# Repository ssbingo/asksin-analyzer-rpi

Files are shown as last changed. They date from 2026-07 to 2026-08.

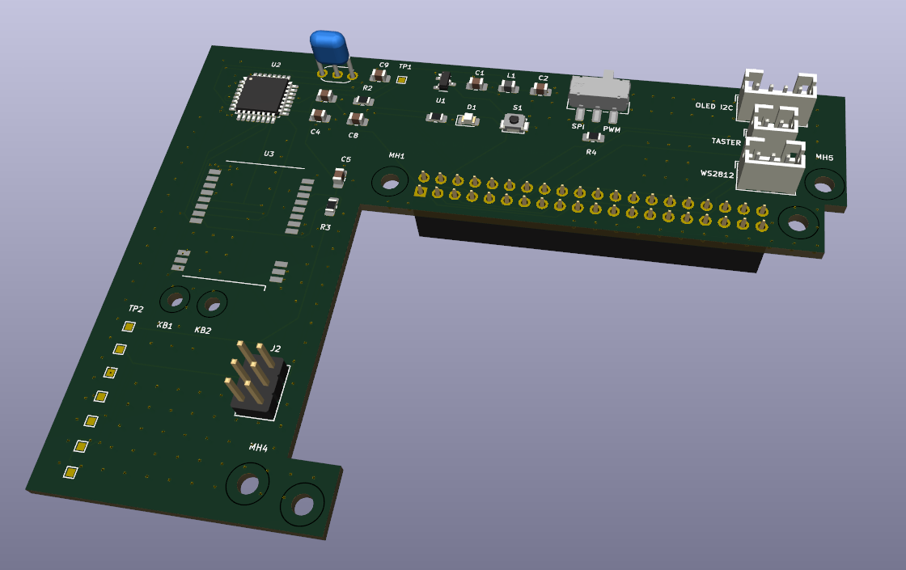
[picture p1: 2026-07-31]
docs/handbuch/img/deckblatt.png

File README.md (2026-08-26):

# AskSin-Analyzer

Ein dauerhaft laufender **Funkanalyzer für Homematic (BidCoS, 868 MHz)** auf
Raspberry-Pi-Basis: eine eigene Empfängerplatine hört den Funkverkehr passiv
mit, ein Node.js-Dienst auf dem Pi wertet aus (Duty-Cycle, RSSI,
Telegrammraten), eine Web-UI zeigt an, und ein ioBroker-Adapter spiegelt die
Ergebnisse in die Hausautomation. Mehrere Geräte an verschiedenen Standorten
im Haus sind ausdrücklich vorgesehen.

📖 **[Handbuch (PDF)](docs/handbuch/AskSin-Analyzer-Handbuch.pdf)** — die
anfängertaugliche Schritt-für-Schritt-Anleitung vom Platinenbestellen bis zum
laufenden Gerät.

> ### ⚠️ Platinen mit „HW v0.0.1" im Bestückungsdruck
>
> Bei diesen ist die 2×20-Buchse J1 gespiegelt — direkt aufgesteckt liegt
> jedes Pad auf dem falschen Pi-Pin (5 V auf 3,3 V, Masse auf GPIOs).
> **Nicht ohne den [J1-Rettungsadapter](hardware/kicad/adapter/README.md)
> aufstecken und einschalten.** Mit ihm sind sie voll funktionsfähig.
> Ab **v0.2.0** ist der Fehler behoben, und die Platine liegt neben dem Pi
> statt über dessen Buchsen.

## Projektstand

| Baustein | Stand |
| --- | --- |
| **Hardware v0.2.0** (L-Platine neben dem Pi) | ✅ **in Produktion** (31.07.2026) — DRC/ERC 0/0, 26 Fertigungsprüfungen bestanden |
| Fertigungsdaten (Gerber, BOM, CPL, JLCPCB) | ✅ [`hardware/kicad/fab/`](hardware/kicad/fab/) + Archiv |
| J1-Rettungsadapter für die Chargen v0.0.1 | ✅ [`hardware/kicad/adapter/`](hardware/kicad/adapter/README.md) |
| Firmware | ✅ abgewandelte Fassung des `AskSinSniffer328P` (jp112sdl) — läuft auch ohne Funkmodul und meldet dessen Fehlen, [eigenes Repo](https://github.com/ssbingo/asksin-sniffer-firmware); Prüfwerkzeuge in [`firmware/`](firmware/README.md) |
| Firmware, erweiterte Fassung | 🔨 gebaut, wartet auf die Platine — eigenes Repo [`asksin-sniffer-firmware`](https://github.com/ssbingo/asksin-sniffer-firmware): Versionsauskunft, Folgenummer, Prüfsumme, CC1101-Selbsttest. Im Auslieferungszustand Zeichen für Zeichen wie das Original |
| Mitschnitt der Funkstrecke | ✅ Grundlinie vor Firmware-Änderungen, Schalter unter *Wartung* (F1) |
| Core: Parser + Duty-Cycle | ✅ fertig ([`core/`](core/)) |
| Core: Serial-Ingest, SQLite, CCU-Namen, Analyzer | ✅ fertig verdrahtet (M2–M4) |
| Core: REST-API inkl. XS-Kompat-Endpunkten | ✅ fertig, 108 Unit-Tests gesamt (M5) |
| Web-UI (Nachbau, eigener Code, MIT) | ✅ fertig: Vue 3 + ECharts, vom Core ausgeliefert (M5.5) |
| Demo-Modus (simulierte Anlage) | ✅ fertig, Schalter in den Einstellungen (v0.0.3) |
| Update-Pfade (Core-Self-Update, 328P-Flash) | ✅ fertig (M7.5, v0.0.4) |
| Netzwerkeinstellungen über die Web-UI | ✅ gebaut (M7.6) — Praxistest auf dem Pi ausstehend |
| Status-LED + OLED integriert | ✅ Software fertig (M11) — Hardware-Test steht aus ([`docs/status-led-oled.md`](docs/status-led-oled.md)) |
| Einkaufsführer Zubehör (README + Handbuch) | 📋 geplant (M12, [`docs/einkaufsfuehrer.md`](docs/einkaufsfuehrer.md)) |
| Verbund: 5 Analyzer als Gesamtsystem | ✅ komplett: Dashboard, Matrix+Dedup, Flotten-Update, Langzeitdaten nach InfluxDB (M9.1–M9.5, [`docs/verbund.md`](docs/verbund.md)) |
| Langzeitdaten vor Ort (InfluxDB + Grafana) | ✅ optional auf dem Master: Ein-Klick-Einrichtung, acht fertige Grafana-Ansichten, vier Alarme (M14) |
| Bootmedium | SSD ab Pi 4; **der Pi 3 läuft von SD-Karte** (Netzwerk am USB-Bus, nur USB 2.0) |
| CCU-Verbindungstest mit Diagnose | ✅ nennt die Geräteanzahl, unterscheidet sechs Fehlerursachen und blendet bei fehlender Systemvariable die Einrichtung ein ([`ccu/`](ccu/README.md)) |
| Alarmziele: ioBroker, E-Mail, Telegram | ✅ in der WebUI einstellbar, mit Testversand und deutlichen Fehlermeldungen (M14.2) |
| Versionsabhängigkeit Analyzer ↔ Adapter | ✅ beide Seiten weisen sie aus **und prüfen sie** (M15) |
| Protokoll und Absturzsuche (Tab „Wartung“) | ✅ fertig (M13): Stufen, Tagesrotation, Download, Systemjournal ([`docs/protokoll.md`](docs/protokoll.md)) |
| ioBroker-Adapter | 🔨 Grundgerüst steht (M6, eigenes Repo [`ioBroker.asksinanalyzer-rpi`](https://github.com/ssbingo/ioBroker.asksinanalyzer-rpi), MIT, mehrinstanzfähig) |

## Installation auf dem Raspberry Pi

Ein Aufruf installiert und konfiguriert alles (Details: [`deploy/README.md`](deploy/README.md)):

```bash
curl -fsSL https://raw.githubusercontent.com/ssbingo/asksin-analyzer-rpi/main/install.sh | sudo bash
```

## Aufbau des Repositories

```
hardware/                 Platine, Bestelllisten, Setup-Skripte
├── README.md             vollständige Hardware-Spezifikation
├── bestellliste-reichelt.md
├── setup-uart.sh         richtet den Pi-UART ein (Pi 3/4/5)
├── 99-asksin-analyzer.rules   udev: fester Gerätename
├── 3d-druck/             Druckvorlagen 19″-Einbaurahmen (folgen nach Testdruck)
├── datasheets/           Ebyte-E07-Serienspezifikation
└── kicad/                KiCad-9-Projekt, generiert & maschinell geprüft
    ├── generate_*.py     Schaltplan, Layout, Symbole, Footprints, BOM/CPL
    ├── autoroute.py      Freerouting-Anbindung
    ├── rebuild.py       baut die Platine neu, bis alle Prüfungen sauber sind
    ├── adapter/         J1-Rettungsadapter für die Chargen v0.0.1
    ├── fab/             Gerber, Bohrdaten, BOM, CPL, PDFs
    └── AskSin-Analyzer-V3-fertigung.zip   Upload-Paket
core/                     Node.js/TypeScript-Analysedienst
webui/                    Web-UI-Nachbau (Vue 3 + ECharts, MIT)
deploy/                   systemd-Unit, Beispielkonfig, CLI-Wrapper
install.sh / update.sh    Ein-Befehl-Installation und -Update auf dem Pi
docs/
├── serial-protocol.md    das serielle Telegrammformat, verifiziert
├── raspberry-pi-uart.md  UART-Konfiguration Pi 3/4/5
├── webui-und-updates.md  API-Vertrag der Web-UI, Update-Pfade, Lizenzlage
├── verbund.md            Phase M9: fünf Analyzer als Gesamtsystem (Föderation)
├── protokoll.md          Phase M13: Protokoll, Systemjournal, Absturzsuche
├── status-led-oled.md    Phase M11: Status-LED (PWM/SPI) und OLED
└── handbuch/             das Handbuch (HTML-Quelle, Bilder, PDF)
reference/                Originalprojekte (nicht eingecheckt — siehe unten)
```

## Die Kernentscheidungen in einem Absatz

Die Funkseite bleibt beim bewährten Gespann **ATmega328P + CC1101** mit der
unveränderten `AskSinSniffer328P`-Firmware — kein Fork, wer will flasht die
Original-HEX. Die Platine ist ein **L-förmiger** Aufsatz, der auf den
durchgeschleiften Header des PoE-HAT gesteckt wird; der Streifen liegt
**parallel neben dem Pi** an der Header-Seite, höchstens 20 mm breit, und
deckt keine Buchse ab. Der Schenkel steht 32 mm **hinter** der SD-Kante —
dort sitzt das Funkmodul, weit weg vom Störnebel und direkt am rückwärtigen
Antennen-Keystone. Die Antenne verlässt das
Ebyte-Modul per IPEX — auf der Platine existiert **keine einzige HF-Leitung**.
Der bekannte 2,12-%-Baudratenfehler der 8-MHz-Klasse wird nicht in der
Firmware „repariert", sondern auf der Pi-Seite kompensiert: der Port läuft mit
**58824 Baud** (Details: [`hardware/README.md`](hardware/README.md),
Abschnitt 2.5 — das ist Absicht, nicht Tippfehler). Analyse-Software und
ioBroker-Adapter sind getrennt geschnitten, damit der Adapter frei lizenzierbar
und veröffentlichbar bleibt ([`docs/webui-und-updates.md`](docs/webui-und-updates.md),
Abschnitt 4).

## Schnellzugriffe

- **Platine nachbestellen:** `hardware/kicad/AskSin-Analyzer-V3-fertigung.zip`
  hochladen (4 Lagen, 1,6 mm); SMD-Bestückung mit
  `fab/jlcpcb_bom.csv` + `fab/jlcpcb_cpl.csv`
- **Bauteile kaufen:** [`hardware/bestellliste-reichelt.md`](hardware/bestellliste-reichelt.md)
- **Pi einrichten:** `sudo hardware/setup-uart.sh` → Neustart →
  `stty -F /dev/ttyAMA0 57600 raw -echo` — dann die exakte Rate:
  `sudo python3 deploy/baudrate.py /dev/ttyAMA0 58824 && cat -v /dev/ttyAMA0`
  (`stty` kennt nur genormte Raten und lehnt 58824 ab)
- **Core-Tests:** `cd core && npm install && npm run check`

## Versionierung

Ein Repository, drei unabhängige Zählungen über Tag-Präfixe:

| Tag | versioniert | aktuell |
| --- | --- | --- |
| `hardware-vX.Y.Z` | die Platine (Schaltplan, Layout, Fertigungsdaten) | **0.2.0** — steht auch im Bestückungsdruck |
| `core-vX.Y.Z` | die Pi-Software (`core/` + `webui/`, deren `package.json` führen dieselbe Nummer) | **1.2.0** |
| `vX.Y.Z` | den Gesamtstand des Projekts (Doku, Handbuch, Zusammenspiel) | **1.2.0** |

Die **Firmware hat ein eigenes Repository** mit eigener Versionierung:
[ssbingo/asksin-sniffer-firmware](https://github.com/ssbingo/asksin-sniffer-firmware).
Sie war ursprünglich die unveränderte `AskSinSniffer328P` von jp112sdl; seit
den Erweiterungen um Folgenummer, Prüfsumme, Versionsauskunft und
Funkmodul-Selbsttest ist sie eine abgewandelte Fassung und wird als solche
gepflegt — Lizenz unverändert CC BY-NC-SA 3.0. Der ioBroker-Adapter bekommt
ebenfalls ein eigenes Repository mit eigenständiger Versionierung.

## Changelog

### v1.8.0 — 26.08.2026

**Neue Ansicht „Funklast": Wer verbraucht die Sendezeit — und wie viel davon war umsonst?**

Entstanden aus einem echten Fall: Die CCU meldete für ein LAN-Gateway einen
Duty-Cycle über 100 %, und die Ursache zu finden kostete eine Stunde Handarbeit
an der Datenbank. Dieselbe Kette läuft jetzt automatisch — an denselben Daten
gemessen in **53 ms**.

- Die Spalten stehen in der Reihenfolge der Ursachen: **Sendezeit → Bursts →
  Wiederholungen → vergebliche Wiederholungen.** Ein Absender fällt durch
  Sendezeit auf, nicht durch die Zahl der Telegramme; im Fall stieg die Zahl von
  219 auf 345, die Sendezeit aber von 4,6 s auf 30 s.
- **„Vergeblich" kann nur ein Mithörer füllen:** Wiederholungen, obwohl der
  Analyzer die Antwort bereits gehört hatte. Eine Zentrale sieht nur, dass sie
  wiederholen muss — nicht, ob die Antwort unterwegs verloren ging. Steht dort
  eine hohe Zahl, ist der Rückweg das Nadelöhr, und man sucht am Absender statt
  am Gerät.
- **Mehrere Sender unter einer Adresse werden getrennt.** Alle LAN-Gateways
  einer CCU senden mit deren Adresse; auseinanderhalten lässt sie nur die
  Empfangsstärke. Im Fall: zwei Gipfel, 30 dB auseinander, und 78 von 81 Bursts
  aus dem lauten — damit war das schuldige Gateway benannt, unabhängig von der
  CCU-Anzeige.
- Aufklappen zeigt je Gegenstelle die Sendungen je Vorgang, die Bursts, die
  vergeblichen Wiederholungen und wie laut der Analyzer die **Antworten** hört.
  Dazu ein Satz, was zu tun ist — nicht nur, was gemessen wurde.
- Zehn Tests, darunter der komplette Fall als Durchlauf. Zwei Fehler fanden sie
  beim Schreiben: HmIP beginnt bei Typ 0x80 (mein Testwert 0x5E war das
  Leistungstelegramm eines Schaltaktors und prüfte nichts), und ein Gerät, das
  in einem Fenster **nur quittiert**, fiel ganz aus der Liste — seine Sendezeit
  belegt das Band trotzdem.
- Handbuch 13.4 liest den Fall Zeile für Zeile mit; 13.5 und 13.6 rücken auf.

### v1.7.3 — 25.08.2026

**Nachtrag zur „Sammlung": Der Master fragte sich selbst über HTTP.**

In v1.7.2 lief der Master beim Zählen über *alle* Peers — und die Liste enthält
ihn selbst. Sein Aufruf von `/api/langzeitdaten` rief also wieder die Zählung
auf, die wieder sich selbst aufrief. Das endet erst in Zeitüberschreitungen, und
die Kachel zeigte danach wieder einen Strich — aus dem genau umgekehrten Grund
als vorher.

- Der eigene Standort wird jetzt **direkt** genommen, ohne HTTP; nur die
  entfernten Peers werden gefragt.
- Ein Test hält es fest, gegengeprüft.
- Nebenbei die Wortwahl berichtigt: Ein Analyzer ohne Schreibvorgang heißt
  „liefert gerade nicht" statt „seit Längerem still". Direkt nach jeder
  Aktualisierung steht dort für einen Schreibtakt lang auch ein völlig gesundes
  Gerät — beobachtet an Dachboden unmittelbar nach dem Rollout.

### v1.7.2 — 25.08.2026

**„Sammlung" zeigt wieder, wie viele Standorte liefern — statt eines Strichs.**

Gemeldet: „Was sollte eigentlich bei dem Punkt *Sammlung* stehen? Dort ist
bisher nur ein Strich zu finden." Antwort: **3 Standorte**. Dass dort nichts
stand, war ein stiller Fehler aus unserer eigenen Token-Trennung.

Die Zeile zählte die Standorte mit einer Flux-Abfrage. Die lief — bis Grafana
einen **Lese**- und die Analyzer einen **Schreib**-Token bekamen. Seither sieht
ein Analyzer den Bucket nicht mehr, und InfluxDB antwortet nicht mit „verboten",
sondern mit `HTTP 404 could not find bucket`. Der `catch` machte daraus ein
stilles „nicht ermittelbar".

- **Gezählt werden jetzt die Analyzer, nicht die Datenbank.** Jeder weiß über
  sich selbst, ob und wann sein letzter Schreibvorgang geglückt ist; der Master
  fragt der Reihe nach alle ab. Kein Lesezugriff nötig — die Token-Trennung
  bleibt, wie sie ist.
- Der ursprüngliche Anspruch bleibt: **Ein Standort zählt nur, wenn er wirklich
  schreibt.** Fehlt einer, steht dort *2 von 3 Standorten*; wer fehlt, zeigt der
  Mauszeiger.
- Ein Standort gilt erst nach **drei Schreibtakten** ohne Erfolg als still,
  mindestens aber nach fünf Minuten — ein einzelner Aussetzer darf die Anzeige
  nicht flackern lassen.
- `tools/pruefe-influx-lesezugriff.sh` hält fest, dass der Core nicht wieder
  anfängt zu lesen. Gegengeprüft.
- Handbuch 19.6 erklärt die ganze Kachel und warum nicht die Datenbank gefragt
  wird.

### v1.7.1 — 24.08.2026

**Die Clients melden jetzt über den Master.**

Damit fällt die Grenze aus v1.7.0: Bisher meldete sich nur der Master, weil nur
dort ein Alarmziel eingerichtet wird.

- **Der Master holt ab, die Clients senden nicht.** Das folgt der Richtung, die
  der Verbund ohnehin hat: Der Master kennt jeden Client samt Token, die Clients
  kennen den Master nicht. Ein Push bräuchte auf jedem Client Adresse und
  Geheimnis des Masters — neue Einstellungen, die jemand pflegen muss. So kommt
  die Weiterleitung **ohne eine einzige neue Einstellung** aus.
- **In der Nachricht steht der Standort des Clients**, nicht der des Masters.
  Der Master reicht den Text weiter, den der Client selbst gebaut hat.
- **Nichts geht verloren:** Der Client hakt eine Meldung erst ab, wenn der
  Master die Zustellung bestätigt hat. Ist der Master aus, bleibt sie liegen und
  geht beim nächsten Umlauf hinaus. Angestaut wird nichts — es gibt immer nur
  den letzten Lauf.
- **Die Nachricht nennt jetzt das Datum des Laufs**, nicht nur die Dauer: Eine
  verspätete Weiterleitung läse sich sonst so, als sei es eben erst passiert.
- Zwei Tests halten den Vertrag fest: dass beide Seiten die Abhak-Schnittstelle
  gleich verstehen (`httpPost` schickt bewusst keinen Rumpf, die Aktion steht
  in der Abfragezeichenkette), und dass der Master **erst zustellt und dann
  abhakt**. Beides gegengeprüft.

### v1.7.0 — 24.08.2026

**Der Analyzer meldet, wenn eine Systemaktualisierung durchgelaufen ist.**

Auf Wunsch — dritter Schalter im selben Feld. Zugestellt über **dasselbe Ziel,
das schon für die Alarme eingerichtet ist**: ioBroker-Adapter, E-Mail oder
Telegram. Ist dort nichts eingerichtet oder der Versand aus, bleibt der Schalter
ausgegraut, mit dem Hinweis wo man das ändert; ein Schalter, der sich umlegen
lässt und nichts bewirkt, wäre schlimmer als keiner.

- **Der Adapter braucht keine Änderung.** Die Meldung geht im
  Grafana-Webhook-Format hinaus, also in genau der Form, die er für die Alarme
  ohnehin versteht.
- **Erfolg und Fehlschlag** werden gemeldet. Der Fehlschlag ist der wichtigere
  Fall: Ein Gerät, das seit Wochen vergeblich aktualisiert, sieht von außen aus
  wie eines, das brav aktualisiert.
- Die Nachricht nennt Standort, Paketanzahl, Dauer und ob ein Neustart nötig
  ist. War nichts nachzuholen, steht das ausdrücklich da — „0 Pakete" allein
  liesse den Empfänger raten, ob die Meldung abgeschnitten ist.
- **Eine Entwarnung folgt sofort nach.** Sonst bliebe `alarm.aktiv` im Adapter
  dauerhaft auf *wahr*, denn eine abgeschlossene Aktualisierung ist ein Ereignis
  und kein andauernder Zustand. Weitergeleitet wird die Entwarnung nur, wenn man
  das ausdrücklich eingestellt hat — es kommt also genau eine Nachricht an.
- **Übersteht den Neustart des Dienstes mitten im Lauf:** apt rüstet auch
  Pakete auf, die den Analyzer mitnehmen. Welcher Lauf schon gemeldet wurde,
  steht auf der Platte; geprüft wird beim Start und alle 30 Sekunden.
- Handbuch 15.4 zeigt die Nachricht im Wortlaut und erklärt die Entwarnung.

**Grenze:** Alarmziele werden nur auf dem Master eingerichtet — heute meldet
sich deshalb auch nur der Master. Die Clients laufen still.

### v1.6.1 — 24.08.2026

**Die Bestätigung durch systemd blieb leer — die Zweitmeinung hat sich selbst gefunden.**

Der Zeitplan lief korrekt, aber die Zeile „von systemd bestätigt" erschien nie.
Grund: `systemctl show -p NextElapseUSecRealtime` liefert **trotz des Namens
keine Mikrosekunden**, sondern einen formatierten Zeitstempel —
`Mon 2026-08-31 03:09:45 CEST`. Mein Muster suchte dort nach Ziffern und fand
nie welche.

- Gelesen wird jetzt `systemctl list-timers --output=json`: `next` als Zahl,
  dazu die gestartete Unit. Damit ist auch belegbar, dass der Timer die
  *geplante* Unit meint und nicht die manuelle.
- Das Parsen liegt in der getesteten Schicht und wird gegen die **wörtlich
  kopierte** Ausgabe von Analyzer 04 geprüft — nicht gegen eine nachgetippte
  Variante. Genau diese Unterscheidung hat hier schon einmal 20 Stunden
  gekostet.
- Ein Test hält fest, dass das formatierte Feld nicht wieder als Zahlenquelle
  auftaucht.

Nebenbei bestätigt: Die Streuung arbeitet. `list-timers` meldet 03:09:45 für
einen Plan auf 03:00.

### v1.6.0 — 24.08.2026

**Die Systemaktualisierung läuft auf Wunsch nach Zeitplan.**

Täglich, wöchentlich oder monatlich, jeweils mit Uhrzeit — bei wöchentlich dazu
der Wochentag, bei monatlich der Tag. Ausgeführt von einem systemd-Timer, den
der Core aus der Einstellung rendert; ein eigener Zeitplaner im Dienst wäre eine
stille Lücke, denn er liefe nur, solange der Dienst läuft.

- **Klartext-Vorschau unter der Auswahl:** „Läuft jeden Samstag um 03:00 Uhr
  (± bis zu 30 Minuten). Nächster Lauf: Sa, 29.08.2026 — von systemd bestätigt."
  Der Zusatz kommt von der Stelle, die den Lauf wirklich startet, nicht aus der
  Eingabemaske. Fehlt er, ist der Plan nicht angekommen.
- **Der 31. wird benannt statt verboten.** Gemessen an systemd 257: `*-*-31`
  springt von August auf Oktober auf Dezember — September und November fallen
  ersatzlos aus, ohne Meldung. Ab Tag 29 erscheint deshalb ein gelber Hinweis
  mit den betroffenen Monaten. Die Wahl bleibt frei.
- **Streuung bis 30 min** (`RandomizedDelaySec`), damit nicht alle Analyzer
  eines Verbunds zur selben Sekunde losfahren; **Nachholen** (`Persistent`),
  falls das Gerät zur fälligen Zeit aus war.
- **„Danach neu starten, falls nötig"** — nur bei geplanten Läufen, nur bei
  verlangtem Neustart, ab Werk aus. Ein Klick auf *Jetzt aktualisieren* startet
  nie von selbst neu.
- **Die Warnschwelle folgt dem Rhythmus** (3 / 9 / 33 Tage statt fester 7).
  Sonst stünde bei „monatlich" drei Wochen im Monat eine Warnung, obwohl alles
  nach Plan läuft — und wer sie gewohnheitsmäßig übersieht, übersieht auch die,
  die zählt. Der Text unterscheidet die Fälle: „ein geplanter Lauf scheint
  ausgefallen zu sein" statt „bitte bald nachholen".
- Der geplante Lauf hat eine **eigene Unit** (`…-systemupdate-geplant.service`),
  damit nur dort ein automatischer Neustart herauskommen kann; ein `flock` im
  Helfer verhindert, dass Timer und Knopfdruck sich überschneiden.
- Handbuch 15.4 erklärt Rhythmen, den 31., Streuung, Nachholen und die
  Warnschwellen-Tabelle.

### v1.5.0 — 24.08.2026

**Das Betriebssystem lässt sich aus der Weboberfläche aktualisieren.**

Unter *Wartung → Systemaktualisierung*: ein Knopf, der `apt-get update` und
`apt-get full-upgrade` ausführt. Der Analyzer läuft dauerhaft, hängt am Netz und
trägt einen Webserver — ein Gerät mit diesen drei Eigenschaften muss seine
Sicherheitsaktualisierungen bekommen, und der Weg dorthin darf nicht die Konsole
sein.

- **Man sieht, was läuft:** Paketlisten holen → aufrüsten → aufräumen, dazu die
  Ausgabe von apt wörtlich. Während eines Laufs fragt die Seite alle zwei
  Sekunden nach statt alle fünfzehn.
- **Zeitstempel des letzten Erfolgs** darunter; ab **7 Tagen** wird der Hinweis
  gelb. „Noch nie aktualisiert" ist eine eigene Stufe — bei einem frisch
  aufgesetzten Gerät ist das der Normalzustand und kein Versäumnis.
- Der Erfolgszeitpunkt liegt in einer **eigenen Datei**: Ein späterer
  Fehlversuch überschreibt ihn nicht, sonst stünde nach einem Netzausfall
  plötzlich „noch nie" da.
- **Ohne Rückfragen, ohne Konfigurationsverlust:** `DEBIAN_FRONTEND=noninteractive`
  plus `--force-confold`. Ein Gerät im Schrank kann die Frage nach der
  Paketbetreuer-Version niemandem stellen — es bliebe stehen, bis das Zeitlimit
  zuschlägt.
- **Wartet auf die apt-Sperre** (bis 10 min), statt mit „Could not get lock"
  abzubrechen; **lehnt den Start ab**, solange ein Analyzer-Update läuft; **gibt
  nach einer Stunde ohne Lebenszeichen wieder frei**, damit ein Stromausfall
  keine dauerhafte Sperre hinterlässt.
- **Neustart nach Kernel-Update:** Wird einer verlangt, sagt die Seite es und
  bietet den Knopf dazu. Bis jetzt führte der einzige Weg dorthin über einen
  fünf Sekunden langen Druck auf den Taster am Gerät — wer keinen angelötet hat,
  hätte die Konsole gebraucht.
- Handbuch 15.4 erklärt Ablauf, Farbschwelle und was bei Störungen passiert.

**Noch nicht dabei:** die Option „automatisch alle x Tage". Sie ist
vorbehalten — die Mechanik dafür steht bereits, ein systemd-Timer müsste nur
die Auslöserdatei ablegen.

### v1.4.1 — 24.08.2026

**Der Schalter für den Telegramm-Blitz ist jetzt auch zu finden.**

Er kam mit v1.4.0, war aber ein schlichtes Häkchen zwischen den anderen — und
verschwand ganz, solange die Status-LED abgeschaltet war. Ein Schalter, den man
nur findet, wenn man vorher etwas anderes eingeschaltet hat, ist keiner.

- Eigener Schiebeschalter *Telegramme optisch anzeigen* im Feld „Was die LED
  zusätzlich zeigt", unter *Einstellungen → Status-LED & OLED*.
- **Immer sichtbar**, bei abgeschalteter LED ausgegraut mit dem Hinweis warum.
- Dasselbe Bauteil wie bei den Alarmschaltern; die CSS-Klasse heißt jetzt
  neutral `.schalterfeld` statt `.alarmwahl`.
- Am Gerät gegengeprüft: aus → 250 von 250 Abtastungen grün, kein einziges
  Magenta; wieder an → der Blitz kommt zurück.

### v1.4.0 — 24.08.2026

**Die Status-LED blitzt bei jedem Telegramm magenta.**

Anlass: „Auf unserer Platine signalisiert die LED ein eingehendes Telegramm.
Könnte man diesen Impuls parallel an unsere WS2812 senden?" — Ja, aber ohne
Leitung. `D1` hängt an PD4 des ATmega und geht nirgends auf den Pi-Stecker; ein
Abgreifen wäre ein Eingriff an einer Platine in Produktion, und die WS2812 will
ohnehin keinen Pegel, sondern einen auf 800 kHz getakteten Datenstrom. Nötig ist
das auch nicht: Jedes Telegramm, das `D1` blinken lässt, schickt die Firmware im
selben Atemzug über die serielle Leitung zum Pi. Der Impuls ist längst da, nur
als Textzeile.

- Magenta, 90 ms, mit mindestens 210 ms Abstand zum nächsten Blitz. Damit
  leuchtet er höchstens 43 % der Zeit und die Grundfarbe geht auch bei viel
  Verkehr nicht unter — gerade ein Gerät mit Duty-Cycle-Alarm sendet viel, und
  dann muss die LED rot bleiben.
- Magenta ist die einzige Farbe, die in der Prioritätsleiter nicht vorkommt:
  Die anderen sagen etwas über den *Zustand*, der Blitz über den *Verkehr*. Ein
  Test hält fest, dass keine Zustandsfarbe je magenta wird.
- Abschaltbar unter *Einstellungen → Status-LED & OLED*; ab Werk an.
- Die LED-Schleife läuft dafür mit 40 statt 250 ms, die Grundfarbe wird aber
  weiterhin nur alle 250 ms nachgerechnet. Ohne diese Trennung baute `daten()`
  fünfundzwanzigmal je Sekunde die ganze Geräteliste samt CCU-Abgleich neu auf
  — der Test misst die Aufrufrate mit, gegengeprüft.
- Handbuch 18.2 erklärt Farbe, Timing und warum keine Leitung nötig ist.

### v1.3.1 — 23.08.2026

**Neue systemd-Units kamen erst beim übernächsten Update an.**

Gefunden beim Ausrollen von v1.3.0: Auf dem Master fehlten hinterher beide
Units der Alarmschalter. Die Schalter ließen sich umlegen, und nichts geschah —
es sah aus wie ein Fehler in der neuen Funktion und war einer im
Aktualisierungsweg.

`update.sh` ruft `installiere_dateien` zwar nach dem Git-Pull auf, aber Bash
hat den Rumpf der Funktion da längst gelesen — aus der Fassung *davor*. Alles,
was eine neue Fassung dort zusätzlich tut, blieb deshalb liegen.

- Nach dem Pull läuft das Skript mit der neuen Fassung weiter (`exec`, gegen
  Schleifen abgesichert; der Ausgangsstand wird durchgereicht, damit die zweite
  Fassung sich nicht für „bereits aktuell" hält).
- `tools/pruefe-units.sh` prüft das mit — gegengeprüft.
- Betrifft rückwirkend jede Unit seit dem ersten Update: Wer je eine Funktion
  vermisst hat, für die eine Unit nötig war, hatte womöglich diesen Fall.

### v1.3.0 — 23.08.2026

**Jeder Alarm hat jetzt einen eigenen Schalter.**

Anlass: „Die Meldung über 24 h nicht erreichbare Geräte war gestern Abend sehr
störend, zumal man ja auch nicht jeden Tag jeden Schalter betätigt oder jedes
Fenster öffnet." Ein Fenster, das den Winter über zu bleibt, ist kein Befund —
und eine Meldung, die man jeden Abend wegwischt, bringt einem bei, Meldungen
wegzuwischen.

- Unter *Einstellungen → Alarme: wohin melden?* steht direkt unter *Alarme
  verschicken* für jeden der vier Alarme ein Schiebeschalter. Gespeichert wird
  von selbst, anderthalb Sekunden nach dem letzten Klick — sonst startete
  Grafana bei vier Klicks viermal neu.
- „Aus" heißt in Grafana **pausiert**: Die Regel bleibt sichtbar und ist als
  pausiert gekennzeichnet, wird aber nicht mehr ausgewertet. Eine Regel
  weiterlaufen zu lassen und ihre Meldung unterwegs zu verwerfen sähe von außen
  normal aus — und niemand fände je den Grund für die ausbleibende Nachricht.
- **Die Schalter überstehen eine Aktualisierung.** Das war die eigentliche
  Arbeit: `update.sh` kopierte die Regeldatei bisher roh aus dem Projekt und
  hätte jeden abgeschalteten Alarm stillschweigend wieder eingeschaltet. Alle
  Skripte gehen jetzt durch `core/bin/alarme-rendern.ts`, das der frischen
  Vorlage die gespeicherten Schalter beilegt. `tools/pruefe-alarmschalter.py`
  hält das fest — gegengeprüft.
- `/api/alarme` liefert und nimmt die Schalter; neu sind `Schiebeschalter.vue`,
  der Root-Helfer `alarmschalter-anwenden.sh` und seine beiden Units.
- Handbuch 19.9 erklärt, bei welchem Alarm ein Abschalten sinnvoll ist und bei
  welchem nicht (bei *Analyzer offline*: eigentlich nie).

### v1.2.0 — 21.08.2026

**Fremde Adressen sind in der Telegrammliste als solche gekennzeichnet.**

Anlass: In der Liste tauchte `AF09FE` auf, und die Frage lautete „was ist das
für ein Gerät?". Die Antwort war: keins von deinen — die Adresse steht nicht
in der Geräteliste der Zentrale, es ist eine fremde Anlage in Funkreichweite.

- Neben Absender und Empfänger steht jetzt eine kleine Marke **fremd**, wenn
  die Zentrale die Adresse nicht kennt.
- `/api/telegrams` liefert dafür `fromFremd` und `toFremd`.
- **Ohne Geräteliste wird nichts als fremd behauptet** — ein Verdacht ohne
  Grundlage wäre schlimmer als keine Kennzeichnung. Getestet.
- Handbuch 13.3 erklärt die Marke und wo die Grenze liegt: Das *Modell* eines
  fremden HmIP-Geräts ist aus dem Funk nicht bestimmbar (verschlüsselt); bei
  klassischem BidCoS verrät es das Anlern-Telegramm.

### v1.1.5 — 21.08.2026

**Der DatasourceError ist gefunden — und es war nie ein Analyzer.**

Grafanas Ausdrucksauswertung verlangt eine **wide series**; drei der vier
Alarmabfragen lieferten eine **long series**:

```
[sse.readDataError] [A] got error: input data must be a wide series
but got type long
```

Es ist dieselbe Unterscheidung wie beim `duplicate` einen Tag zuvor, nur mit
umgekehrtem Vorzeichen: `last()`, `max()` und `min()` **wählen eine Zeile aus**
und behalten dabei alle Spalten — auch `_field` und `_measurement`. Mehrere
Textspalten heißen für Grafana „long". `mean()` fasst zusammen und lässt sie
fallen; deshalb lief ausgerechnet die Grundrauschen-Regel als einzige.

- Jede Abfrage endet jetzt mit `keep(columns: […])` und lässt nur Zeit, Wert
  und den Gruppenschlüssel stehen. Nachgemessen: alle vier **wide**.
- Neue Prüfung `tools/pruefe-alarm-form.py`.

### v1.1.4 — 21.08.2026

* (ssbingo) Die Fallunterscheidung in den Alarmmeldungen fragte das falsche Etikett ab (`rulename`), das Grafana bei Fehlalarmen gar nicht setzt — der Text fiel deshalb immer in den Normalfall. Gemessen an einer echten Meldung: Grafana setzt `alertname` auf `DatasourceError` beziehungsweise `DatasourceNoData`. Darauf wird jetzt geprüft.

### v1.1.3 — 21.08.2026

* (ssbingo) Die Alarmmeldungen unterscheiden jetzt **drei** Fälle statt zwei: echter Alarm (mit Standort), **„keine Daten"** (Abfrage lief, brachte nichts) und **„Abfrage fehlgeschlagen"**. Die beiden letzten fielen bisher in einen Topf — und genau das lässt offen, welche Arbeit ansteht: nachsehen, warum nichts ankommt, oder nachsehen, warum Grafana nicht abfragen kann.

### v1.1.2 — 21.08.2026

**Die Alarmregel „Grundrauschen" ließ sich seit dem 20.08. gar nicht mehr übersetzen — durch meine eigene Korrektur.**

- Beim Beheben des DatasourceError hatte ich die Begründung **in** die
  Flux-Abfrage geschrieben, mit `#` am Zeilenanfang. **Flux kennt kein `#`**;
  der Kommentar dort heißt `//`. Ergebnis:
  `compilation failed: invalid statement: #` — **472-mal in zwanzig Stunden**,
  gemeldet als derselbe DatasourceError wie zuvor.
- Der Kommentar steht jetzt auf YAML-Ebene, außerhalb der Abfrage.
- **Alle vier Alarmabfragen wurden diesmal im ausgelieferten Wortlaut gegen
  die Datenbank geprüft** — 15 bis 148 ms, alle mit Daten. Genau das hatte
  ich beim ersten Mal versäumt: geprüft war eine von Hand nachgebaute Fassung,
  ausgeliefert eine andere.
- Neue Prüfung `tools/pruefe-flux-syntax.py`: kein `#` in einer Flux-Abfrage,
  ausgeglichene Klammern. 69 Abfragen werden geprüft.

### v1.1.1 — 20.08.2026

* (ssbingo) Die Zigbee-Matrix im Verbund sieht jetzt aus wie die BidCoS-Matrix: Ihre Tabelle stand ohne `class="daten"` da und hatte deshalb weder Zellabstände noch Trennlinien noch waagerechten Rollbalken — die Spaltenköpfe klebten aneinander.
* (ssbingo) Die eigene Spalte „bester Standort" ist entfallen; der beste Empfang wird wie bei BidCoS mit **★** am Wert markiert. Bei drei Standorten war die Spalte breiter als die Werte, die sie erklärte.
* (ssbingo) Eigene Spalte für die Kurzadresse, wie bei BidCoS.

### v1.1.0 — 20.08.2026

**Die eigentliche Ursache der Überlast — und zwei Ansichten statt einer.**

- `contains(value: r.standort, set: …)` stand **39-mal** in acht Vorlagen.
  InfluxDB kann das nicht in die Speicherschicht hineinschieben: Es liest
  zuerst alles und wirft danach weg. Als regulärer Ausdruck geschrieben,
  dieselbe Abfrage, dasselbe Ergebnis (89 111 Zeilen): **12 731 ms → 236 ms**.
  Bei einem einzelnen Gerät sogar 11 418 ms → 21 ms.
- **Funkqualität (Auswahl)**: Auswahlfeld für Geräte, Vorgabe die zwanzig
  schwächsten (umstellbar auf 10 oder 50). Ein Diagramm mit zweihundert Linien
  ist keines, das man lesen kann. Gemessen: Variable 153 ms, Panel 35 ms.
- **Funkqualität je Standort** (neu): dieselben Messwerte je Standort
  verdichtet — Mittel, schwächstes Gerät, Schwankung. Drei Linien statt
  zweihundert. Zweistufig gerechnet (erst je Gerät, dann je Standort):
  5620 ms → 841 ms.
- Neue Prüfung `tools/pruefe-flux-pushdown.py`: kein `contains()` mehr in
  einer Dashboard-Abfrage.

### v1.0.11 — 20.08.2026

**Ein Grafana-Dashboard konnte den Master lahmlegen.**

Reproduzierbar durch Aufrufen von *Funkqualität*: Ping ging, alle Ports waren
offen, aber kein Prozess antwortete mehr; die Last stieg binnen sieben Minuten
von 0,1 auf 16,3.

- Gemessen: **eine** der Abfragen lieferte **447 352 Zeilen** (rund 200 Reihen
  × 1440 Minutenfenster über 24 h), eine einzige `stddev`-Abfrage trieb die
  Last allein auf 10 — und das Dashboard führte **alle 30 Sekunden drei
  davon** aus. Die Abfrage brauchte länger als der Takt, in dem sie wiederholt
  wurde; InfluxDB protokollierte reihenweise `context canceled`.
- Behoben: Aktualisierungstakt passend zum Zeitbereich (24 h → 5 min statt
  30 s) und `maxDataPoints` auf allen Zeitreihen-Panels. Neun Vorlagen
  betroffen, nicht nur die eine.
- Neue maschinelle Prüfung `tools/pruefe-dashboard-last.py`: Sie schlägt an,
  wenn ein Dashboard schneller taktet, als seine Abfrage fertig wird, oder ein
  Zeitreihen-Panel keine Obergrenze hat.

### v1.0.10 — 20.08.2026

* (ssbingo) Zahlenspalten: Überschrift und Werte stehen wieder untereinander. `table.daten th` (Klasse + zwei Elemente) wog schwerer als `th.num` (Klasse + ein Element) — die Werte standen rechtsbündig, die Überschriften darüber linksbündig. Betraf Telegrammliste, Übersicht und die Verbund-Matrix.
* (ssbingo) Die Zigbee-Matrix richtet ihre Zahlen jetzt wie die BidCoS-Matrix aus.

### v1.0.9 — 20.08.2026

**Getrennte InfluxDB-Tokens: Grafana liest, die Analyzer schreiben.**

- Bisher bediente **ein** Allzweck-Token mit vollen Rechten drei Analyzer und
  Grafana. Zusammen mit dem Protokollier-Fehler aus 1.0.8 lag damit ein Token,
  der alles darf, tausendfach lesbar im Journal.
- Neue Installationen erzeugen jetzt zwei eng geschnittene Tokens: einen
  **Lese**-Token für Grafana und einen **Schreib**-Token für die Analyzer,
  beide nur auf den Bucket `asksin`. Der Allzweck-Token bleibt der Verwaltung
  vorbehalten.
- Klappt das Erzeugen nicht, wird gewarnt und wie bisher verfahren — eine
  Einrichtung soll daran nicht scheitern.

### v1.0.8 — 20.08.2026

**Der InfluxDB-Token steht nicht mehr im Systemjournal.**

- Das InfluxDB-Plugin von Grafana protokolliert bei jeder Abfrage die
  entschlüsselten Datenquellen-Einstellungen. Auf Analyzer 01 gemessen:
  **2393 Kopien des Tokens in 48 Stunden**, das Journal reichte zehn Tage
  zurück.
- Grafanas `[log] level` und `[log] filters` helfen nicht — die Zeilen gehen
  an Grafanas Protokoll vorbei. Beides ausprobiert und gemessen.
- Behoben mit `LogFilterPatterns` in einem systemd-Drop-in: von sechs
  Vorkommen je fünf Minuten auf **null**, während Grafanas eigene Zeilen und
  die Alarmauswertung unverändert weiterlaufen.
- **Wer das nachträglich einspielt, sollte den Token neu erzeugen** — was
  schon im Journal steht, holt der Filter nicht zurück.

### v1.0.7 — 20.08.2026

**Der Alarm „DatasourceError" hörte auf, und er sagt jetzt, was er meint.**

- Ursache: In der Regel *Grundrauschen dauerhaft erhöht* wirft `mean()` die
  Zeitspalte weg — anders als `last()`, `max()` und `min()`, die eine Zeile
  auswählen und deren Zeitstempel behalten. Ohne `_time` hält Grafana das
  Ergebnis für keine Zeitreihe, verwirft es und meldet DatasourceError.
  Behoben mit `duplicate(column: "_stop", as: "_time")`.
- Eine gescheiterte Abfrage schreibt jetzt ausdrücklich, dass **kein Analyzer
  ausgefallen** ist — vorher stand dort derselbe Text wie bei einem echten
  Ausfall, ohne Standort, und niemand konnte die beiden unterscheiden.

### v1.0.6 — 19.08.2026

* (ssbingo) Der Grafana-Knopf steht jetzt links neben den Anzeigen statt dahinter — die Statuspunkte bleiben am rechten Rand zusammen.

### v1.0.5 — 19.08.2026

**Grafana-Knopf in der Kopfzeile des Masters.**

- Öffnet die Grafana-Oberfläche in einem neuen Tab. Nur auf dem Master, und
  nur wenn Grafana dort installiert ist.
- Das Zeichen ist **selbst gezeichnet**: Das Grafana-Logo ist eine Marke von
  Grafana Labs und wird hier nicht mitverteilt. Wer es einsetzen möchte, legt
  `webui/public/grafana-logo.svg` ab — es wird dann bevorzugt, ohne
  Codeänderung.

### v1.0.4 — 19.08.2026

**Die Punkte im Übersichtsdiagramm tragen jetzt die Bewertung der Telegrammliste.**

- Grün ab −65 dBm, orange bis −85, rot darunter — dieselben drei Stufen wie in
  der RSSI-Spalte der Liste, aus derselben Tabelle.
- Die Legende ist anklickbar: eine Stufe ausblenden, um die schwachen
  Telegramme allein zu sehen.
- Neue maschinelle Prüfung (`tools/pruefe-rssi-stufen.py`): Sie schlägt an,
  wenn Liste oder Diagramm eigene Schwellen bekommen.

### v1.0.3 — 19.08.2026

**Empfangsbalken in der Kopfzeile — für beide Funknetze.**

- Fünf Stufen wie am Mobiltelefon, neben jedem der beiden Punkte.
- Für BidCoS aus dem **Störabstand** (Nutzsignal minus Grundrauschen) statt
  aus dem blossen Pegel: Der Versatz, mit dem die Firmware den Rohwert des
  CC1101 in dBm umrechnet, ist ein *typischer* Wert des Datenblatts (74 dB) und
  kein für das einzelne Bauteil gemessener. In der Differenz kürzt er sich weg.
- Für Zigbee aus der Verbindungsgüte (LQI), mit Stufen an der gemessenen
  Kante zwischen −86 und −90 dBm.
- Gemittelt über die **Geräte**, nicht über die Telegramme — sonst bestimmte
  der Koordinator allein die Anzeige.
- `/api/health` liefert die Zahlen dahinter mit; der Tooltip nennt sie.

### v1.0.2 — 19.08.2026

**Beide Funknetze auf einen Blick — am Gerät und in der Oberfläche.**

- **Neue Display-Seite 3: Funkstatus.** BidCoS links, Zigbee rechts, getrennt
  durch einen Strich, je mit Haken oder Kreuz. Zwei eigens gezeichnete
  Sinnbilder: eine Scheibe mit ausgespartem Z für Zigbee, ein Sender mit
  beidseitigen Bögen für BidCoS.
- **Zweiter Punkt in der Kopfzeile**: „Zigbee verbunden / getrennt", neben dem
  BidCoS-Punkt — und nur, wo ein Mithörer eingeschaltet ist.
- `/api/health` unterscheidet jetzt `zigbee` (eingeschaltet) von
  `zigbeeVerbunden` (der Stick antwortet auch).
- Vier Zigbee-Kacheln in einer zweiten Reihe der Übersicht.
- Beide Handbücher liegen unter eigenen Routen; auf der Zigbee-Seite steht
  jetzt auch das Zigbee-Handbuch.

### v1.0.1 — 18.08.2026

**Zigbee ist fertig — und der Stick wird auf dem Pi bespielt.**

- Der Analyzer spielt die Sniffer-Firmware **selbst** auf: im Einrichtungsassistenten
  und unter *Einstellungen · Zigbee*. Kein Browser, kein zweiter Rechner, keine
  Konsole. Er verweigert die Arbeit, wenn mehrere SONOFF-Sticks stecken.
- **Verbund · Zigbee**: Empfangsmatrix über alle Standorte, samt „von niemandem
  gehört". Setzt einen Mithörer **auf dem Master** voraus.
- Zehnte Grafana-Ansicht, Zigbee-States im ioBroker-Adapter.
- Behoben: Der Reiter *Einstellungen · Zigbee* hing an `zigbeeAktiv` — bei
  ausgeschaltetem Zigbee gab es damit keinen Weg mehr zum Einschalten.
- Behoben: Ein Analyzer ohne Mithörer meldete auf `/api/zigbee/geraete` eine
  leere Liste mit 200 statt 501 — „ich höre nichts" statt „hier hört niemand mit".
- Das Zigbee-Handbuch ist Kapitel für Kapitel am Gerät nachgeprüft worden.

### v0.20.1 — 17.08.2026

**Das Handbuch hinkte der gestrigen Ausgabe hinterher.** Kapitel 19 erklärt
jede Grafana-Ansicht einzeln — mit schematischer Abbildung, nummerierter
Tabelle und Erklärung. Nach v0.20.0 sprach es an vier Stellen weiterhin von
„acht Ansichten", die Abbildung des Ordners zeigte acht Einträge, die neunte
war nirgends beschrieben, und in 19.2 fehlte das Measurement `geraeteliste`.

Aufgefallen ist es nur, weil jemand nachgefragt hat. Genau das soll nicht der
Prüfweg sein.

- **19.8** hat jetzt den Abschnitt *Verschollene Geräte — wen hört niemand?*
  samt eigener Abbildung, Nummerntabelle und zwei Einordnungen: warum diese
  Ansicht bewusst keine Standort-Auswahl hat, und warum ein „nie gehört" kein
  Beweis für einen Defekt ist.
- **19.2** nennt `geraeteliste` und erklärt in einem Kasten, warum eine
  Geräteliste überhaupt in einer Zeitreihendatenbank steht.
- Die Ordner-Abbildung zeigt neun Einträge; der Zeilenabstand wurde enger,
  damit das Bild dieselbe Höhe behält wie die übrigen acht.
- **`tools/pruefe-dashboards.py`** hält das künftig zusammen: Zu jeder Vorlage
  in `deploy/grafana/dashboards/` muss es eine Abbildung und eine Einbindung
  im Handbuch geben, und die im Text genannte Anzahl muss stimmen. Läuft im
  Prüflauf mit; beide Fehlerfälle sind gegengeprüft.

Handbuch jetzt 130 Seiten.

### v0.20.0 — 16.08.2026

**Grafana-Dashboard „Verschollene Geräte"** — Geräte, die in der CCU stehen
und von **keinem** Analyzer im Verbund je gehört wurden.

Das ging bisher grundsätzlich nicht, und zwar aus einem Grund, der leicht zu
übersehen ist: **Ein nie gehörtes Gerät hinterlässt in einer
Zeitreihendatenbank keine Spur.** Nach der Abwesenheit einer Zeitreihe kann
man nicht suchen. Ohne die Sollmenge ist die Frage nicht zu stellen.

Deshalb schreibt jeder Analyzer sie jetzt mit: neues Measurement
**`geraeteliste`** (Tags `standort`, `adresse`, `name`, `serial`) mit dem Feld
`jeGehoert` — 1 oder 0, für genau diesen Standort. Damit wird die Auswertung
trivial: nach Adresse gruppieren, Maximum über alle Standorte. Steht dort 0,
hat es im ganzen Verbund niemand gehört. Kein Anti-Join, keine Sonderlogik.

Das Dashboard (`asksin-nie-gehoert`, vier Panels) zeigt:

- **Verschollen** und **In der CCU-Liste** als Kennzahlen
- **Von keinem Analyzer je gehört** — die Arbeitsliste mit Name, Adresse,
  Seriennummer
- **Wer hört wen — je Standort** — eine Matrix. Eine Zeile mit lauter Nullen
  ist ein verschollenes Gerät; eine mit genau einer Eins hängt an einem
  einzigen Analyzer und wird blind, sobald der ausfällt.

Bewusst **ohne Standort-Auswahl**: Ein Gerät gilt erst dann als verschollen,
wenn alle Analyzer schweigen. Mit Filter bekäme man „von diesem einen nicht
gehört" — eine andere und viel harmlosere Aussage.

Geschrieben wird die Liste **alle fünf Minuten**, nicht im Messtakt: Bei über
200 Einträgen wären das sonst rund 700 000 Punkte je Tag und Analyzer, für
eine Menge, die sich nur beim An- oder Ablernen ändert.

### v0.19.0 — 16.08.2026

**Die Übersicht zeigt jetzt auch, was fehlt.** Die Kachel „Geräte (aktiv)"
nannte bisher nur, was gerade zu hören ist. Neu daneben: wie viele reale
Funkgeräte in der CCU-Liste stehen — und wie viele davon **nie** empfangen
wurden.

```
Geräte (aktiv)
11 / 214
3 nie gehört, 211 von 214 aus der CCU-Liste, 5 fremde
```

Das ist beim Ausleuchten einer Anlage die eigentliche Fundstelle: Ein Gerät,
das in der Zentrale steht und nie funkt, hat entweder keinen Empfang, ist
ausgefallen oder wurde ausgebaut, ohne dass es jemand aus der CCU genommen
hat.

- Gezählt werden **nur reale Funkgeräte**. Gruppen (`*Team`), die Zentrale
  selbst und die Pseudoadressen des CCU-Skripts bleiben draußen — eine Gruppe
  hat keinen Sender, und „nie gehört" wäre bei ihr keine Aussage.
- Grundlage ist `device_hours`, also **alles seit Beginn der Aufzeichnung**,
  nicht das Live-Fenster. Die Tabelle unterliegt der Aufbewahrung (Vorgabe
  365 Tage); „nie gehört" heißt streng genommen „nicht im aufbewahrten
  Zeitraum", und das ist die ehrlichere Aussage.
- **Fremde** sind die Gegenrichtung: Absender, die gefunkt haben, aber nicht
  in der Liste stehen — Nachbarschaft, oder ein Gerät, das die CCU nicht
  kennt.
- Ohne Geräteliste erscheint der Vergleich **gar nicht**, statt Nullen zu
  zeigen. „0 nie gehört" ohne Liste wäre keine Aussage, sondern eine Lüge.

### v0.18.0 — 14.08.2026

**Die Selbstheilung aus Firmware 2 hat nicht ausgelöst — und genau das ist
die Auskunft.** Analyzer 01 blieb am 14.08.2026 volle 24 Minuten ohne
Telegramm, während die Rauschzeilen im 750-ms-Takt ungestört weiterliefen.
`empfangErholungen` stand dabei auf **0**: Der Chip war die ganze Zeit auf
Empfang (`MARCSTATE 0x0D`) und lieferte trotzdem nichts.

MARCSTATE allein ist damit zu grob. Es sagt „der Empfänger läuft", nicht „er
hört etwas". Der Registerzugriff war korrekt — AskSinPP liest MARCSTATE an
zwei Stellen genauso —, er misst nur die falsche Sache.

**Firmware 3 meldet deshalb bei Funkstille ihre Lebenszeichen**
(Firmware-Repo `v1.2.0`): `:!RF,…;` nach 60 Sekunden ohne Telegramm, danach
höchstens einmal je Minute, mit vier weiteren Registern des CC1101. Sie
**greift nicht ein** — erst muss feststehen, was der Chip in diesen Minuten
tut. Ein Eingriff auf Verdacht hat in Firmware 2 schon einmal am falschen
Zustand gemessen.

Die Register trennen die möglichen Ursachen:

| Befund | Deutung |
| --- | --- |
| `RXBYTES` > 0 und stehend | Pakete kommen an, niemand holt sie ab — Verdacht auf GDO0 |
| `RXBYTES` 0, `FREQEST` groß | Empfänger steht neben dem Kanal — Verdacht auf Temperaturdrift |
| `RXBYTES` 0, `FREQEST` klein | kein Träger in Reichweite |

Der Analyzer schreibt die Deutung **im Klartext ins Protokoll**, damit sie
niemand im Kopf haben muss:

```
Funkstille seit einer Minute: MARCSTATE 0x0D, Empfangspuffer 0 Byte,
Frequenzablage 3, PKTSTATUS 0x10, LQI 0x7F — kein Traeger in Reichweite.
```

### v0.17.2 — 14.08.2026

**Das Funkmodul lässt sich jetzt bei JLCPCB mitbestücken** — und damit fällt
die anspruchsvollste Lötstelle der Platine weg.

`E07-900M10S`, JLCPCB-Nummer **C9900007000**, Katalogangabe LCC-22,
20,0 × 14,0 mm, Raster 1,27 mm: Maße und Halbloch-Raster stimmen mit unserem
Datenblatt überein, freigegeben für *Economic* und *Standard*. Bisher stand im
Erzeuger der Fertigungsdaten ausdrücklich „nicht im JLCPCB-Katalog"; das gilt
nicht mehr.

- `hardware/kicad/fab/jlcpcb_bom.csv` und `jlcpcb_cpl.csv` enthalten U3.
  JLCPCB übernimmt damit **19 der 24 Bauteile**; von Hand bleiben nur die
  fünf bedrahteten Steckverbinder.
- Fertigungsarchiv neu erzeugt, alle Prüfungen von `pruefe_fertigung.py`
  bestanden. Der Begleittext im Archiv nennt die Position und mahnt die
  Drehlage von U3 an — ein um 180° verdreht bestücktes Modul fällt erst beim
  Flashen auf.
- Zu beachten und dokumentiert: Es ist eine **„JLCPCB Assembly"-Position**
  (nur für PCBA, kein Einzelversand), sie zählt als **Extended**, und
  **Bestand wie Preis sind erst im Bestellportal verbindlich** — die
  Produktseite nennt beides nicht.

**Der Anlass war ein Ausfall.** Am 14.08.2026 ließ sich eine von fünf frisch
gefertigten Platinen nicht programmieren: `target does not answer (0x01)`, bei
jeder Taktrate bis hinunter zu 16 kHz. Ursache war eine Lötbrücke zwischen
Pad 16 (MISO) und Pad 17 (MOSI) des handgelöteten Funkmoduls — benachbarte
Halblöcher im 1,27-mm-Raster. Der Programmierer las dadurch seine eigenen Bits
zurück statt der Antwort des Chips.

Eine Durchgangsprüfung *entlang* der Leitungen findet das nicht; gemessen
werden muss *zwischen* ihnen. **Handbuch 6.2** hat dafür jetzt eine eigene
Prüfung — J2 Pin 1 gegen Pin 4, dort darf kein Durchgang sein — samt der
Erklärung, warum der Fehler so aussieht, wie er aussieht.

### v0.17.1 — 14.08.2026

**Der Firmware-Flash gelang mal beim ersten, mal erst beim zweiten Anlauf.**
Auf Analyzer 01 am 14.08.2026: erster Versuch fehlgeschlagen, zweiter
erfolgreich — gleiche Datei, gleiches Gerät, Bootloader nachweislich
vorhanden. Ein Update, das beim zweiten Mal klappt, ist nicht ausgeliefert.

Die Ursache steht in der Zeitrechnung. urboot lauscht nach dem Reset **genau
eine Sekunde**. Zwischen der fallenden Flanke und dem ersten Sync-Byte lagen
bisher: ein 50-ms-Puls auf HIGH samt Prozessstart, dann der Start von avrdude,
das Öffnen des Ports und das Setzen der Baudrate. Auf einem beschäftigten Pi 5
— inzwischen mit InfluxDB, Verbund und Statusanzeige — reicht das an die
Sekunde heran. Danach redet avrdude mit der laufenden Anwendung statt mit dem
Bootloader.

- **Zwischen Reset und avrdude liegt jetzt nichts mehr.** Der HIGH-Puls, der
  die Flanke für den nächsten Reset vorbereitet, steht davor statt danach; ein
  Test hält fest, dass dort kein Schritt dazwischenrutscht.
- **Drei Anläufe je Protokoll, jeder mit frischem Reset.** Wer das Fenster
  verpasst, dem hilft kein Zuwarten, sondern nur eine neue Flanke.
- Die Leitung wird am Ende wieder auf HIGH gelegt — nach avrdude, wo es
  nichts mehr kostet.

**Und der Befundtext, der uns in die Irre geführt hat, ist korrigiert.** Er
behauptete bei `uP_table does not know mcuid` rundheraus „Auf dem 328P ist
kein Bootloader" und schickte damit zum USBasp. Tatsächlich gibt es zwei
Ursachen, und sie führen an verschiedene Stellen. Der Text nennt jetzt beide
und sagt, woran man sie unterscheidet: sporadisch → verpasstes Zeitfenster,
immer → wirklich kein Bootloader.

### v0.17.0 — 14.08.2026

**Der Empfänger hing, und niemand konnte es sehen.** Analyzer 01 lieferte am
14.08.2026 stundenlang kein einziges Telegramm, während die Rauschzeilen im
750-ms-Takt ungestört weiterliefen. Die Messung war eindeutig: keine
verworfene Zeile, keine verlorene Folgenummer, kein Neustart — die serielle
Strecke war makellos. Nur Pakete kamen keine mehr. Ein Reset des 328P holte
sie sofort zurück.

Das ist die Handschrift eines hängenden CC1101: Das RSSI-Register bleibt
lesbar — daher das ungestörte Rauschen —, aber die Ablaufsteuerung steht nicht
mehr auf Empfang. Ein übergelaufener Empfangspuffer löst sich laut Datenblatt
**nie** von selbst; der Chip bleibt dort, bis jemand `SFRX` schickt. Von
außen war das nicht von einer ruhigen Funkstrecke zu unterscheiden.

**Firmware 2 heilt das selbst** (eigenes Repo, `v1.1.0`): Der ohnehin
laufende 750-ms-Alarm liest zusätzlich `MARCSTATE`. Steht der Chip vier
Abfragen in Folge außerhalb von RX — oder auch nur einmal in
`RXFIFO_OVERFLOW`, das sich nie auflöst —, setzt sie den Empfang neu auf und
meldet den angetroffenen Zustand als `:!RX,…;`. Statt Stunden dauert die
Störung damit unter einer Sekunde, ohne Reset des Mikrocontrollers.

- Der Analyzer versteht die neue Meldung, zählt sie (`empfangErholungen`,
  `letzterEmpfangszustand`) und **schreibt jeden Eingriff ins Protokoll** —
  im Klartext, mit dem angetroffenen Zustand. Ein Gerät, das sich
  stillschweigend selbst heilt, verbirgt einen Hardwarefehler.
- Ebenso im Protokoll: der Neustart der Firmware samt Auskunft des
  Funkmoduls.

**Aufspielen:** *Info → Sniffer-Firmware*, Datei
`asksin-sniffer-firmware/hex/asksin-sniffer.ino.hex`. Das Protokoll bleibt
bei 1 — ältere Analyzer verwerfen die neue Zeile wie jede andere Antwort und
verlieren nichts.

### v0.16.2 — 14.08.2026

**Nach einem Neustart der Firmware lief sie in der einfachen Betriebsart
weiter — und niemand merkte es.**

Der 328P kann neu starten, ohne dass die serielle Verbindung abreißt: beim
Zurücksetzen über GPIO4, nach einem Watchdog, nach einem Spannungseinbruch.
Die Befehle `:?;` und `:E1;` schickte der Core aber nur **einmal je
Verbindung**. Danach kamen keine Folgenummern und keine Prüfsummen mehr —
die Verlusterkennung war still gestorben.

Am 14.08.2026 an Analyzer 01 gemessen: Nach einem Reset stand `Folge: gesehen`
fest auf 76, während `Zeilen` weiterlief.

- Die Startmeldung `:!CC,…;` kommt ungefragt nach jedem Hochlaufen der
  Firmware. Der Core wertet sie jetzt als das aus, was sie ist — „ich bin neu
  gestartet" — und schaltet die Erweiterung erneut frei.
- Neu in den Kennzahlen: **`firmwareNeustarts`**. Steht die Zahl still, lief
  der 328P durch; wächst sie, ist er neu hochgelaufen. Vorher war ein
  Neustart der Firmware von außen überhaupt nicht zu sehen.

### v0.16.1 — 14.08.2026

**Die Übersicht zeigte eine halbe Stunde Telegramme und behauptete drei
Stunden.** Im Diagramm laufen zwei Reihen nebeneinander, und sie waren
unterschiedlich begrenzt: das Grundrauschen nach **Zeit**
(`/api/noise?minutes=180`), die Telegramme nach **Anzahl** — die neuesten 500,
ohne jeden Zeitbezug.

Bei 16 Telegrammen je Minute sind 500 Stück genau 31 Minuten. Das sah aus wie
eine Funkstille bis kurz vor der Gegenwart, war aber nur ein zu kurz geholtes
Fenster: Die Telegramme lagen längst in der Datenbank.

- `/api/telegrams` kennt jetzt **`minutes`** und grenzt damit nach Zeit ein.
  Ohne die Angabe bleibt es beim bisherigen Verhalten — für die
  Telegrammliste ist „die neuesten n" das Richtige.
- Die Übersicht holt beide Reihen über **dieselbe Konstante**, damit sie beim
  nächsten Ändern nicht wieder auseinanderlaufen. Beschnitten wird im Browser
  nach Zeit statt nach Anzahl; sonst schrumpft das Fenster, je mehr gefunkt
  wird.
- Greift die Obergrenze (5000), sagt die Antwort es (`gekuerzt`), und die
  Unterschrift schreibt es dazu. Ein gekürztes Fenster darf nicht aussehen
  wie ein leeres Funkband — genau diese Verwechslung war der Anlass.

### v0.16.0 — 13.08.2026

**Das Speicherleck: sechs vergessene HTTP-Antworten, eine davon im
30-Sekunden-Takt.**

Der Speicher des Dienstes wuchs im Dauerbetrieb gleichmäßig um rund 9 MB je
Stunde — auf Analyzer 01 von 118 auf 379 MB in 70 Stunden, ohne Zusammenhang
mit Last oder Telegrammaufkommen. Gleichmäßig über die Zeit und unabhängig von
der Arbeit: Das passt zu einem Zeittakt und zu nichts sonst.

Die Ursache: Wer eine Antwort holt und ihren Körper nicht liest, gibt sie
nicht frei. Undici hält die Verbindung samt gepuffertem Körper fest, bis er
gelesen oder verworfen wurde. Dem Aufrufer sieht man das nicht an — der Code
wirkt vollständig, es fehlt nur der Satz, der nicht dasteht. Besonders gern
fehlte er im **Fehlerpfad**, wo vor dem Lesen geworfen wurde.

- **`core/src/net/holen.ts`** ist jetzt der einzige Weg nach draußen. Er liest
  den Körper immer zu Ende, auch bei Fehlerstatus, auch wenn der Aufrufer ihn
  nicht braucht. Alle sechs Stellen gehen darüber: InfluxDB (Schreiben und
  Standort-Abfrage), Verbund (Abruf und Kommando), CCU-Geräteliste,
  Adapter-Versionsprüfung, Alarmzustellung.
- **`tools/pruefe-fetch.py`** sorgt dafür, dass daneben kein zweiter entsteht.

**Und der Speicher lässt sich künftig zuordnen, statt ihn zu suchen.** Die
Systemzeile im Protokoll nennt alle 15 Minuten nicht mehr nur den Gesamtwert,
sondern auch Heap, externen Speicher, Puffer und die Zahl offener
Deskriptoren. Damit ist beim Überfliegen zu sehen, *was* wächst — JS-Objekte,
native Puffer oder etwas ausserhalb von Node. Das entscheidet, ob ein
Heap-Schnappschuss überhaupt weiterhilft.

```
Temperatur 47.4 °C · Speicher frei 1255 MB · Last 0.00 · Laufzeit 8.2 h ·
Prozess 186 MB (Heap 61, extern 4, Puffer 2) · 47 Deskriptoren
```

### v0.15.12 — 13.08.2026

**Zwei Fehler aus dem Dauerbetrieb, gefunden im Protokoll von Analyzer 01.**

**Ein Stromausfall machte das Systemprotokoll dauerhaft unlesbar.** Der
Journal-Cursor wird über Dienst-Neustarts hinweg in einer Datei gehalten.
Bricht während des Schreibens der Strom weg, steht dort anschließend die
richtige Länge — aber lauter **Nullbytes**; ext4 hatte die Daten noch nicht
hinausgeschrieben. `String.trim()` entfernt Nullbytes nicht, der Wert kam also
durch bis in die Befehlszeile:

```
The argument 'args[9]' must be a string without null bytes
```

Das stand danach **minütlich** im Protokoll und heilte nie von selbst, weil
derselbe kaputte Wert immer wieder gelesen wurde.

- Der Cursor wird beim Setzen geprüft — druckbares ASCII, sonst verworfen.
- Geschrieben wird jetzt daneben und dann umbenannt. Ein Umbenennen ist
  unteilbar, und ext4 schiebt die Daten dabei vorher hinaus.

**Jedes Herunterfahren endete mit einem Absturzbericht.** systemd schickt
SIGTERM an die ganze Kontrollgruppe, also auch an den WS2812-Helfer. Der Core
schrieb danach noch einen letzten schwarzen Rahmen — in eine Leitung, die
niemand mehr liest. Ein `error`-Ereignis auf einem Strom ohne Zuhörer wird zur
unbehandelten Ausnahme: `Error: write EPIPE`.

- Fehler-Zuhörer ergänzt, und zwar an **allen** Strömen von Kindprozessen.
- **`tools/pruefe-stroeme.py`** hält das künftig fest. Die Prüfung fand
  dabei drei weitere Lücken, die noch niemandem aufgefallen waren — darunter
  die Ströme von `avrdude`: Wäre der mitten im Aufspielen gestorben, hätte er
  den Analyzer mitgerissen und die Platine mit halber Firmware zurückgelassen.

Vor diesem Fehlertyp warnt ein Kommentar in `sttyPort.ts` seit dem 10.08.2026
ausdrücklich. Er hat es nicht verhindert; die Prüfung tut es.

### v0.15.11 — 10.08.2026

**Der Analyzer verwarf jede einzelne Zeile — wegen eines Pluszeichens.** Die
erweiterte Firmware hängt an jede Zeile `+NNNNKK` an: Folgenummer und
Prüfsumme. Die Vorgabe (`docs/protokoll.md` der Firmware) deckt damit „alle
Zeichen von `:` bis einschließlich der letzten Ziffer der Folgenummer" ab —
und das `+` liegt in diesem Bereich. Die Firmware summiert schlicht ihren
Ausgabepuffer, in dem es natürlich steht.

Der Analyzer summierte `:72;` und `02AF` und ließ das `+` aus. Er lag damit
bei **jeder** Zeile um genau 43 daneben, den ASCII-Wert von `+`, und verwarf
ausnahmslos alles mit dem Grund `checksum`.

Sichtbar wurde das erst, als Analyzer 01 sein Funkmodul bekam: Auf der
Leitung lagen Telegramme, in der Weboberfläche kam keines an, und die
Firmware-Kachel zählte `Zeilen geprüft 0`. Vorher gab es schlicht nichts zu
verwerfen.

- Die Summe schließt das `+` jetzt ein.
- **Der Test hatte denselben Irrtum.** Er baute seine Zeilen mit genau der
  Formel, gegen die er prüfte, und war deshalb grün, während am Gerät alles
  durchfiel. Dagegen hilft nur eine Quelle von außen: Sieben **echte,
  am Gerät mitgeschnittene Zeilen** sind jetzt Prüfstein — Rauschen wie
  Telegramme, dazu eine absichtlich verfälschte, damit die Prüfung nicht
  bloß abgeschaltet ist.

### v0.15.10 — 10.08.2026

**„LED gestört" bei einwandfrei leuchtender LED.** Der Zustand für die
Weboberfläche wurde als `led === 'ws2812-spi' && keine Fehler` berechnet — der
SPI-Weg stand dort als einzige gültige Betriebsart. Jede PWM-Anlage (Pi 3 und
Pi 4) meldete damit dauerhaft eine Störung, gleichgültig ob die LED leuchtet.

Aufgefallen auf dem Pi 3 in dem Moment, in dem die LED dort zum ersten Mal
lief — vorher gab es keine Gelegenheit, den Widerspruch zu sehen.

- Die Bedingung lautet jetzt `led !== 'aus' && keine Fehler`.
- Zwei Tests halten beide Richtungen fest: PWM und SPI gelten als aktiv,
  `aus` nicht — und nach Fehlversuchen wird die Störung auch wirklich
  gemeldet. Eine Anzeige, die nie anschlägt, ist so wertlos wie eine, die
  immer anschlägt.

### v0.15.9 — 10.08.2026

**Derselbe Fehlertyp noch zweimal, diesmal auf dem PWM-Weg.** Der Core
schreibt die Farbe nach `/run/asksin-analyzer/led-farbe` — er wählt sein
Laufzeitverzeichnis beim Start und nimmt `/var/lib` nur, wenn er in `/run`
nicht schreiben darf. `led-pwm.py` kannte allein diesen Ausweichpfad und
wartete im Normalbetrieb auf eine Datei, die es nie gab. Beide Seiten für
sich fehlerfrei, keine Meldung, dunkle LED.

Dazu: `asksin-analyzer-led.service` deklarierte `RuntimeDirectory=`, läuft
aber als **root** (DMA braucht `/dev/mem`), während die beiden anderen Dienste
als `asksin` laufen. systemd setzt Eigentümer und Rechte eines
`RuntimeDirectory` bei **jedem** Start neu — der Root-Dienst machte das
gemeinsame Austauschverzeichnis damit zu `root:root` und sperrte den Core aus.
Das war der `EACCES` auf `oled-state.json`.

- `led-pwm.py` sucht beide Orte ab, bei jedem Takt neu — `/run` wird beim
  Booten geleert, und die Datei entsteht erst mit der Betriebsart PWM. Findet
  er keine, sagt er es einmal, mit beiden gesuchten Pfaden im Klartext.
- `RuntimeDirectory=` aus dem Root-Dienst entfernt. Angelegt wird das
  Verzeichnis von `asksin-analyzer.service`, auf den er ohnehin wartet.
- **`tools/pruefe-austauschdateien.py`** findet beides künftig ohne Hardware:
  Jeder Helfer, der eine Austauschdatei nutzt, muss `/run` kennen, und kein
  Root-Dienst darf das gemeinsame Verzeichnis in Besitz nehmen. Läuft im
  Prüflauf mit; beide Fälle sind gegengeprüft.

### v0.15.8 — 10.08.2026

**Die Status-LED lief mit 125 MHz statt 2,4 MHz — und blieb deshalb dunkel.**
Der SPI-Takt gehört im Linux-Kern nicht dem Gerät, sondern dem geöffneten
Dateideskriptor: Beim Schließen des letzten Benutzers setzt der Treiber
`speed_hz` auf den Höchstwert des Reglers zurück. Der Core rief `spi-config`
als eigenen Prozess auf — der setzte den Takt und nahm ihn beim Beenden wieder
mit. Geschrieben wurde anschließend mit 125 MHz, also 52-fach zu schnell. Der
komplette Rahmen war nach 0,6 µs durch, die WS2812 sah davon nur einen
Störimpuls.

Von außen war das nicht zu erkennen: Auf der Datenleitung lag ein Signal, die
Verdrahtung war fehlerfrei, `spi-config` meldete keinen Fehler. Gefunden wurde
es erst durch `spi-config -q` bei laufendem Dienst — dort stand
`speed=125000000`.

- **`deploy/ws2812-spi.py`** setzt Takt, Modus und Bitreihenfolge und
  **bleibt offen**, solange die Anzeige läuft. Er liest die Rahmen als Hex je
  Zeile und liest den Takt zurück, statt ihn zu glauben: Weicht er um mehr als
  10 % ab, bricht er mit einer Meldung ab, statt still Falsches zu schreiben.
- **Latch von 213 µs auf 427 µs.** Die alten 64 Nullbytes beriefen sich auf
  die „> 50 µs" der ursprünglichen WS2812B. Die Revision V5 — alles seit etwa
  2020 — verlangt über 280 µs. Der Test rechnet jetzt die Dauer nach, statt
  eine Zahl zu vergleichen.
- **Der Pi 5 kann nicht mehr auf PWM stehen bleiben.** Die Betriebsart kommt
  aus `statusanzeige.json` (Weboberfläche) und **überstimmt** die
  `config.json` — der Installer korrigierte bisher nur letztere. Jetzt fasst
  er beide an, und der Dienst korrigiert es zusätzlich beim Start selbst.

### v0.15.7 — 10.08.2026

**Eine Einstellung, die aussah, als wirke sie, und nichts tat.** Die
Betriebsart der Status-LED lässt sich in der Weboberfläche zwischen SPI und
PWM umstellen. Geschrieben wurde dabei nur die Einstellung — die
Voraussetzungen für PWM schafft bisher ausschließlich der Installer:
`rpi_ws281x`, der Root-Hilfsdienst `asksin-analyzer-led` und abgeschaltetes
Onboard-Audio.

Wer nachträglich umstellte, bekam eine dunkle LED und keine Fehlermeldung: Der
Core schrieb die Farbe korrekt nach `/run/asksin-analyzer/led-farbe`, und es
las sie niemand.

- Der Analyzer prüft jetzt einmal je Minute, ob der Hilfsdienst läuft, und
  meldet ihn — einmal, nicht dauernd — mit dem Befehl zum Nachholen.
- **`deploy/led-pwm-einrichten.sh`** holt die Einrichtung nach: Onboard-Audio
  abschalten, `rpi_ws281x` installieren, Hilfsdienst aktivieren. Es sagt am
  Ende, ob ein Neustart nötig ist und dass SW1 auf PWM stehen muss.
- Handbuch 18 beschreibt den Fall.

### v0.15.6 — 10.08.2026

**Der Taster war nach jedem Neustart tot — bauartbedingt.** Er wird nur
abonniert, wenn der Anzeigedienst wirklich zeichnet; das ist richtig, denn
GPIO17 hat ohne angeschlossenen Taster keinen Ruhepegel und liefert aus
Einstreuung fortlaufend Flanken.

Falsch war, diese Bedingung **einmalig beim Start** zu prüfen. Die Bilddatei
liegt in `/run/asksin-analyzer` — einem tmpfs, das nach jedem Systemstart leer
ist — und der Anzeigedienst startet laut seiner Unit `After=asksin-analyzer`.
Beim Start des Analyzers *kann* die Datei also gar nicht da sein. Geholfen hat
nur ein Neustart des Analyzers von Hand, nachdem der Anzeigedienst gezeichnet
hatte.

Der OLED-Takt zieht die Prüfung jetzt alle 500 ms nach: Sobald das Bild da
ist, kommt der Taster; verstummt der Dienst, wird das Abonnement wieder
gelöst. Der Grund steht weiterhin im Journal, aber nur einmal statt zweimal
pro Sekunde.

### v0.15.5 — 10.08.2026

**Der Befund stand nur im Rückgabewert, nicht im angezeigten Verlauf.** Der
Analyzer erkennt `not in sync: resp=0x3a` und weiß, dass das kein
Übertragungsproblem ist, sondern ein fehlender Bootloader — die Erklärung
erreichte den Anwender aber nicht. Die Oberfläche zeigt den mitlaufenden
Verlauf, und dorthin wurde die Deutung nie geschrieben. Man sah die rohe
avrdude-Meldung und musste selbst wissen, was `0x3a` bedeutet.

Zusätzlich erkannt: `uP_table does not know mcuid …`. Auch das heißt „kein
Bootloader" — avrdude deutet die laufende Ausgabe des Sniffers als Antwort und
errechnet daraus eine Kennung, die es nicht gibt.

Beide Befunde verweisen jetzt auf Handbuch 7.7 und auf
`deploy/bootloader-brennen.sh`.

### v0.15.4 — 10.08.2026

Der Weg zum Bootloader ist jetzt dokumentiert und wiederholbar — er war die
eigentliche Erkenntnis des Tages und stand bisher nirgends.

- **Handbuch 7.7** *Die richtige Reihenfolge*: Bootloader **einmal** über den
  USBasp, Firmware **danach immer** über die Weboberfläche. Mit der
  Begründung, warum ein Programmer-Upload den Bootloader gleich zweifach
  unbrauchbar macht — er löscht ihn (avrdude ohne `-D`) **und** lässt den
  Reset-Vektor ungebogen, den nur `urclock` umbiegt.
- **`deploy/bootloader-brennen.sh`**: brennt urboot vom Pi aus, ohne PC.
  Prüft vorher, ob die Datei überhaupt in den Bootbereich gehört — eine
  verwechselte Firmware würde den Chip sonst leeren und nichts Brauchbares
  hinterlassen. Liest die Fuses mit und sagt am Ende, wie es weitergeht.

urboot selbst wird **nicht** mitgeliefert: Es steht unter der GPL und gehört
seinem Urheber (Stefan Rueger). Das Skript nimmt die Datei aus der
Arduino-Installation als Argument entgegen.

### v0.15.3 — 10.08.2026

**Der Firmware-Flash über die Weboberfläche funktioniert.** Es brauchte zwei
Bedingungen, nicht eine — und beide wurden an echter Hardware durchgemessen,
mit verifiziertem urboot im Flash:

| Baudrate | Reset zuerst, dann avrdude |
| --- | --- |
| 115200 | kein Sync |
| **57600** | **Sync** |
| **19200** | **Sync** |

**Erstens: erst zurücksetzen, dann `avrdude` starten.** urboot betritt seine
Programmierschleife ausschließlich nach einem **externen** Reset (`sbrs r2, 1`
auf `MCUSR`, Bit 1 = `EXTRF`) und löscht `MCUSR` dabei — danach lauscht er
genau eine Sekunde und ist ohne neuen Reset nie wieder erreichbar. In dieser
Sekunde misst er die Baudrate an der **ersten LOW-Phase** auf der Leitung.
Läuft `avrdude` schon und sendet, fällt der Reset mitten in ein Byte, die
Messung geht daneben, und es bleibt bei „not in sync".

Das war der Fehler in v0.14.6: Dort hatte ich die Reihenfolge umgedreht, weil
ich Optiboot vor mir sah — das kennt kein Autobaud und ist gegen einen
laufenden `avrdude` gleichgültig. Gegen urboot ist es der Unterschied zwischen
„geht" und „geht nie".

**Zweitens: 57600 Baud statt der krummen 58 824.** urboot misst selbst, die
Rate muss also nicht zur Firmware passen — bei 8 MHz ist 115200 aber zu
schnell für seine Zählschleife. 57600 ist genormt, passt zusätzlich zu einem
alten Optiboot (2,1 % Abweichung, innerhalb der Toleranz) und braucht keinen
Umweg über `termios2`.

Der Reset-Impuls ist außerdem von 300 auf 50 ms verkürzt: Er entsteht an der
Flanke, die Haltezeit geht nur vom Ein-Sekunden-Fenster ab.

### v0.15.2 — 10.08.2026

**MiniCore schreibt seit Fassung 3 kein Optiboot mehr, sondern urboot** — und
das spricht `urclock` statt STK500v1. In `boards.txt` steht es ausdrücklich:

```text
328.menu.bootloader.uart0.upload.protocol=urclock
...bootloader.file=urboot/…/autobaud/…/urboot_atmega328p_pr_ee_ce.hex
```

Unser `avrdude` lief mit `-c arduino`. Die beiden redeten aneinander vorbei,
und zwar völlig gleichmäßig: An **beiden** Analyzern zehnmal hintereinander
`not in sync: resp=0xa0`. Ein Übertragungsproblem sieht anders aus — dort
wären die Antworten unterschiedlich. Genau diese Gleichmäßigkeit war der
Hinweis.

Der Flash versucht jetzt `urclock` zuerst und `arduino` danach, damit auch
ältere Platinen mit Optiboot bedient werden. Der Analyzer deutet `resp=0xa0`
außerdem selbst und nennt Ursache und Ausweg.

Handbuch 7.5 berichtigt: Dort stand Optiboot; 7.6 kennt das Fehlerbild.

### v0.15.1 — 10.08.2026

Zwei Sperren, aus denen nur der Erfolgsfall herausführte.

**Eine hängengebliebene Update-Sperre ließ sich nur von Hand lösen.**
`update.sh` schreibt `running: true` in die Statusdatei. Wird das Update hart
abgebrochen — abgeschossener Dienst, Stromausfall, Neustart mitten im Lauf —
bleibt der Eintrag stehen, und die Weboberfläche antwortet von da an dauerhaft
mit `HTTP 409`. Herausgeholfen hat nur das Löschen der Datei über die Konsole.

Ein Update, das seit einer halben Stunde keinen Schritt gemeldet hat, gilt
jetzt als steckengeblieben; die Sperre wird dann aufgehoben und der Vorgang
protokolliert. `update.sh` frischt seine Zeitmarke bei jedem Schritt auf, die
Grenze ist also großzügig.

**`systemctl restart` sah aus, als reagiere nichts.** Die Unit hatte kein
`TimeoutStopSec`, also galt die Voreinstellung von **90 Sekunden**: So lange
wartet systemd nach `SIGTERM`, bevor es `SIGKILL` nachschiebt.

Der Anlass war der blockierende `read()` aus v0.15.0. Die Grenze bleibt
trotzdem: Ein Dienst, der sich verhakt, darf niemanden anderthalb Minuten
warten lassen. Zwanzig Sekunden sind für ein geordnetes Herunterfahren um
Größenordnungen mehr als nötig.

Wer noch auf einer älteren Fassung festhängt, kommt so heraus:

```bash
sudo systemctl kill -s KILL asksin-analyzer
sudo systemctl start asksin-analyzer
```

### v0.15.0 — 10.08.2026

**Der serielle Port wird jetzt über einen Kindprozess gelesen, nicht über
einen Dateistrom.** Das ist die Wurzel von allem, was seit v0.14.1 geflickt
wurde — und der Grund, warum jede Reparatur nur das nächste Symptom freilegte.

`fs.createReadStream` auf einer seriellen Schnittstelle lässt sich **nicht
unterbrechen**: Der `read()` hängt im Thread-Pool von libuv, `destroy()` weckt
ihn nicht, kein Abbruchsignal erreicht ihn. An einer stillen Leitung — der
Normalfall — bleibt er dort liegen. Daraus folgte alles auf einmal:

| Symptom | Fassung |
| --- | --- |
| Flash blieb bei „Ingest wird angehalten" stehen | v0.14.1 gab `close()` eine Frist |
| `stop()` hing trotzdem | v0.14.5 gab der Leseschleife ein Abbruchsignal |
| Dienst ließ sich nicht neu starten | der verwaiste `read()` hielt den Prozess |
| `not in sync: resp=0xa0` | der verwaiste Leser nahm avrdude die Antwort des Bootloaders weg |

Die letzten beiden traten auf **beiden** Geräten identisch auf — ein Wettlauf
sähe erratisch aus, gleiches Verhalten heißt gleiche Ursache.

Ein Kindprozess löst es an der Wurzel: Seine Standardausgabe ist eine Pipe,
und Pipes sind vollständig asynchron. Beim Beenden räumt das Betriebssystem
den hängenden `read()` und den Dateideskriptor auf — es gibt nichts mehr,
worauf man vergeblich warten könnte. Es kommt keine Abhängigkeit dazu; `cat`
ist ein Bordwerkzeug, und genau so liefen alle erfolgreichen Handmessungen.

Tests laufen gegen eine echte benannte Pipe und ein echtes `cat`. Die
Gegenprobe zeigt den Unterschied: Der Dateistrom meldet nach `destroy()` kein
`close`, der Kindprozess ist in rund 100 ms weg.

### v0.14.6 — 10.08.2026

**Der Reset kam zu früh — Optiboot lauscht nur eine Sekunde.** Die alte Folge
setzte erst zurück und startete dann `avrdude`. Bis der den Port geöffnet und
die krumme Baudrate über `termios2` gesetzt hatte, war das Fenster zu:
`not in sync: resp=0x00`, niemand antwortet mehr.

Jetzt läuft `avrdude` **zuerst** und der Reset fällt hinein. Damit gibt es
keinen Wettlauf mehr: `avrdude` wiederholt den Sync zehnmal über mehrere
Sekunden, und einer dieser Versuche trifft das Fenster. Das ist der übliche
Weg für Platinen ohne DTR-Leitung.

Nebenwirkung, die richtiggestellt wurde: Der Ausgang hängt jetzt an `avrdude`,
nicht am Zustand der GPIO-Leitung. Lässt sich die Leitung nach dem Impuls
nicht zurückziehen, ist das ein **Hinweis** — die Firmware kann längst
geschrieben sein, und „fehlgeschlagen" wäre schlicht falsch.

### v0.14.5 — 10.08.2026

**Der Flash blieb weiterhin hängen — meine Reparatur aus v0.14.1 saß an der
falschen Stelle.** Dort hat `close()` eine Zeitgrenze bekommen. Die eigentliche
Blockade lag eine Zeile tiefer: `for await (const chunk of stream.readable)`
endet erst, wenn der Strom endet. Gibt `close()` auf, ohne dass der hängende
`read()` zurückkehrt, läuft die Schleife weiter und `stop()` wartet trotzdem
für immer.

Die Leseschleife hört jetzt auf ein eigenes Abbruchsignal, unabhängig davon,
ob der Strom sich schließen lässt. Zusätzlich wartet auch der Verbindungs-
Aufbau nicht mehr unbegrenzt auf ein fremdes `close()` — der Ingest verlässt
sich nicht mehr darauf, dass eine Port-Umsetzung zurückkehrt.

Beides mit Test: ein Strom, der nie etwas liefert und sich nicht schließen
lässt. Gegenprobe ohne Abbruchsignal — der Test hängt bis zur Schranke.

### v0.14.4 — 10.08.2026

**Berichtigung:** Das Handbuch behauptete, *Hochladen mit Programmer* lasse
den Bootloader unversehrt. Das ist falsch. Die Arduino IDE ruft `avrdude`
ohne `-D` auf — und `-D` schaltet das automatische Löschen *ab*, ist also die
Voreinstellung. Der Chip wird vollständig gelöscht, Bootloader eingeschlossen.
Ein ausgeschriebenes `-e` steht nirgends; wer danach sucht, findet nichts und
schließt das Falsche. Genau das war passiert.

Folge: Nach einem Programmer-Upload lässt sich die Firmware **nicht mehr über
die Weboberfläche** aufspielen. Das Fehlerbild ist `not in sync: resp=0x3a` —
und `0x3a` ist das Zeichen `:`, also die laufende Ausgabe des Sniffers statt
einer Antwort des Bootloaders.

Der Analyzer deutet diese Meldung jetzt selbst und nennt Ursache und Ausweg,
statt die rohe avrdude-Ausgabe stehenzulassen. Handbuch 8.2 ist berichtigt und
nennt die richtige Reihenfolge; 7.6 kennt das Fehlerbild.

### v0.14.3 — 10.08.2026

**Die Versionsfrage ging nie hinaus, wenn keine Zeile deutbar war.** Ein
Henne-Ei-Fehler: Die Frage hing an der ersten *gültigen* Zeile. Fehlt das
Funkmodul, liest der SPI-Bus 0x00 oder 0xFF, der Pegel jeder Rauschzeile wird
unplausibel, und der Parser verwirft sie zu Recht — restlos alle. Also wurde
nie gefragt, und ausgerechnet die Auskunft `:!CC,--;`, die das fehlende
Funkmodul benennt, kam nie zustande.

Der Analyzer konnte genau dann nicht fragen, wenn die Antwort am wichtigsten
gewesen wäre.

Das erklärt auch, warum zwei baugleiche Geräte Unterschiedliches meldeten: Das
eine hatte genau **eine** Rauschzeile, die durchkam, und zeigte prompt die
richtige Fassung; das andere hatte null. An diesem Zufall hing die ganze
Anzeige — ein Unterschied in der Firmware bestand nie.

Die Frage hängt jetzt an der ersten Zeile überhaupt, einmal je Sitzung.

### v0.14.2 — 10.08.2026

**Der Analyzer behauptete „Originalfassung", bevor er es wissen konnte.**
Nach einem Dienst-Neustart stand sofort da, es laufe die Originalfirmware;
nach einem Kaltstart stimmte die Anzeige wieder. An der Firmware hatte sich
nichts geändert — nur die vergangene Zeit war eine andere.

`baueFirmwarebefund(null, …)` lieferte unbesehen `original`. Damit war „noch
keine Antwort da" nicht von „es kommt keine" zu unterscheiden. Der Ingest
merkt sich jetzt, wann die Versionsfrage hinausging; der Befund kennt eine
dritte Lage `unbekannt` und wird erst nach drei Sekunden ohne Antwort zur
Auskunft. Die Firmware antwortet in Millisekunden — die Frist ist um
Größenordnungen großzügig.

Damit lässt sich erstmals unterscheiden, ob die Firmware wirklich schweigt
oder die Anzeige nur zu früh urteilt.

### v0.14.1 — 10.08.2026

Zwei Fehler, die erst der erste Firmware-Flash über die Weboberfläche
sichtbar gemacht hat — an zwei Geräten gleichzeitig.

- **Der Flash legte den Dienst lahm.** Im Journal stand „Ingest wird
  angehalten", danach über Stunden nichts. `close()` wartete auf das
  `close`-Ereignis des Lesestroms; `destroy()` beendet den aber nicht, solange
  im Thread-Pool ein blockierendes `read()` auf der seriellen Schnittstelle
  hängt — ohne eingehende Zeichen der Normalfall. Zum Flashen kam es nie.
  `schliesseStrom()` gibt jetzt nach zwei Sekunden auf.
- **Der Flash zeigte keinen Fortschritt.** Er lief in einem einzigen
  HTTP-Aufruf; die Oberfläche schrieb „Flashe …" und wartete bis zum Schluss.
  Jetzt startet `POST /api/update/firmware` nur noch und kehrt sofort zurück,
  `GET /api/update/firmware/stand` liefert den Verlauf — mit dem
  Fortschrittsbalken von `avrdude`.

Nebenbei berichtigt: Die Oberfläche nannte als Beispieldatei noch
`AskSinSniffer328P.hex` und behauptete, im Demo-Modus sei der Flash nicht
verfügbar. Der Code sagt ausdrücklich das Gegenteil.

### v0.14.0 — 09.08.2026

**Die erste Platine läuft.** Analyzer 05 empfängt seit heute echte Zeilen —
davor lief jedes Gerät im Demo-Modus. Dabei kamen vier Fehler ans Licht, die
alle nur an echter Hardware sichtbar werden konnten.

- **Die Firmware war stumm gebaut.** MiniCore setzt `-DNDEBUG`, AskSinPP leert
  daraufhin `DPRINT`, `DPRINTLN` und `DINIT` — und der Sniffer schreibt alles
  darüber. Nicht einmal `Serial.begin()` kam zustande. Behoben in der
  [Firmware](https://github.com/ssbingo/asksin-sniffer-firmware) (v1.0.0);
  gemessen: 8 540 Byte mit Ausgabe, 7 630 ohne.
- **`stty` kann 58824 nicht.** Der Befehl stand an sechs Stellen in der
  Dokumentation, unter anderem im Fehlersuche-Kapitel als *Lösung*. Ersetzt
  durch `deploy/baudrate.py` (`termios2`/`BOTHER`).
- **Der Reset-Impuls auf GPIO4 hatte kein Ende.** `flashFirmware()` ließ die
  Leitung auf LOW liegen; ab dem zweiten Aufruf fand der Reset keine fallende
  Flanke mehr, und `avrdude` lief in `not in sync`.
- **`install.sh` löschte das eigene Arbeitsverzeichnis**, bevor es hinausging.

**Aufgeräumt.** Entfernt wurden die stumme HEX-Datei samt Nachbau-Skript, zwei
PDF-Dubletten, eine byte-gleiche Platinen-Sicherungskopie und zwei
Planungs-PDFs vom 26.07., die noch Arduino Pro Mini, MQTT und microSD
beschrieben. Bei der Platine liegt jetzt ausschließlich der Fertigungsstand
vom 31.07. im Repo.

**Neue harte Prüfungen**, jede mit Gegenprobe: `firmware/pruefe-hex.py` weist
stumm gebaute Firmware zurück, `tools/pruefe-erzeugnisse.py` verbietet
Erzeugnisse, die älter sind als ihre Quelle, Zeichnungen außerhalb von `fab/`
und tote Verweise in der Dokumentation.

**Handbuch** auf 121 Seiten: Kapitel 8 neu (eigene Firmware, drei
Sketch-Dateien, `NDEBUG`), 11.6 *Platine ohne Funkmodul* erstmals
tatsächlich geschrieben, 7.2 und 7.6 um die USBasp-Fallen unter Windows
ergänzt.

### v0.13.0 — 03.08.2026

- Ablage für die Sniffer-Firmware mit maschineller Prüfung; die mitgelieferte
  HEX-Datei ließ sich zunächst nicht reproduzieren — Ursache war die Menüzeile
  *Compiler LTO*, und der FQBN im Handbuch war falsch geschrieben
- **Mitschnitt** des rohen Zeilenstroms: über die Weboberfläche schaltbar,
  herunterladbar, mit Herkunftsvermerk in der Datei, damit Demo-Aufzeichnungen
  nicht mit echten verwechselt werden
- Analyzer-Seite der erweiterten Firmware: Anhang lesen, Lücken rechnen,
  Firmware-Befund erheben
- Demo-Modus gibt keine echte Netzidentität mehr preis; Screenshots neu

### v0.12.2 — 01.08.2026

- Handbuchsatz auf WeasyPrint umgestellt; der Fußsteg verdeckte auf mehreren
  Seiten Text

### v0.12.1 — 01.08.2026

- Der Versionsbefund zum Adapter wird auch im guten Fall ausgesprochen —
  Schweigen war nicht von „nicht geprüft" zu unterscheiden

### v0.12.0 — 01.08.2026

- Versionsabhängigkeit zwischen Core und ioBroker-Adapter
- Rahmen um die Übersichtsblöcke

### v0.11.0 — 01.08.2026

- **Langzeitdaten vor Ort**: InfluxDB und Grafana auf dem Analyzer, Rolle
  Master/Client mit Hardware-Schranke, acht Vorlagen und vier Alarme aus einem
  Generator statt von Hand gepflegt
- **Alarmziele** ioBroker, E-Mail und Telegram als prüfbares Modul, mit
  Testknopf für alle drei Wege
- **Absturzursache gefunden**: Der Pi 5 deckelt USB auf 600 mA, die SSD meldet
  sich daraufhin vom Bus ab. Die zunächst verdächtigte Stromversorgung wurde
  durch Messung entlastet und die Doku berichtigt
- `asksin-analyzer token` zeigt den Auth-Token

### v0.10.0 — 31.07.2026

- **Netz-Mitschnitt für die Absturzsuche**: Kernel-Meldungen übers Netz
  mitschneiden, mit Pulsschlag — damit Stille etwas bedeutet
- Absturzbericht um Datenträger-Anbindung, SMART und ausgehandelte
  USB-Geschwindigkeit erweitert
- Handbuch: feste Grundregel für Seitenumbrüche, Fußzeile mit Weg zum Inhalt,
  Inhaltsverzeichnis springt direkt zum Kapitel

### v0.9.0 — 31.07.2026

Die Anzeige am Gerät ist keine Eigenkonstruktion mehr, sondern die des
Vorbilds — mit dessen Bibliotheken, Schriften und Maßen.

**OLED: übernommen statt nachgebaut**
- Gezeichnet wird im eigenen Dienst `asksin-analyzer-oled` mit
  `adafruit_ssd1306`, Pillow und **DejaVuSans-Bold**; die Schriftgröße sucht
  `_fit_font()` je Wert von 28 px abwärts. Der vorherige TypeScript-Nachbau
  mit 5×7-Pixelschrift war am Gerät deutlich schlechter lesbar
- **Bauhöhe 128×32 (Adafruit PiOLED) als Vorgabe**, 128×64 einstellbar.
  Multiplex, COM-Pin-Lage und Seitenbereich folgen ihr — mit den falschen
  Werten zeigt das Panel ein verdoppeltes, unleserliches Bild
- Init-Sequenz an `Adafruit_CircuitPython_SSD1306` angeglichen, inklusive
  `0xad/0x30` (interne Referenzstromquelle; ohne sie bleiben viele
  SSD1315-Nachbauten dunkel)
- Der Core schreibt nur noch Werte nach `oled-state.json`; der Anzeigedienst
  legt den fertigen Framebuffer daneben. **Die Live-Vorschau im WebUI zeigt
  damit das echte Bild vom Gerät**, keinen Nachbau
- Seitenreihenfolge: Standort zuerst, dann der Analyzer, dann die Systemwerte
  des Originals, zuletzt dessen vierzeilige Übersicht
- **Je Gerät ab 80 % Duty-Cycle eine eigene Seite** mit Namen — ein einzelner
  Dauersender kann das Funknetz zustopfen, und dann ist der Name die
  eigentliche Information

**Taster**
- **Langer Druck (5 s) startet den Pi neu**, nach 3 s Vorwarnung „Neustart…"
  auf dem Display. Zeiten aus der Konfiguration des Vorbilds
- Gemessen wird der Pegel (`gpioget`), nicht die Flanke — die Ausgabe von
  `gpiomon` unterscheidet sich zwischen libgpiod 1 und 2
- `--bias=pull-up`: Ohne definierten Ruhepegel blätterte die Anzeige von
  selbst weiter; ohne angeschlossenes Zubehör erzeugte der offene Eingang
  fortlaufend Flanken. Der Taster wird zudem nur überwacht, wenn der
  Anzeigedienst zeichnet, und schaltet sich bei über 50 Flanken je Sekunde ab

**Einrichtung**
- `deploy/oled-einrichten.sh` — einzeln wiederholbar nach einem Fehlschlag.
  Installiert `python3-lgpio` vorab, damit pip lgpio nicht aus dem Quellcode
  baut (scheiterte an fehlendem `swig` bzw. `-llgpio`), legt das venv **mit**
  `--system-site-packages` an und prüft das auch bei vorhandener Umgebung
- Die Unit setzt `WorkingDirectory`, `HOME` und `LG_WD` — lgpio legt sonst
  seine Pipes unter `//.lgd-nfy0` an und bricht ab. Kein `DeviceAllow`: Eine
  solche Zeile hätte über `DevicePolicy=closed` die gpiochip-Knoten gesperrt

**Absturzsuche**
- Die Statusanzeige protokolliert **jede Hardware-Aktion** mit Zeitstempel
  (Stufe „debug"). Bricht die Aufzeichnung mittendrin ab, ist der
  Zusammenhang belegt statt vermutet
- `tools/absturz-bericht.sh` zeigt unsere Protokollzeilen **unmittelbar vor**
  dem Ausfall, nicht mehr den Betrieb danach
- Lüfterdrehzahl aus `hwmon` in Diagnose und Anzeige

**Sonstiges**
- Versionsanzeige: `install.sh`/`update.sh` holen jetzt `--tags`, sonst blieb
  der Stand auf dem Pi bei einem alten Tag stehen; `git describe` beschreibt
  gezielt die Projektversion statt eines beliebigen Tags auf demselben Commit
- Tortengrafik: Legende rückt am Telefon unter die Torte statt darüber

### v0.8.0 — 31.07.2026

Der Analyzer sagt jetzt selbst, was ihm fehlt. Anlass war ein Raspberry Pi, der
reproduzierbar ausfiel und danach nicht mehr erreichbar war — ohne Aufzeichnung
ist so etwas nicht zu finden. Dazu die neue Platine (Hardware v0.2.0, unten
eigens beschrieben), die 3D-Druckvorlagen für den 19-Zoll-Einbau und eine
Oberfläche, die auch am Telefon bedienbar ist.

**Protokoll und Wartung (M13)**
- Neuer Reiter **Wartung**: Stufe (`Fehler` / `Info` / `Debug` / `alles`),
  Aufbewahrung in Tagen, Liste der Dateien, Download — alles im Browser
- Eine Datei je Tag (`asksin-JJJJ-MM-TT.log`), feste Spalten, umgeschaltet
  beim ersten Eintrag nach Mitternacht; ältere Dateien räumt die
  Aufbewahrungsfrist ab. Ohne Fremdbibliothek, der Core bleibt
  abhängigkeitsfrei
- Schreibfehler beenden den Dienst **nie** — ein volles Dateisystem wird
  gemerkt und angezeigt, nicht zum Absturz erhoben
- **Systemjournal wird mitgelesen**, damit sich „lag es an uns oder am
  System?" beantworten lässt: Unterspannung, OOM-Killer, USB-Neuanmeldungen,
  Dateisystemfehler, Temperaturnotabschaltung, Kernel-Panik. Nach jedem Start
  wird zusätzlich der **vorherige** Systemlauf zusammengefasst — endete er
  unsauber, steht genau das im Protokoll
- Der Installer schaltet das Journal auf **dauerhaft**; ab Werk ist es auf
  Raspberry Pi OS flüchtig und nach jedem Absturz verloren
- Regelmäßige Selbstdiagnose: Temperatur, Drosselung, Speicher, Laufzeit —
  bei Auffälligkeiten sofort, sonst alle 15 Minuten
- Neu: [`tools/absturz-bericht.sh`](tools/absturz-bericht.sh) sammelt nach
  einem Ausfall alles Relevante ein und gibt eine Einschätzung aus

**Status-LED**
- Die Ansteuerung richtet sich nach der Pi-Generation: **PWM (GPIO18)** auf
  Pi 3/4, **SPI (GPIO10)** auf Pi 5. Auf Pi 3/4 leitet sich der SPI-Takt vom
  Kerntakt ab und wandert mit dessen Skalierung — das zerreißt das
  WS2812-Timing
- PWM/DMA braucht Root, der Analyzer läuft unprivilegiert: Der Core rechnet
  die Farbe aus, der kleine Dienst `asksin-analyzer-led` setzt sie
- Auf dem Pi 5 ist der PWM-Weg **dreifach gesperrt**. Hinter dem RP1 liegt die
  Peripherie anderswo, während `rpi_ws281x` die alte Speicherlage anspricht;
  im ungünstigen Fall schreibt ein DMA-Kanal in fremden Speicher

**Betrieb**
- **Der Dienst startete auf Port 80 nicht** (`listen EACCES`). Behoben mit
  `AmbientCapabilities=CAP_NET_BIND_SERVICE`; scheitert der Start dennoch,
  erklärt der Dienst den Grund im Klartext statt mit einem Stapelabzug
- Der Einrichtungsassistent ist in nummerierte Abschnitte gegliedert — die
  Frage nach dem Port las sich vorher, als sei die CCU gemeint

**Weboberfläche**
- **Am Telefon und Tablet nutzbar.** Die Oberfläche enthielt bis dahin keine
  einzige Media Query: Die Kopfzeile lief über, breite Tabellen schoben die
  Seite zur Seite, iOS zoomte beim Antippen eines Feldes hinein. Die
  Navigation bekommt eine eigene, scrollbare Zeile; breite Tabellen scrollen
  im Panel, **ohne** eine Spalte auszublenden; Fingerbedienung hängt an
  `pointer: coarse`, nicht an der Fensterbreite. Die Schriftgröße bleibt
- Token-Felder haben einen Umschalter **anzeigen / verbergen** (Auge), damit
  sich ein Tippfehler prüfen lässt. Liegt die Eingabe offen, ist der Knopf
  farblich hervorgehoben

**Hardware und Fertigung** (Platine selbst siehe *Hardware v0.2.0*)
- Die drei Peripheriestecker tragen ihre Funktion im Bestückungsdruck:
  **OLED I2C**, **TASTER**, **WS2812**
- Neu: `hardware/kicad/pruefe_fertigung.py` — 30 maschinelle Prüfungen von den
  Lagen über die Einbaumaße und die J1-Geometrie bis zum Abgleich von BOM und
  CPL gegen die Platine. Unbestückte Plätze werden aus dem Schaltplan
  abgeleitet statt von Hand gepflegt; genau eine handgepflegte Liste hatte
  zuvor R4 aus der Bestückung geworfen

**Einbau**
- 3D-Druckvorlagen für den 19-Zoll-Rahmen (Front-Einsatz je für Pi 4 und
  Pi 5, SSD-Einsatz), Herkunft und Lizenz der Remixe dokumentiert
- J1-Adapter für die fehlerhafte Charge der Hardware v0.0.1 mit eigenem
  Fertigungspaket

### Hardware v0.2.0 — 30.07.2026

**J1 war gespiegelt.** Der Footprint kam aus der offiziellen Vorlage
`RaspberryPi-HAT`, aber ohne deren Flip auf die Unterseite: Die ungerade
Pinreihe saß richtig, die gerade 2,54 mm daneben. Aufgesteckt landet jedes
Pad einen Pin daneben. Betroffen sind **alle bisher gefertigten Platinen**;
sie laufen mit dem [J1-Adapter](hardware/kicad/adapter/README.md) einwandfrei.
`generate_pcb.py` prüft die Padgeometrie jetzt bei jedem Lauf gegen das
Pi-Raster.

**Status-LED D1 war verpolt.** Kathode an R1, Anode an Masse — die Firmware
treibt ihren Pin aktiv auf HIGH, der Strom hätte gegen die Diodenrichtung
fließen müssen. Die LED konnte nie leuchten. Betrifft ebenfalls alle bisher
gefertigten Platinen; rein kosmetisch, der Funkempfang war nie beeinträchtigt.

**Neue Bauform:** L-förmig, 100 × 76 mm. Der Streifen (100 × 20 mm) liegt
parallel neben dem Pi an der Header-Seite und ist **höchstens 20 mm breit**;
der Schenkel steht **32 mm hinter der SD-Kante**. Über dem Pi liegt nur der
8 mm tiefe Arm für die 2×20-Buchse und eine 7 × 9 mm große Nase am hinteren
Befestigungsloch — der Lüfter des PoE-HAT bleibt frei. Nach vorn endet die
Platine 17 mm **vor** dem Pi, damit sie den Keystone-Modulen im 19-Zoll-Einbau
nicht in die Quere kommt. Das Funkmodul sitzt im Schenkel (Antennen-Keystone),
die Peripheriestecker an der Frontkante (OLED-/LED-/Taster-Einsatz).

**Umschalter statt Bestückungsvariante:** Der SMD-Schiebeschalter **SW1** an
der Außenkante wählt zwischen PWM (GPIO18) und SPI (GPIO10) für die
WS2812-Datenleitung; dahinter liegt ein gemeinsamer 330-Ω-Widerstand. Die
frühere Regel „R4 **oder** R5 bestücken" entfällt — der Bestückungsdruck ist
mit **PWM** und **SPI** beschriftet.

Routing-Kette überarbeitet: Masseflächen nur noch auf den Innenlagen, jedes
SMD-Massepad bekommt sein Stützvia vor dem Routen, alle Vias getentet, und
`rebuild.py` baut so lange neu, bis DRC 0/0 und Netzliste exakt sind.

### v0.0.7 — 29.07.2026

Langzeitdaten (M9.5) — der Verbund ist komplett. Hardware unverändert (0.0.1).

### Langzeitdaten: extern oder vor Ort

Zwei Wege, die sich nicht ausschliessen:

**Extern** (unverändert) — jeder Analyzer schreibt seine Kennzahlen in eine
vorhandene InfluxDB v2, etwa auf einem Server oder NAS. Einzustellen unter
*Einstellungen → Langzeitdaten*.

**Vor Ort** (neu, optional) — InfluxDB und Grafana laufen auf dem Analyzer
selbst. Nur auf dem **Master** und nur ab **Raspberry Pi 4 mit 2 GB**; beides
wird geprüft, auf schwächerer Hardware erscheint die Option gar nicht. Ein
Klick unter *Einstellungen → Langzeitdaten vor Ort*, oder gleich beim
Einrichten — der Installer fragt danach.

Mitgeliefert werden **acht Grafana-Ansichten** (Leitstand, Funkqualität,
Duty-Cycle-Wächter, Gerätedetail, Störungssuche, Batteriewächter,
Verbund-Vergleich, Gerätezustand) und **vier Alarme** (Analyzer offline,
Duty-Cycle über 80 %, Gerät seit 24 h stumm, Grundrauschen erhöht). Die
Dashboards liegen als JSON unter [`deploy/grafana/dashboards/`](deploy/grafana/dashboards/)
und lassen sich auch in ein bestehendes Grafana importieren.

Platzbedarf: rund 5–10 MB je Tag und Analyzer, also etwa 10–15 GB im Jahr bei
fünf Geräten. Aufbewahrt wird zwei Jahre.

**Wohin die Alarme melden**, wird ebenfalls in der WebUI eingestellt — drei
Wege stehen zur Wahl:

1. **ioBroker-Adapter** (empfohlen, wenn ioBroker läuft): Grafana ruft den
   Adapter auf, der über die dort schon eingerichteten Messaging-Adapter
   verteilt. Man richtet Telegram, Signal oder Pushover damit **einmal im
   ioBroker** ein statt ein zweites Mal in Grafana. *(Endpunkt im Adapter
   folgt in einer eigenen Phase.)*
2. **E-Mail** — mit **Testknopf**: Der Analyzer verschickt selbst über SMTP
   und gibt die Antwort des Servers im Klartext zurück, samt Hinweis, was zu
   tun ist. Kein Umweg über Grafana, kein Speichern nötig.
3. **Telegram** — Bot-Token und Chat-Kennung.

Gespeichert wird immer **Kontaktpunkt und Benachrichtigungsrichtlinie
zusammen**. Genau deren Trennung ist der häufigste Grund, warum selbst
eingerichtete Grafana-Alarme nie ankommen.

Für Einsteiger ist das alles im Handbuch Schritt für Schritt beschrieben —
Kapitel 19.3 bis 19.11, mit Abbildungen aller acht Ansichten.

### Versionsabhängigkeit zum ioBroker-Adapter

Analyzer und Adapter werden getrennt gepflegt. Damit ein Gespann aus zwei
unpassenden Fassungen nicht als diffuses „geht nicht" auffällt, weist **jede
Seite aus, welche Fassung der anderen sie braucht — und prüft es**:

| Analyzer | Adapter | wodurch |
| --- | --- | --- |
| 0.12.0 | 0.0.2 | erste Fassung mit Alarm-Zustellung |

### Die Clients an die Datenbank anschließen

Nur der Master speichert. Die übrigen Analyzer schicken ihre Kennzahlen
dorthin — einzustellen auf **jedem Client** unter *Einstellungen →
Langzeitdaten (InfluxDB)*:

| Feld | Wert |
| --- | --- |
| InfluxDB-URL | `http://<IP-des-Masters>:8086` |
| Organisation | `asksin` |
| Bucket | `asksin` |
| API-Token | **derselbe wie auf dem Master** |

Den Token gibt es nur einmal, für alle. Zu finden auf dem Master in der
Weboberfläche (Augensymbol) oder in `/etc/asksin-analyzer/influx-zugang.txt`.

Ob es geklappt hat, steht unter den Feldern („12 Schreibvorgänge, 0 Fehler")
und auf der Übersichtsseite des Masters als **Zahl der Standorte** — die kommt
aus der Datenbank selbst und steht erst dann auf 5, wenn wirklich alle fünf
schreiben.

Schritt für Schritt samt der drei üblichen Stolpersteine: Handbuch 19.6.

Der Testknopf im Analyzer fragt den Adapter vorher nach seiner Fassung; der
Adapter prüft bei jeder Abfrage die des Analyzers. **Jede Änderung an dieser
Abhängigkeit gehört auf beide Seiten** — sonst behauptet jede etwas anderes.

**Core/Web-UI 0.0.7**
- **Langzeitdaten nach InfluxDB v2**: jeder Analyzer schreibt dezentral
  mit `standort`-Tag per Line Protocol (ohne Client-Bibliothek);
  Measurements `analyzer` (Verbindung, Telegramme/min, Grundrauschen,
  Geräte) und `geraet` (RSSI, Duty-Cycle je Funkgerät) — Grafana wertet
  zentral über alle Standorte aus
- Konfiguration über Einstellungen → Langzeitdaten (URL, Org, Bucket,
  Token — wird nie angezeigt, Intervall), sofort wirksam; Influx-Ausfälle
  stören den Analyzer nicht, die lokale SQLite bleibt primär
- ioBroker-Adapter neu aufgebaut mit @iobroker/create-adapter
  (Tests, Workflows, ESLint/Prettier, i18n in 11 Sprachen,
  Verbund-States, Icon) — eigenes Repo ioBroker.asksinanalyzer-rpi
- 143 Unit-Tests

### v0.0.6 — 29.07.2026

Status-LED und OLED (M11): die Funktionen des Status-LED-OLED-Projekts,
vollständig integriert. Hardware unverändert (0.0.1).

**Core/Web-UI 0.0.6**
- **Status-LED** (WS2812 an J7; seit v0.2.0 wählt der Schalter SW1 zwischen PWM und SPI):
  Prioritätsleiter Duty-Cycle-Alarm (rot schnell) > getrennt (rot) >
  Persistenzfehler (gelb) > Demo (orange) > Update (blau atmend) > ok
  (grün); eigene SPI-Bit-Kodierung, keine native Bibliothek
- **OLED** (SSD1306 an J5, Vorgabe 128×32): gezeichnet vom eigenen Dienst
  `asksin-analyzer-oled` mit **denselben Bibliotheken wie das Vorbild**
  (`adafruit_ssd1306`, Pillow, DejaVuSans-Bold, Schriftgröße je Wert gesucht).
  Seiten: Standort, Sniffer, Telegramme, Rauschen, Geräte, Duty-Cycle,
  **je Dauersender eine eigene Seite**, Version, IP/MAC/Host, CPU/RAM/Up,
  Disk/Fan, Übersicht. Taster an J6: kurz blättert, **5 s startet den Pi neu**
- **Statusseite im WebUI**: LED-Punkt in Echtfarbe mit Grund,
  Systemwerte, Störungs-Diagnose und pixelgenaue OLED-Live-Vorschau
  mit Blättern-Knopf auf der Übersicht
- **Nachträglich aktivierbar ohne Konsole**: Einstellungen →
  Status-LED & OLED (LED/OLED/Helligkeit), sofort wirksam; die
  Backup-Funktion der Vorlage wird bewusst nicht übernommen
- **NTP aufgeräumt**: Konfiguration nur noch in den
  Netzwerkeinstellungen; Vorgabe de.pool.ntp.org, Anzeige des
  tatsächlich verwendeten Servers samt Sync-Status
- 140 Unit-Tests

### v0.0.5 — 29.07.2026

Der Verbund: fünf Analyzer als Gesamtsystem — plus Netzwerkverwaltung
über die Weboberfläche. Hardware unverändert (0.0.1).

**Core/Web-UI 0.0.5**
- **Verbund (M9.1–M9.4)**: Standort-Identität (Badge, Tab-Titel, APIs);
  neue Ansicht „Verbund" mit Kachel je Standort, Zeitdrift-Warnung und
  Drilldown; **Empfangsmatrix Gerät × Standort** (RSSI-Farbskala,
  ★ bester Empfang, CSV-Export); **deduplizierte Telegrammliste** mit
  „gehört von"-Chips (Schlüssel Absender+Zähler+Typ+Länge, ±1,5 s,
  selbstheilend bei Peer-Neustarts); **Flotten-Update** — alle Analyzer
  nacheinander mit Health-Gate, Abbruch statt Domino, Master zuletzt
- **Peers ohne Konsole**: verknüpfen/entfernen unter Einstellungen →
  Verbund, sofort wirksam; Tokens werden nie herausgegeben; Installer
  fragt die Master-Rolle ab und leitet an
- **Netzwerkeinstellungen (M7.6)**: Einstellungen → Netzwerk zeigt den
  Ist-Zustand (inkl. DHCP-Zuweisungen) und ändert DHCP/Statisch,
  statische Werte, Hostname und NTP — mit 90-s-Probezeit und
  automatischem Rollback gegen Aussperren (nmcli/hostnamectl/timesyncd
  über systemd-Path-Unit)
- Doku: Phasen M11 (Status-LED/OLED) und M12 (Einkaufsführer) geplant,
  Platzhalterbild „Produktbild folgt"
- 131 Unit-Tests

### v0.0.4 — 29.07.2026

Update-Pfade (M7.5): Die Software aktualisiert sich selbst — atomar,
rückrollbar und fernsteuerbar. Hardware unverändert (0.0.1).

**Core 0.0.4**
- **Self-Update über die Weboberfläche/API**: `/api/update/versions`,
  `/api/update/core`, `/api/update/status` — der unprivilegierte Dienst
  legt nur eine Trigger-Datei an, eine systemd-Path-Unit startet
  `update.sh` als root (NoNewPrivileges bleibt intakt)
- `update.sh` atomar und rückrollbar: UI-Build nach `dist-neu` mit
  atomarem Tausch, Statusdatei übersteht den Dienst-Neustart,
  Health-Check nach dem Neustart, bei Fehlschlag automatischer Rollback
  von Git-Stand und UI; installiert fehlende Units selbstheilend nach
- **328P-Firmware-Flash** über die API: Intel-HEX-Upload, Ingest pausiert
  und gibt den Port frei, Reset am HAT über GPIO4 (libgpiod v2/v1), am
  USB über DTR, avrdude mit 58 824 Baud; Kommandosequenz injizierbar und
  ohne Hardware getestet
- **Täglicher Selbstcheck** auf neue Versionen (Start + alle 24 h),
  Ergebnis in `/api/health`
- git `safe.directory` für den Dienstbenutzer automatisch gesetzt;
  Versions-Hook meldet Fehler lesbar statt mit 500
- 118 Unit-Tests

**Web-UI 0.0.4**
- Info-Ansicht: Update suchen/installieren mit Live-Fortschritt über den
  Dienst-Neustart hinweg; Firmware-Upload mit avrdude-Log
- Pulsierendes **🔔-Update-Badge** in der Kopfzeile, sobald der
  Selbstcheck eine neue Version meldet — Klick führt zur Info-Seite

### v0.0.3 — 29.07.2026

Demo-Modus und die Tortengrafik der Startseite. Hardware unverändert (0.0.1).

**Core 0.0.3**
- **Demo-Modus**: simulierte Anlage (~15 Geräte inkl. HmIP, Thermostaten,
  Bewegungsmeldern und einem absichtlich dauersendenden Defekt-Gerät) als
  Port-Generator ganz unten in der Kette — Parser, Statistik, Datenbank,
  API und UI laufen unverändert mit; Geräteliste im originalen
  CCU-Drahtformat; eigene Demo-Datenbank mit kurzer Retention
- Umschalten im laufenden Betrieb über die Weboberfläche
  (Flag-Datei + kontrollierter Dienst-Neustart); `demo`-Feld in
  `/getConfig` und `/api/health`
- 111 Unit-Tests

**Web-UI 0.0.3**
- Übersicht: Tortengrafik **„Telegramme pro Gerät"** wie im Original —
  alle Geräte einzeln, blätterbare Legende, Tooltip mit Name, Anteil,
  Adresse, RSSI und Duty-Cycle
- Schalter **Einstellungen → Demo-Modus** und DEMO-Badge in der Kopfzeile

### v0.0.2 — 29.07.2026

Die Pi-Software ist komplett: vom seriellen Port bis zur Weboberfläche,
installierbar mit einem Befehl. Hardware unverändert (bleibt 0.0.1).

**Core 0.0.2**
- Serial-Ingest: Zeilenstrom-Leser mit Stille-Watchdog (750-ms-Rauschzeilen),
  exponentiellem Reconnect-Backoff und Drop-Oldest-Puffer (M2)
- Persistenz: eingebautes node:sqlite (WAL), Recorder mit Batch-Transaktionen
  und additiven Upserts, Retention + WAL-Checkpoint; LiveStats (M3)
- Namensauflösung: DevListService mit CCU-Polling (stündlich, Fehler-Retry
  5 min) und atomarem Datei-Cache; latin1/XML/HTML-Dekodierung (M4)
- Analyzer-Komposition mit einer Leseschnittstelle `snapshot()` (M4)
- REST-API auf node:http: Kompatibilitäts-Endpunktsatz der originalen
  Web-UI (CSV-Polling, RSSI-Log, Config, DevList, Tages-CSV) plus eigene
  JSON-API `/api/*`; optionaler Bearer-Token, Bind an 127.0.0.1 (M5)
- Dienst-Einstiegspunkt `analyzerd` (JSON-Konfig, journald, sauberes
  Herunterfahren), läuft ohne Buildschritt und ohne Laufzeitabhängigkeiten
- 108 Unit-Tests, alle ohne Hardware

**Web-UI 0.0.2** (neu, MIT)
- Funktionaler Nachbau mit eigenem Code: Vue 3 + Apache ECharts statt
  Vue 2 + Highcharts; Routen wie im Original (/home, /list, /settings, /info)
- Übersicht mit Zeitchart und Duty-Cycle-Top-10, Live-Telegrammliste mit
  Filter, Einstellungen inkl. Token, Info mit Herkunftsnennung
- Wird vom Core selbst ausgeliefert (SPA-Fallback, Asset-Caching)

**Installation**
- `install.sh`: Ein-Befehl-Installation mit Konfigurations-Assistent,
  Node 24, systemd-Dienst (gehärtet), udev-Regel, optionaler
  UART-Einrichtung; Verwaltungsbefehl `asksin-analyzer`, `update.sh`

**Projekt**
- Repository öffentlich; Testdaten durch eine strukturgleiche synthetische
  Beispielanlage ersetzt, Git-Historie bereinigt

### v0.0.1 — 28.07.2026

Erster versionierter Stand.

**Hardware 0.0.1**
- Platine V4: L-förmiger Pi-Aufsatz (118 × 46 mm, 4 Lagen), Arm auf dem
  durchgeschleiften Header des PoE-HAT, Körper seitlich neben Pi und Lüfter
- Funkmodul Ebyte E07-900M10S mit IPEX-Antennenabgang — keine HF-Leitung auf
  der Platine; Zugentlastung für das Antennenkabel (KB1/KB2)
- Reset über GPIO4 (I²C bleibt frei für das OLED des Status-LED-Projekts);
  Anschlüsse für OLED, Taster und WS2812 samt Vorwiderstand an Bord
- vollständig autogeroutet (Freerouting), ERC 0/0, DRC 0 Verstöße
- Fertigungspaket mit Gerber, Bohrdaten, BOM/CPL (auch JLCPCB-Format) und
  Beschriftung (Name, Version, Datum, Copyright, Lizenz) auf beiden Seiten
- Hinweis: die allererste Fertigungscharge entstand vor Einführung der
  Versions-Beschriftung und trägt nur Name + Lizenz

**Core 0.0.1**
- Telegramm-Parser (Format verifiziert gegen Firmware und Referenz-Parser),
  fehlertolerant mit Verwurfszählern
- Duty-Cycle-Berechnung je Absender, gleitendes Stundenfenster, Ringpuffer
- 29 Unit-Tests, `tsc --strict` sauber, keine Laufzeitabhängigkeiten

**Projekt**
- Handbuch (34 Seiten PDF, deutsch, bebildert) inkl. Fuses/Bootloader/Firmware
- Doku: Hardware-Spezifikation, serielles Protokoll, UART-Einrichtung Pi 3/4/5,
  Web-UI-API-Vertrag, Bestelllisten (Reichelt + JLCPCB)

## Referenzprojekte (nicht im Repo)

Die Originalprojekte liegen aus Lizenz- und Größengründen nicht in diesem
Repository. Für die lokale Arbeit (`reference/` wird von `.gitignore`
ausgenommen):

```bash
mkdir -p reference && cd reference
git clone https://github.com/jp112sdl/AskSinAnalyzer.git
git clone https://github.com/jp112sdl/AskSinAnalyzer.wiki.git
git clone https://github.com/psi-4ward/AskSinAnalyzerXS.git
git clone https://github.com/pa-pa/AskSinPP.git
# Platinen-Vorlage V1.1 (der-pw):
cd .. && git clone https://github.com/der-pw/AskSinAnalyzerXS-RPi.git AskSinAnalyzerXS-RPi-main
```

## Verwendete Lizenzen

| Komponente | Lizenz | Urheber |
| --- | --- | --- |
| Hardware, Doku, Core (dieses Repo) | **CC BY-NC-SA 4.0** | © 2026 S. Sternitzke |
| Sniffer-Firmware ([eigenes Repo](https://github.com/ssbingo/asksin-sniffer-firmware)) | **CC BY-NC-SA 3.0** | © jp112sdl — abgewandelt, ShareAlike, [Quelle](https://github.com/jp112sdl/AskSinAnalyzer) |
| Web-UI (`webui/`, eigener Nachbau ohne Fremdcode) | **MIT** | © 2026 S. Sternitzke |
| Apache ECharts (Diagramme der Web-UI) | Apache-2.0 | Apache Software Foundation |
| Firmware `AskSinSniffer328P` (Vorlage unserer Fassung) | CC BY-NC-SA 3.0 | jp112sdl |
| AskSinPP (Bibliothek der Firmware) | CC BY-NC-SA 3.0 | pa-pa |
| AskSinAnalyzerXS (Referenz für Parser/Formeln) | CC BY-NC-SA 4.0 | psi-4ward |
| AskSinAnalyzerXS-RPi (Platinen-Vorlage V1.1) | CC BY-NC-SA 4.0 | der-pw |
| ioBroker-Adapter (eigenes Repo, geplant) | MIT | — |

Details und Begründung der Lizenzwahl: [`LICENSE`](LICENSE) und
[`docs/webui-und-updates.md`](docs/webui-und-updates.md), Abschnitt 4.

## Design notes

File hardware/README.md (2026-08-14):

# AskSin-Analyzer — Hardware-Spezifikation (v0.2.0)

> ### ⚠️ Errata zur Hardware v0.0.1 — Platinen der ersten Chargen
>
> Auf allen 2026 gefertigten Platinen (Bestückungsdruck „HW v0.0.1") ist die
> 2×20-Buchse **J1 gespiegelt**: Die ungerade Pinreihe sitzt richtig, die
> gerade liegt 2,54 mm auf der falschen Seite. Direkt aufgesteckt landet
> jedes Pad auf dem falschen Pi-Pin — 5 V auf 3,3 V, Masse auf GPIOs.
>
> **Diese Platinen niemals ohne Adapter aufstecken und einschalten.** Mit dem
> [J1-Rettungsadapter](kicad/adapter/README.md) sind sie voll funktionsfähig.
>
> Ursache: Der Footprint stammt aus der offiziellen Vorlage
> `RaspberryPi-HAT`, wurde aber ohne deren Flip auf die Unterseite übernommen.
> Seit v0.2.0 flippt `generate_pcb.py` J1 wie die Vorlage **und prüft die
> Pad-Positionen bei jedem Lauf hart gegen das Pi-Raster** — ein erneuter
> Fehler dieser Art bricht den Lauf ab.
>
> **Zweiter Fehler derselben Chargen: die Status-LED D1 war verpolt.** Im
> KiCad-Symbol ist Pin 1 die Kathode; sie lag an R1 statt an Masse, die Anode
> an Masse. Die Firmware schaltet ihren Treiberpin auf HIGH — der Strom hätte
> also gegen die Diodenrichtung fließen müssen, die LED blieb dunkel. Rein
> kosmetisch (die Empfangsanzeige), Funk und Auswertung waren nie betroffen.
> Ab v0.2.0 korrigiert.

Abgeleitet von **AskSin-Analyzer-XS-RPi V1.1** (der-pw, 08/2020), lizenziert
CC BY-NC-SA 4.0. Diese Ableitung steht unter derselben Lizenz und muss den
Urheber nennen.

Quelle der Analyse: `../AskSinAnalyzerXS-RPi-main/AskSinAnalyzerXS-RPi-main/KiCad/AskSin-Analyzer-XS-RPi.sch`
(Netzliste vollständig ausgewertet, nicht aus dem PDF abgelesen).

Umsetzung: [`kicad/`](kicad/) — KiCad-9-Projekt, Schaltplan generiert,
ERC 0 Fehler, Netzliste maschinell gegen diese Spezifikation geprüft.

**Gegenüber der Vorlage:** Der USB-Zweig entfällt — die Platine ist reines
Aufsteckmodul für einen **Raspberry Pi**. Dafür trägt sie zusätzlich die
Peripherie des Status-LED-OLED-Projekts: Stecker für Display, Taster und
WS2812-LED samt deren Vorwiderstand. Die Antenne verlässt das Funkmodul über
dessen IPEX-Buchse — auf der Platine gibt es **keine einzige HF-Leitung**.

**Bauform seit v0.2.0:** L-förmig und **liegend neben dem Pi**. Der Streifen
(100 × 20 mm) liegt parallel zur Header-Seite und ist **höchstens 20 mm breit**;
der Schenkel steht **32 mm hinter der SD-Kante** und trägt dort das Funkmodul.
Nach vorn (Buchsenseite) endet die Platine **17 mm vor** dem Pi — dort sitzen
im 19-Zoll-Einbau die Keystone-Module, jede Verlängerung geht deshalb
ausschließlich nach hinten. `pruefe_fertigung.py` erzwingt das. Über dem Pi
liegt nur zweierlei: der 8 mm tiefe **Arm** für die 2×20-Buchse und die beiden
HAT-Bohrungen, sowie eine 7 × 9 mm große **Nase** am hinteren
Befestigungsloch des Pi. Der Lüfter des PoE-HAT bleibt dadurch frei —
geprüft gegen den Waveshare **PoE HAT (F)** (Pi 5; dessen Lüfter beginnt rund
20 mm hinter der SD-Kante) und konstruktiv unabhängig vom **PoE HAT (C)**
(Pi 3B/4), für den Waveshare keine Maßzeichnung veröffentlicht.

Das Funkmodul sitzt am hinteren Ende des Streifens, die IPEX-Buchse zeigt zum
Schenkel — dort läuft das Antennenkabel, mit Kabelbinder entlastet, zum
rückwärtigen Keystone. Die drei Peripheriestecker liegen am vorderen Ende
(Rack-Front), der Umschalter SW1 an der Außenkante.

Maße des Pi aus den amtlichen Zeichnungen: **85 × 56 mm**, Befestigungslöcher
ø2,7 mm im Raster **58 × 49 mm**, je 3,5 mm von den Kanten — bei **Pi 3B+, 4
und 5 identisch**.

*(Bis v0.0.1 war der Umriss L-förmig mit dem Körper über den USB-/Ethernet-
Buchsen des Pi — das kollidierte mit dem 19-Zoll-Einbau. Die T-Form
dazwischen war 34 mm breit und passte nicht in den Einbaurahmen.)*

Zielaufbau: Pi (4 oder 5) → PoE-HAT mit durchgeschleiftem 40-poligem
Header → diese Platine. Mehrere solcher Einheiten an verschiedenen Stellen im
Haus, fest in Datenschränken montiert.

---

## 1. Bestandsaufnahme V1.1 (verifiziert)

### 1.1 Steckerbelegung J1 (2×5, Pi-Header Pin 1–10)

| Pi-Pin | Pi-Signal | Platine | Anmerkung |
| --- | --- | --- | --- |
| 1 | 3V3 | über JP1 auf 3,3-V-Rail | Lötbrücke, normal offen |
| 2 | 5V | LDO-Eingang | |
| 3 | GPIO2 / SDA1 | **DTR** → JP2 → RESET | Lötbrücke, normal offen |
| 4 | 5V | LDO-Eingang | |
| 5 | GPIO3 / SCL1 | nur Label `SCL`, **nicht verdrahtet** | toter Pin |
| 6 | GND | GND | |
| 7 | GPIO4 | `NoConn` | |
| 8 | GPIO14 / TXD | 328P **RXD** | |
| 9 | GND | GND | |
| 10 | GPIO15 / RXD | 328P **TXD** | |

### 1.2 Bestückung V1.1

U1 MCP1754S-3302 (SOT-23, 3,3 V / 150 mA) · U2 ATmega328P-AU (TQFP-32) ·
U3 CC1101-Modul (HM-Sensor, Footprint `Homebrew:CC1101_Module_HM-Sensor`) ·
J1 2×5 · JP1/JP2 Lötbrücken · TP1 (RESET) · L1 BLM21PG300 · R1 330 Ω ·
R2 10 kΩ (RESET-Pullup) · C1/C2 10 µF · C3/C4 100 n (VCC/AVCC) · C5 100 n (CC1101) · D1 LED

### 1.3 Bestätigte Schwachstellen

1. **Kein Taktgeber.** XTAL1/XTAL2 sind unbeschaltet → interner 8-MHz-RC.
2. **Kein ISP-Header.** Bootloader/Fuses nur über angelötete Drähte an
   MOSI/MISO/SCK (mit CC1101 geteilt) und TP1.
3. **DTR ohne Kondensator.** JP2 verbindet GPIO2 *galvanisch* mit RESET. Ein
   dauerhaft gesetzter Low-Pegel hält den 328P im Reset. Der 100 nF muss laut
   README ins Kabel gefrickelt werden.
4. **ANT (Pin 9 von U3) ist im Schaltplan unverbunden** — der Draht wird direkt
   an das Modul gelötet, unmittelbar über der Pi-Platine.
5. **CS ohne Pullup.** Liegt der 328P im Reset, sind seine Pins hochohmig, CS
   floated, der CC1101 ist undefiniert selektiert. Relevant, sobald über ISP
   programmiert wird (SPI ist geteilt).
6. **AREF hart auf 3,3 V.** Pin 20 hängt über `5200 1850 → 5025 1550` direkt an
   der Versorgung. Das Datenblatt verlangt stattdessen einen Abblockkondensator
   gegen Masse. Solange die Firmware den ADC nicht anfasst, fällt es nicht auf —
   aktiviert sie je die interne 1,1-V-Referenz, wird diese gegen die
   Versorgung kurzgeschlossen. Latenter Fehler, kein akuter.
7. **Im Footprint fehlt das Antennenpad.** Beim Extrahieren des
   CC1101-Footprints aus der V1.1-Platine kamen nur zehn Pads zutage: 1–8 und
   10–11. **Pad 9 (ANT) existiert nicht.** Das ist der eigentliche Grund für den
   angelöteten Draht — nicht Bequemlichkeit, sondern ein fehlendes Pad. Details:
   `kicad/README.md`.

---

## 2. Taktgeber und Baudrate — die eigentliche Entscheidung

Das ist der Punkt, der vor dem KiCad-Nachmittag geklärt sein muss, weil er
Bauteil *und* Firmware betrifft.

### 2.1 Warum ein Taktgeber gesetzt ist

Die `platformio.ini` des **Ursprungsprojekts** (jp112sdl) baut gegen
`board = pro8MHzatmega328`, also F_CPU = 8 000 000. Der Arduino-Pro-Mini-3,3 V hat dafür einen **externen**
8-MHz-Resonator. V1.1 hat keinen — die Firmware läuft dort also auf dem
internen RC-Oszillator, dessen Fuse-Konfiguration (`lfuse = 0xE2`) von der
Pro-Mini-Standardkonfiguration (`lfuse = 0xFF`) abweicht. Der interne RC ist
über Temperatur und Betriebsspannung mit ±10 % spezifiziert; ab Werk kalibriert
liegt er typisch bei 1–2 %. Für 24/7-Betrieb ist das die falsche Seite der
Toleranzgrenze.

**Am 09.08.2026 an der ersten bestückten Platine nachgemessen**, und die
Entscheidung war richtig: Derselbe Chip, dieselbe Firmware, nur die Taktquelle
umgestellt.

| Taktquelle | Rahmenfehler des Pi (`fe:`) |
| --- | --- |
| interner RC-Oszillator, 8 MHz | **31** bei rund 1 000 empfangenen Byte |
| Resonator Y1, 8 MHz | **0** bei 1 002 Byte — das Feld fällt ganz weg |

Die serielle Schnittstelle verträgt etwa ±2,5 %; der interne RC lag darüber.
Mit dem Resonator ist die Übertragung fehlerfrei.

### 2.2 Der zweite, unabhängige Fehler: 57600 Baud passen nicht auf 8 MHz

`HardwareSerial::begin()` rechnet im U2X-Modus mit Ganzzahlarithmetik:

```text
UBRR = (F_CPU / 4 / baud - 1) / 2 = (8000000/4/57600 - 1)/2 = (34 - 1)/2 = 16
ist = F_CPU / (8 · (UBRR+1)) = 8000000 / 136 = 58823,5 Baud   →  +2,12 %
```

Die 16-MHz-Sonderbehandlung für 57600 in `HardwareSerial.cpp` greift bei 8 MHz
nicht. **Dieser Fehler entsteht auch bei perfektem Quarz** — er steckt im
Teilerverhältnis, nicht im Oszillator. UART-Empfänger tolerieren bei 8N1 und
16-fach-Oversampling grob ±2,5 %; 2,12 % ist innerhalb, aber ohne Reserve. Der
RC-Oszillator addiert seine Drift oben drauf. Genau daher rühren die
sporadischen Framing-Fehler, die im Homematic-Forum zu dieser Platine
auftauchen.

### 2.3 Sauber teilbare Baudraten bei 8 MHz

| Baud | UBRR (U2X) | Ist-Baudrate | Fehler |
| --- | --- | --- | --- |
| 19200 | 51 | 19230,8 | +0,16 % |
| **38400** | **25** | **38461,5** | **+0,16 %** |
| 57600 | 16 | 58823,5 | +2,12 % |
| 76800 | 12 | 76923,1 | +0,16 % |
| 115200 | 8 | 111111,1 | −3,55 % |

38400 wäre die Baudrate mit dem kleinsten Fehler. **Entschieden ist 57600** —
und das kostet nichts, siehe 2.5.

### 2.4 Was ausdrücklich *nicht* geht

**7,3728 MHz** (der klassische UART-Quarz, 0,00 % Fehler) scheidet aus.
`AskSinPP/AlarmClock.h:152` rechnet

```c
const unsigned long cycles = (F_CPU / 2000000) * (1000000 / TICKS_PER_SECOND);
```

Bei 7 372 800 ergibt die Ganzzahldivision `3` statt 3,6864 — die komplette
Systemuhr liefe 18,6 % falsch. F_CPU muss ein Vielfaches von 2 MHz sein.
8 MHz und 16 MHz sind sauber, 7,3728 MHz ist es nicht.

**16 MHz** scheidet aus, weil der ATmega328P bei 3,3 V nur bis ca. 13 MHz
spezifiziert ist (Datenblatt: 10 MHz @ 2,7 V, 20 MHz @ 4,5 V, linear dazwischen).
Ein Betrieb bei 5 V würde Pegelwandler zum CC1101 *und* zum Pi erzwingen.

### 2.5 Entscheidung: 57600 bleibt, der Fehler wird auf der Gegenseite kompensiert

Es gibt keine Taktfrequenz, die beides erfüllt. Für exakte 57600 Baud im
U2X-Modus müsste `F_CPU = 460800 · n` sein, für AskSinPPs Systemuhr (2.4)
zugleich ein Vielfaches von 2 MHz. Das kleinste gemeinsame Vielfache liegt bei
288 MHz — außerhalb jeder Diskussion. **Bei 8 MHz sind 57600 Baud also
zwangsläufig 58823,5.**

Der entscheidende Punkt ist aber: dieser Fehler ist **einseitig und bekannt**.
Der ATmega sendet mit 58823,5 Baud, und niemand zwingt den Pi, mit 57600 zu
lauschen. Die PL011 des Pi hat einen Baudratenteiler mit 6 Bit Nachkomma und
trifft praktisch jede Rate:

```text
ATmega328P @ 8 MHz, UBRR = 16, U2X = 1   →  8 000 000 / 136 = 58823,53 Baud
Pi PL011   @ 48 MHz UARTCLK, Teiler 51   → 48 000 000 / 816 = 58823,53 Baud
```

Beide Seiten landen auf demselben Wert. **Der Core öffnet den Port also mit
58824 Baud statt 57600 — Restfehler praktisch 0,00 %** statt 2,12 %. Linux
unterstützt beliebige Baudraten über `TCSETS2`/`BOTHER`, `node-serialport`
reicht das durch, und auf dem Pi 5 gilt dasselbe über den fraktionalen Teiler
des RP1.

Damit ist das Ergebnis besser als bei 38400 — und die Firmware muss dafür
**nicht angefasst** werden: Der Fehler wird vollständig auf der Pi-Seite
ausgeglichen.

*Nachtrag 09.08.2026:* Das war ursprünglich auch als Lizenzargument gedacht —
kein Fork, kein abgeleitetes Werk. Inzwischen gibt es beides. Die Firmware ist
eine abgewandelte Fassung in
[ssbingo/asksin-sniffer-firmware](https://github.com/ssbingo/asksin-sniffer-firmware),
weil das Original ohne Funkmodul im `setup()` stehen bleibt und weil MiniCore
über `-DNDEBUG` die gesamte Ausgabe entfernt. Die Lizenz bleibt CC BY-NC-SA 3.0
mit ShareAlike; die Baudratenrechnung in diesem Abschnitt gilt unverändert.

Konsequenzen, die konsistent gehalten werden müssen:

| Stelle | Wert |
| --- | --- |
| Firmware (`DINIT` im Sketch) | 57600 — nominal, real 58 823,5 |
| Optiboot-Bootloader | 57600 (rechnet dasselbe UBRR = 16) |
| Core-Dienst, serieller Port (USB **und** GPIO) | **58824** |
| `avrdude` beim Firmware-Update | `-b 58824` |
| Mitschneiden auf dem Pi | `57600` per `stty`, danach `58824` per `deploy/baudrate.py` — `stty` kennt die krumme Rate nicht |

Der 8-MHz-Resonator (Y1) bleibt trotzdem Pflicht. Er behebt die *andere* Hälfte
des Problems: die Temperatur- und Spannungsdrift des internen RC-Oszillators,
die sich nicht wegkonfigurieren lässt.

Durchsatzprüfung: die längste mögliche Zeile ist `23 + 2·(60−9) + 1 = 126`
Zeichen plus Newline ≈ 128 Byte. 57600 Baud = 5760 Byte/s ≈ 45
Maximal-Telegramme pro Sekunde. Das 868-MHz-Band kann physikalisch weniger
tragen — ein 20-Byte-BidCoS-Telegramm belegt rund 25 ms Sendezeit, also
höchstens ~40 Telegramme/s bei 100 % Kanalauslastung, und die sind im Mittel
deutlich kürzer als 126 Zeichen. Reserve ist reichlich vorhanden.

---

## 3. Aufbau V4

### 3.1 Der Konflikt, der die Reset-Leitung verlegt hat

Das Status-LED-OLED-Projekt betreibt sein Display als **SSD1306 über I²C**, also
auf **GPIO2 (SDA)** und **GPIO3 (SCL)** — Header-Pins 3 und 5. Genau auf GPIO2
lag ursprünglich unsere Reset-Leitung, über einen 100-nF-Koppelkondensator zum
RESET des 328P.

**Ein 100-nF-Kondensator auf SDA macht den I²C-Bus unbrauchbar.** Das Display
wäre tot gewesen, und der Fehler wäre erst an der fertig bestückten Platine
aufgefallen.

Der Reset sitzt deshalb auf **GPIO4 (Pin 7)** — auf der ursprünglichen
der-pw-Platine als `NoConn` geführt und sonst frei. Eine Einschränkung bleibt:
aktiviert man je 1-Wire, belegt dessen Standardüberlagerung ebenfalls GPIO4.
Dann muss `dtoverlay=w1-gpio,gpiopin=…` auf einen anderen Pin.

### 3.2 Belegung des Pi-Headers

| Pi-Pin | Signal | Verwendung |
| --- | --- | --- |
| 1 | 3V3 | **durchgereicht** zu Display und LED |
| 2, 4 | 5V | Eingang unseres Reglers |
| 3, 5 | GPIO2/3 | I²C, **durchgereicht** zum Display |
| 6, 9, 14, 20, 25, 30, 34, 39 | GND | |
| 7 | GPIO4 | Reset des 328P |
| 8 | GPIO14 | Pi sendet → 328P RXD |
| 10 | GPIO15 | Pi empfängt ← 328P TXD |
| 11 | GPIO17 | Taster |
| 12 | GPIO18 | WS2812-Daten (PWM, Vorgabe) |
| 19 | GPIO10 | WS2812-Daten (SPI, Alternative) |

Die 3,3 V für Display und LED kommen **vom Pi**, nicht aus unserem Regler. Zwei
Gründe: das Status-LED-Projekt nutzt sie bewusst so, damit der Datenpegel der
WS2812 ohne Pegelwandler passt — und unsere Reglerschiene bleibt frei von
Displaystörungen, was dem Empfänger zugute kommt.

### 3.3 Peripheriestecker

Drei verriegelnde JST-PH-Stecker an der dem Pi zugewandten Kante:

| Ref | Funktion | Belegung |
| --- | --- | --- |
| J5 | OLED, I²C | 1 GND · 2 3V3 · 3 SCL · 4 SDA |
| J6 | Taster | 1 GPIO17 · 2 GND |
| J7 | WS2812 | 1 3V3 · 2 Daten · 3 GND |

Die Datenleitung der WS2812 führt **über die Platine** und ist seit v0.2.0
per **Schiebeschalter SW1** umschaltbar — kein Umlöten mehr:

- **Stellung SPI** → GPIO10. Vorgabe auf dem **Pi 5**; die PWM/DMA-Bibliotheken
  bedienen den RP1-Chip nicht.
- **Stellung PWM** → GPIO18. Vorgabe auf **Pi 3/4**; dort leitet sich der
  SPI-Takt vom Kerntakt ab und wandert mit dessen Skalierung, was das
  WS2812-Timing zerreißt.

Dahinter liegt ein gemeinsamer Serienwiderstand **R4 = 330 Ω**, wie ihn das
Vorbildprojekt für beide Methoden vorsieht. Der Bestückungsdruck beschriftet
die beiden Anschlüsse mit **PWM** und **SPI**. Die Beschriftung benennt die
Anschlüsse (welcher GPIO an welcher Seite liegt) — welche Schieberstellung
welchen Anschluss durchschaltet, gibt C&K nicht frei zugänglich her; mit einem
Durchgangsprüfer ist es beim ersten Aufbau in Sekunden bestätigt. Der Installer erkennt das Modell
und stellt die Software passend ein; der Schalter muss dazu passen.
Einzelheiten: [`../docs/status-led-oled.md`](../docs/status-led-oled.md)

### 3.4 Funk-Frontend

**Ebyte E07-900M10S**: CC1101, 855–925 MHz, 26-MHz-Quarz ab Werk, 14 × 20 mm,
22 Halblöcher im 1,27-mm-Raster, IPEX-Antennenbuchse.

Die Antenne geht über ein IPEX-Verlängerungskabel auf eine Einbaubuchse in der
Gehäusewand. Auf der Platine entsteht dadurch **keine HF-Leitung** — keine
Impedanzvorgabe, kein Via-Zaun, kein Anpassungsrisiko.

Drei Dinge beim Zubehör:

- **RP-SMA ist nicht SMA.** Bei RP-SMA sind Stift und Buchse vertauscht: die
  Gewinde passen zusammen, innen trifft aber Buchse auf Buchse und es entsteht
  keine Verbindung. Antenne, Kabel und Einbaubuchse müssen demselben Standard
  folgen.
- Das Verlängerungskabel muss **U.FL/IPEX-1** sein. MHF2, MHF3 und MHF4 sehen
  ähnlich aus, passen aber mechanisch nicht.
- Der U.FL-Stecker ist auf rund 30 Steckzyklen ausgelegt und springt unter Zug
  ab. Dafür sitzen **KB1/KB2** neben dem Modul: zwei Löcher für einen
  Kabelbinder als Zugentlastung.

R3 (10 kΩ) hält CSN definiert, solange der 328P im Reset liegt — der SPI-Bus
ist mit dem ISP-Header geteilt.

### 3.5 Programmierung und Prüfung

- **J2**, 6-poliger ISP-Header in Standardbelegung. Darüber werden nach dem
  Aufbau Fuses, Bootloader und Firmware gebrannt — ein USBasp genügt.
- **TP1–TP8**, Prüfpunkte für RESET, +3V3, +5V, GND, TXD, RXD, GDO0 und CS.
- **S1**, Reset-Taster.

---

## 4. Fuses und Bootloader

Externer 8-MHz-Takt, BOD auf 2,7 V (bei 3,3 V Betriebsspannung angemessen):

| Variante | lfuse | hfuse | efuse |
| --- | --- | --- | --- |
| Ohne Bootloader (nur ISP-Flashen) | `0xFF` | `0xD9` | `0xFD` |
| **Mit Optiboot** (MiniCore, 8 MHz extern) | `0xFF` | `0xDE` | `0xFD` |

`lfuse = 0xFF`: CKDIV8 aus, CKOUT aus, SUT = 11, CKSEL = 1111 (externer
Oszillator 8–16 MHz). `efuse = 0xFD`: BODLEVEL = 101 → 2,7 V. Beim Zurücklesen
meldet avrdude `0xFD` je nach Version als `0x05`, weil nur drei Bits
implementiert sind — das ist kein Fehler.

### 4.1 Bootloader ist Pflicht

Mit der Anforderung „Firmware-Update über die Web-UI" ist er gesetzt:
**MiniCore, `ATmega328`, Clock „8 MHz external", Optiboot**, Bootloader-Baudrate
57600 — Optiboot rechnet dasselbe UBRR = 16 wie die Firmware und sendet damit
ebenfalls mit 58823,5 Baud.

Einmalig nach dem Aufbau über J2 gebrannt:

```bash
avrdude -c usbasp -p m328p -B 8 \
        -U lfuse:w:0xFF:m -U hfuse:w:0xDE:m -U efuse:w:0xFD:m \
        -U flash:w:optiboot_atmega328_8MHz_57600.hex:i
avrdude -c usbasp -p m328p -U flash:w:AskSinSniffer328P.hex:i
```

`-B 8` ist beim ersten Zugriff wichtig: ein fabrikfrischer 328P läuft mit
CKDIV8 auf 1 MHz, die ISP-Taktfrequenz muss unter F_CPU/4 liegen.

### 4.2 Firmware-Update im Betrieb

Der Pi-eigene UART führt keine DTR-Leitung — den Reset für den Bootloader
taktet deshalb der Pi selbst, über **GPIO4 (Header-Pin 7) → C8 → RESET**:

```bash
avrdude -c arduino -p m328p -P /dev/ttyAMA0 -b 58824 -D \
        -U flash:w:AskSinSniffer328P.hex:i &
sleep 0.2
gpioset -t0 -c gpiochip0 4=0     # fallende Flanke → Reset-Impuls
gpioset -t0 -c gpiochip0 4=1
wait
```

Zeitverhalten: R2 · C8 = 10 kΩ · 100 nF = 1 ms Zeitkonstante, RESET ist nach
etwa 3 ms wieder auf 3,3 V. Der 328P braucht minimal 2,5 µs. Optiboot wartet
rund 1 s auf ein Kommando, das Fenster ist unkritisch.

Drei Punkte gehören in die Implementierung:

- **GPIO4 bootet mit aktivem internen Pull-up** (BCM-Standard für GPIO 0–8) —
  die Ruhelage ist high, es gibt keinen Reset beim Hochfahren. C8 sperrt
  Gleichspannung ohnehin; nur Flanken kommen durch.
- **Ansteuerung über libgpiod**, nicht über `RPi.GPIO` oder `pigpio` — beide
  funktionieren auf neueren Kerneln bzw. dem Pi 5 nicht mehr. Die
  `gpioset`-Syntax unterscheidet sich zwischen libgpiod v1 und v2, beide
  Varianten abfangen.
- **Beim Loslassen von GPIO4 steigt RESET kurz über VCC** (kapazitive
  Kopplung). Die interne Klemmdiode des 328P fängt das ab — so arbeitet auch
  jeder Arduino Uno.

> Historie: In den Entwürfen V1–V3 lag der Reset auf GPIO2. Das kollidierte
> mit dem I²C-Bus, den das OLED des Status-LED-Projekts braucht — seit V4 ist
> GPIO2/GPIO3 unangetastet durchgereicht und der Reset auf GPIO4 (Abschnitt
> 3.1). Wer 1-Wire nutzt: dessen Standardüberlagerung belegt ebenfalls GPIO4,
> dann `dtoverlay=w1-gpio,gpiopin=…` auf einen anderen Pin legen.

Ein Firmware-Update kann den Bootloader nicht überschreiben (BOOTRST/BOOTSZ
schützen den Bereich). Nur ein fehlgeschlagener Bootloader-Flash über J2 wäre
kritisch, und der passiert einmalig beim Aufbau.

---

## 5. Layout

Umgesetzt in [`kicad/`](kicad/), erzeugt von `generate_pcb.py`. Grundlage ist
die **offizielle KiCad-Vorlage `RaspberryPi-HAT`**: die exakte Position des
40-poligen Sockels, seine Lage auf der **Unterseite** und die beiden
zugehörigen Befestigungsbohrungen kommen von dort und sind nicht nachgebaut.
Der Umriss selbst ist ein eigener (T-Form, siehe oben), weil die Platine
neben dem Pi liegt statt auf ihm.

`check_j1_geometry()` prüft nach dem Platzieren die vier Eckpads von J1
gegen das Pi-Raster und bricht ab, wenn eine Reihe verrutscht ist — die
Lehre aus dem Fehler in v0.0.1.

### 5.1 Lagenaufbau

| Lage | Belegung |
| --- | --- |
| F.Cu | Signale (keine Massefläche) |
| In1.Cu | durchgehende Massefläche |
| In2.Cu | durchgehende Massefläche |
| B.Cu | Signale (keine Massefläche) |

Seit v0.2.0 tragen die **Außenlagen keine Masseauffüllung** mehr. Auf dem
kompakteren Umriss zerfiel sie zwischen den Leiterbahnen in Splitter, die
sich weder zuverlässig verankern noch sauber entfernen ließen. Stattdessen
bekommt **jedes SMD-Massepad vor dem Routen sein eigenes Stützvia** auf die
beiden Innenlagen (`generate_pcb.py`, Freiraum geometrisch geprüft) — die
Abschirmung leisten die durchgehenden Innenflächen.

Zwei Lagen würden reichen, seit keine HF-Leitung mehr auf der Platine liegt.
Die durchgehende Massefläche unter dem Funkmodul und unter dem USB-Paar kostet
beim Platinenhersteller fast nichts und nimmt die Einstreuung von HDMI und
USB3 des Pi spürbar zurück.

Die Flächen sind **für Durchsteckpads thermisch entlastet**, für SMD-Pads voll
angebunden. Die Platine wird von Hand bestückt, und dort sind die Durchsteckpins
das Problem: ihr Pin berührt die Massefläche auf allen vier Lagen und zieht die
Wärme so schnell ab, dass die Lötstelle nicht durchwärmt — bei den acht
Massepins der 40-poligen Buchse der Unterschied zwischen lötbar und nicht
lötbar. Ein SMD-Pad hängt dagegen nur an einer Lage; dort wäre die Entlastung
unnötig und würde beim TQFP-32 mit 0,8 mm Raster nicht einmal genug Speichen
unterbringen.

### 5.2 Platzierung

Das Skript prüft jede Platzierung, bevor es die Datei schreibt: Abstandsflächen
gegeneinander, gegen die beiden Aussparungen, gegen die Bohrungen und gegen den
Rand. Eine sich selbst überlappende Platzierung wird gar nicht erst gespeichert
— sonst erzeugt der DRC einen Schwall von Folgefehlern, die alle dieselbe
Ursache haben.

Leitgedanken:

- **Im Arm liegt nur die Buchse.** Alles andere dort säße über dem PoE-HAT.
- **Funkmodul im hinteren Überstand**, also so weit wie möglich vom Pi und
  von der Reglerecke entfernt — im Rack zeigt die IPEX-Buchse damit direkt
  zum rückwärtigen Antennen-Keystone. Alle Signalpins des E07 liegen auf
  einer Seite und zeigen zum Mikrocontroller; C5 sitzt direkt am VCC-Pin.
- **Peripheriestecker (J5–J7) an der Frontkante** — kurze Wege zum
  OLED-/LED-/Taster-Einsatz an der Rack-Front.
- **Abblockkondensatoren am Pin**, nicht in einer Reihe am Rand.
- **Prüfpunkte** in einer Reihe an der Frontkante, für einen Nadeladapter
  greifbar.
- **Masse-Stützvias vor dem Routen.** Jedes SMD-Massepad bekommt sein Via
  auf die Innenlagen, bevor der Autorouter läuft — sonst belegt der genau
  diese Fläche, und die eng bepinnten Bauteile (ATmega, Funkmodul) kämen
  hinterher nicht mehr an Masse.

### 5.3 Routing

Vollständig maschinell, reproduzierbar über [`rebuild.py`](kicad/rebuild.py):

```text
generate_pcb.py   Umriss, Bauteile, J1-Prüfung, Masse-Stützvias
autoroute.py      Freerouting, Nachrouten offener Reste, Flächenanbindung
finish_board.py   Bestückungsdruck, Markierung, Fertigungsunterlagen
kicad-cli drc     Fehler und Warnungen, beide müssen null sein
```

Masse ist dabei aus dem Autorouter herausgenommen: Sie liegt auf den beiden
Innenlagen, und jedes Massepad hängt über sein Stützvia daran. Ließe man sie
im Autorouter, zöge der zusätzliche Bahnen quer über die Platine, deren
Enden hinterher als unverbunden gemeldet werden — er kennt die Flächen nicht
als Verbindung.

Freerouting arbeitet mit Zufallselementen und liefert bei gleicher Eingabe
nicht zweimal dasselbe Layout; meist ist das Ergebnis fehlerfrei, manchmal
bleibt eine Verbindung offen. `rebuild.py` würfelt deshalb einfach neu, bis
alle Prüfungen durchgehen — statt von Hand nachzubessern und damit die
Reproduzierbarkeit zu verlieren.

### 5.4 Entwurfsregeln

Netzklassen sind in der Projektdatei hinterlegt: `Default` 0,25 mm,
`Power` 0,8 mm, `USB` als Differenzpaar 0,25 mm bei 0,2 mm Abstand. Die
konkrete Breite für 90 Ω hängt vom Lagenaufbau des Fertigers ab und ist mit ihm
abzustimmen — der Wert ist der Startpunkt für einen 1,6-mm-Vierlagenaufbau.

`min_hole_clearance` steht auf 0,15 mm statt der üblichen 0,25 mm. Bindend sind
dort nicht eigene Entscheidungen, sondern die Herstellergeometrie von J4 und S1.

### 5.5 Verbleibende DRC-Meldungen

Acht Meldungen der Art `hole_clearance` bleiben bestehen. Alle stammen aus den
Footprints von **J4** und **S1**: dort liegt der Befestigungsstift des
Steckverbinders innerhalb seines eigenen Schirmpads. Das ist herstellerseitig so
gewollt — der Stift wird auf das Schirmpad gelötet — und lässt sich nicht
beheben, ohne fremde Footprints umzuzeichnen.

### 5.6 Weitere Fertigungshinweise

- **Funkmodul** vollflächig über Masse, C5 direkt am VCC-Pin. Unter dem Modul
  keine Signale führen — das verlangt das Ebyte-Datenblatt in Abschnitt 4.1
  ausdrücklich.
- **USB-Datenpaar** kurz, symmetrisch, möglichst ohne Vias, Bezugsmasse
  durchgehend auf In1.
- **Resonator Y1** so nah wie möglich an XTAL1/XTAL2, Masse-Guard-Ring, keine
  Signale darunter.
- **Antenne** per Pigtail auf eine SMA-Einbaubuchse, von dort mit Kabel
  mindestens 20–30 cm vom Gehäuse weg. Bei Pi 4/5 stören HDMI-Clock und USB3
  im 868-MHz-Bereich messbar. Das Datenblatt warnt zusätzlich davor, die
  Antenne in ein Metallgehäuse zu setzen.

---

## 6. Stückliste

Erzeugt aus dem Schaltplan, nicht von Hand gepflegt:
[`kicad/fab/bom.csv`](kicad/fab/bom.csv) — dieselbe Datei, die im
Fertigungsarchiv liegt. Es gibt bewusst nur diese eine Stückliste; eine
zweite Fassung im Oberverzeichnis war bis 07.08.2026 vorhanden, stammte vom
27.07. und beschrieb noch die abgeschaffte USB-C-Variante mit CP2102N. Wer
sie las, baute ein anderes Gerät.

| Ref | Wert / Typ | Bauform | Menge |
| --- | --- | --- | --- |
| U1 | MCP1754S-3302xCB (JLCPCB-Ersatz: XC6206P332MR-G) | SOT-23-3 | 1 |
| U2 | ATmega328P-AU | TQFP-32 | 1 |
| U3 | Ebyte **E07-900M10S** (CC1101, 855–925 MHz, IPEX; JLCPCB C9900007000) | Modul 14×20 mm | 1 |
| Y1 | Keramikresonator 8 MHz, integr. C (Murata CSTLS8M00G53-B0, JLCPCB C83707) | 3-polig THT | 1 |
| L1 | BLM21PG300 Ferrit | 0805 | 1 |
| R1 | 330 Ω | 0805 | 1 |
| R2, R3 | 10 kΩ | 0805 | 2 |
| R4 | 330 Ω — Serienwiderstand der WS2812-Datenleitung | 0805 | 1 |
| SW1 | Schiebeschalter SPDT **C&K JS102011SAQN** — wählt PWM/GPIO18 oder SPI/GPIO10 | SMD | 1 |
| C1, C2 | 10 µF | 0805 | 2 |
| C3, C4, C5, C8, C9 | 100 nF | 0805 | 5 |
| D1 | LED rot, U_F ≈ 2 V | 0805 | 1 |
| J1 | Buchsenleiste 2×20, 2,54 mm — **auf der Unterseite** | THT | 1 |
| J2 | Stiftleiste 2×3, 2,54 mm (ISP) | THT | 1 |
| J5 | JST-PH 4-polig (OLED, I²C) | THT | 1 |
| J6 | JST-PH 2-polig (Taster) | THT | 1 |
| J7 | JST-PH 3-polig (WS2812) | THT | 1 |
| S1 | Taster Omron B3U-1000P (JLCPCB C231329) | SMD | 1 |
| TP1–TP8 | Prüfpads 1 × 1 mm | – | 8 |
| KB1, KB2 | Kabelbinderlöcher (Zugentlastung Antenne) | 2,1 mm | 2 |

Konkrete Bezugsquellen mit Artikelnummern: [`bestellliste-reichelt.md`](bestellliste-reichelt.md)
und für die JLCPCB-Bestückung [`kicad/fab/jlcpcb_bom.csv`](kicad/fab/jlcpcb_bom.csv).

Extern: 868-MHz-Antenne mit SMA-Stecker, IPEX-auf-SMA-Pigtail,
SMA-Einbaubuchse, Gehäuse.

---

## 7. Fertigungsstand

**Hardware v0.2.0.** Prüfstand:

| Prüfung | Ergebnis |
| --- | --- |
| Schaltplan-ERC | 0 Fehler, 0 Warnungen |
| Netzliste gegen diese Spezifikation | exakt übereinstimmend |
| Platinen-DRC | **0 Fehler, 0 Warnungen, 0 unverbundene Elemente** |
| J1-Padgeometrie gegen die HAT-Vorlage | maschinell geprüft, siehe Errata |

38 Footprints auf vier Lagen, Umriss 88 × 42 mm.
Fertigungsunterlagen liegen in [`kicad/fab/`](kicad/fab/): Gerber für zehn
Lagen, Bohrdaten getrennt nach durchkontaktiert und nicht durchkontaktiert,
Bestückungsdatei, Stückliste, Layout- und Schaltplan-PDF.

### Beim Platinenhersteller

Bestellt wird die **unbestückte Platine**. Vier Lagen, 1,6 mm. Beide Innenlagen
tragen durchgehend Masse, es gibt keine impedanzkontrollierte Leitung — der
Lagenaufbau ist damit unkritisch und muss nicht abgestimmt werden.

Hochzuladen ist **`kicad/AskSin-Analyzer-V3-fertigung.zip`** — 13 Dateien: Kupfer für alle vier Lagen, Lötstopplack beidseitig, Bestückungsdruck
oben und unten, Lötpastenmaske oben, Umriss, Bohrdaten getrennt nach
durchkontaktiert und nicht durchkontaktiert, dazu das Gerber-Jobfile mit dem
Lagenaufbau.

Die übrigen Dateien in [`kicad/fab/`](kicad/fab/) — Layout- und
Schaltplan-PDF, Bestückungsdatei, Stückliste — sind für den Eigenbedarf und
gehören nicht in die Bestellung.

> **Hinweis zum Jobfile.** KiCad leitet die Ordnungszahl der Innenlagen aus
> deren interner Lagen-ID ab statt aus der Position im Stapel und schreibt bei
> einer programmgesteuert erzeugten Platine `Copper,L5,Inr` und `Copper,L7,Inr`,
> wo `L2` und `L3` stehen müssen. `finish_board.py` stellt das nach dem Export
> richtig. Wer die Daten von Hand neu exportiert, muss das nachziehen — sonst
> ordnet ein Fertiger, der das Jobfile auswertet, die Innenlagen falsch ein.

### Bestückung bei JLCPCB

Seit dem 14.08.2026 ist auch das **Funkmodul** maschinell bestückbar:
`E07-900M10S`, JLCPCB-Nummer **C9900007000**, Katalogangabe LCC-22,
20,0 × 14,0 mm, Raster 1,27 mm — Maße und Halbloch-Raster stimmen mit dem
Datenblatt überein. Damit übernimmt JLCPCB **19 der 24 Bauteile**; von Hand
bleiben nur die fünf bedrahteten Steckverbinder J1, J2, J5–J7.

Drei Dinge sind dabei zu beachten:

- Es ist eine **„JLCPCB Assembly"-Position**: Sie wird in die eigene
  Teilebibliothek gekauft und ist ausschließlich für PCBA-Aufträge
  verwendbar — einzeln versenden lässt sie sich nicht.
- Sie zählt als **Extended**, kostet also eine Einrichtungsgebühr je Auftrag.
- **Bestand und Preis sind erst im Bestellportal verbindlich.** Die
  Produktseite nennt beides nicht; vor der Bestellung nachsehen.

Prüfe nach dem Hochladen die Bauteilvorschau, besonders die **Drehlage von
U3**: Das Modul hat einen eigenen Footprint, und eine um 180° verdrehte
Bestückung fällt erst beim Flashen auf.

### Aufbau von Hand

Wer selbst bestückt — danach richtet sich das Layout:

- **Durchsteckpads sind thermisch entlastet**, SMD-Pads voll angebunden
  (Abschnitt 5.1). Ohne das wären die acht Massepins der 40-poligen Buchse
  praktisch nicht zu löten.
- Alle Widerstände und Kondensatoren sind **0805** mit verlängerten Pads für
  Handlötung. Kleiner wird es nicht.
- Das Funkmodul hat **Halblöcher** — die lassen sich von außen anlöten und sind
  deutlich gutmütiger als ein Gehäuse mit Pads unter dem Bauteil. Gutmütig
  heißt aber nicht harmlos: Das Raster beträgt 1,27 mm, und **Pad 16 (MISO)
  liegt direkt neben Pad 17 (MOSI)**. Eine Lötbrücke zwischen diesen beiden
  legt den ISP-Zugang lahm — der Programmierer liest dann seine eigenen Bits
  zurück und meldet `target does not answer`. Am 14.08.2026 an einer von fünf
  Platinen genau so passiert. Nach dem Löten deshalb **J2 Pin 1 gegen Pin 4
  messen: dort darf kein Durchgang sein.** Wer das Modul bei JLCPCB
  mitbestücken lässt, hat diese Fehlerquelle nicht.
- Einziges feines Raster ist der **TQFP-32 des Mikrocontrollers** mit 0,8 mm.
  Mit Flussmittel und Entlötlitze gut beherrschbar; wer mag, nutzt die
  Lötpastenmaske aus `F_Paste.gtp` für eine Schablone.
- **S1** ist ein SMD-Taster mit vier Eckpads. Falls das zu fummelig wird, passt
  an seiner Stelle auch ein bedrahteter 6×6-mm-Taster — dann Platzierung und
  Routing neu erzeugen.

Empfohlene Reihenfolge: TQFP-32 zuerst, dann die passiven Bauteile, dann das
Funkmodul, zuletzt die Steckverbinder und der Taster.

### Nach dem Aufbau

Fuses, Bootloader und Firmware über **J2** brennen (Abschnitt 4.1) — ein USBasp
genügt. Anschließend elektrisch prüfen über **TP1–TP8**: Versorgung, Reset,
serielle Leitungen, GDO0 und CS.

### Beim Einkauf

- **Funkmodul: `E07-900M10S`**, nicht `E07-900MM10S`. Letzterer ist 10 × 10 mm
  groß und hat kein IPEX, nur Stanzlöcher.
- **Antenne, Verlängerung und Einbaubuchse müssen demselben Standard folgen.**
  Bei RP-SMA sind Stift und Buchse gegenüber SMA vertauscht: die Gewinde passen,
  innen trifft aber Buchse auf Buchse. Das Verlängerungskabel muss
  **U.FL/IPEX-1** sein; MHF2, MHF3 und MHF4 sehen ähnlich aus, passen aber nicht.
- **Baudrate:** Firmware unverändert 57600, Gegenseite 58824 (Abschnitt 2.5).
  Diese Asymmetrie muss dokumentiert bleiben, sonst „korrigiert" sie irgendwann
  jemand zurück und holt sich den 2,12-%-Fehler.

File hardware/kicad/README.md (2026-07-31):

# KiCad-Projekt AskSin-Analyzer V4

KiCad 9. Schaltplan und Layout werden **generiert**, geroutet wird mit
Freerouting.

Stand: **ERC 0 Fehler, 0 Warnungen · DRC 0 Verstöße.** Netzliste stimmt exakt
mit der Spezifikation überein — 32 Bauteile, 25 Netze, 111 Anschlüsse. Platine
vollständig verdrahtet: 330 Leiterbahnen, 157 Durchkontaktierungen, vier Lagen.

## Ablauf

```bash
python3 generate_module_symbol.py     # Symbol des Funkmoduls
python3 generate_module_footprint.py  # Footprint des Funkmoduls
python3 generate_schematic.py         # Schaltplan, Projektdateien, netlist.md
python3 generate_pcb.py               # Umriss, Platzierung, Netze, Flächen
python3 autoroute.py                  # Freerouting + Flächenanbindung

kicad-cli sch erc --output erc.rpt --severity-all AskSin-Analyzer-V3.kicad_sch
kicad-cli sch export netlist --output netlist.net AskSin-Analyzer-V3.kicad_sch
python3 verify_netlist.py netlist.net
kicad-cli pcb drc --output drc.rpt --severity-error AskSin-Analyzer-V3.kicad_pcb
```

⚠️ **Freerouting arbeitet mit Zufallselementen.** Zwei Läufe auf derselben
Eingabe liefern unterschiedliche Ergebnisse — mal null Verstöße, mal zwei bis
drei offene Verbindungen. Die geroutete Platinendatei gehört deshalb ins
Repository und wird **nicht** bei jedem Bauen neu erzeugt. Wer neu routet, prüft
anschließend den DRC.

## Warum generiert

Die Netzliste steht in `generate_schematic.py` und ist die einzige Quelle der
Wahrheit. `verify_netlist.py` liest KiCads eigenen Netzlisten-Export zurück und
vergleicht ihn Knoten für Knoten — der Generator kann eine formal gültige Datei
schreiben, die trotzdem falsch verdrahtet ist.

Der Generator prüft vorab auf Pins in mehreren Netzen und auf Platzierungen, die
sich überlappen, den Umriss verlassen oder auf einer Bohrung liegen. Beides hat
echte Fehler gefangen: der Koppelkondensator C8 der Reset-Strecke war
versehentlich zusätzlich auf Masse gelegt, und der erste Platzierungsentwurf
hatte elf Überlappungen, aus denen der DRC 85 Folgefehler machte — darunter
sechs „Kurzschlüsse", die alle dieselbe Ursache hatten.

## Bauform

L-förmig, 118 × 46 mm umschließend, 3380 mm². Ein schmaler **Arm** trägt die
2×20-Buchse über dem durchgeschleiften Header des Waveshare-PoE-HAT, der
**Körper** sitzt rechts daneben außerhalb des Stapels. Der Lüfter bleibt frei,
und das Funkmodul liegt nicht zwischen zwei Schaltreglern, HDMI und USB3.

Position der Buchse und die beiden Bohrungen im Arm stammen aus der offiziellen
KiCad-Vorlage `RaspberryPi-HAT`. Die beiden hinteren Bohrungen stützen den
auskragenden Körper; **KB1/KB2** sind Kabelbinderlöcher als Zugentlastung für
das Antennenkabel.

## Lagenaufbau

| Lage | Belegung |
| --- | --- |
| F.Cu | Signale, Masseauffüllung |
| In1.Cu | durchgehende Masse |
| In2.Cu | durchgehende Masse |
| B.Cu | Signale, Masseauffüllung |

Ursprünglich lag +3V3 auf In2. Das zwang jedem Versorgungspad ein eigenes
Stützvia auf, wofür in der fertig gerouteten Platine regelmäßig der Platz
fehlte — sieben Pads blieben offen. Das Netz zieht rund 25 mA; als Leiterbahn
mit 0,6 mm ist es reichlich bemessen. Zwei durchgehende Masseflächen schirmen
den Empfänger zudem besser ab. Nach der Umstellung routete Freerouting alle
52 Netze ohne Rest.

Die Anbindung ist **`THT_THERMAL`**: Durchsteckpads bekommen eine thermische
Entlastung, SMD-Pads sind voll angebunden. Die Platine wird von Hand bestückt,
und dort sind die Durchsteckpins das Problem — ihr Pin berührt die Massefläche
auf allen vier Lagen. Volle Anbindung an allen Pads, wie ursprünglich gesetzt,
hätte die acht Massepins der 40-poligen Buchse praktisch unlötbar gemacht.
Umgekehrt ließe eine Entlastung auch der SMD-Pads am TQFP-32 mit 0,8 mm Raster
nicht genug Speichen zu — der DRC meldet das als `starved_thermal`.

## Was der Weg über Freerouting sichtbar gemacht hat

**Die Zonenumrisse waren offene Polygonzüge.** KiCad meldet das nur als
Warnung, aber es war die Ursache eines Absturzes beim Füllen. `SetClosed(True)`
behebt es.

**Die Umrandung im Specctra-Export hat Breite 0** — Freerouting darf dann bis
exakt an die Platinenkante routen. Die Breite zu erhöhen macht es schlimmer:
Freerouting liest die Umrandung dann als Linie statt als geschlossene Grenze und
routet quer durch die Aussparung des L. Von 2 auf 21 Kantenverstöße. Richtig
ist, den Umriss selbst im DSN um 0,55 mm nach innen zu schrumpfen.

**Kleinere Stützvias sparen keinen Platz.** 0,45 mm Durchmesser mit 0,25 mm
Bohrung erzeugte 52 neue Verstöße, weil es die eigenen Entwurfsregeln
unterschritt: 0,3 mm ist die Bohrungsuntergrenze, und mit 0,13 mm Restring folgt
daraus mindestens 0,56 mm Durchmesser.

## Flächenanbindung

Freerouting behandelt die Innenlagen als Versorgungslagen und lässt sie
unangetastet — setzt dorthin aber auch keine Durchkontaktierungen.
`autoroute.py` ergänzt sie in drei Schritten:

1. **Pad-Anbindung** — jeder Massepin bekommt eine Durchkontaktierung, der Weg
   dorthin wird mit A*-Suche gelegt.
2. **Via-Raster** im 3-mm-Abstand über die ganze Platine. Bindet die Auffüllung
   der Außenlagen an die Innenlagen und verbessert die Masseführung unter dem
   Funkmodul.
3. **Gezielte Inselanbindung** — die Auffüllung zerfällt durch die Leiterbahnen
   in Teilflächen; solche ohne Pad und ohne Durchkontaktierung meldet der DRC
   als offene Verbindung. Der Schritt sucht sie mit einem exakten
   Punkt-in-Fläche-Test und setzt gezielt eine Durchkontaktierung hinein.
   Wiederholt, weil jede neue Durchkontaktierung die Auffüllung verändert und
   dabei neue Teilflächen entstehen können.

Schritt 3 war nötig: ein gleichmäßiges Raster allein ließ zuverlässig zwei bis
drei Inseln übrig, unabhängig von der Rasterweite.

## Dateien

| Datei | Rolle |
| --- | --- |
| `generate_schematic.py` | Netzliste, Bestückung — hier wird geändert |
| `generate_module_symbol.py` | Symbol des CC1101-Moduls, 22 Pins |
| `generate_module_footprint.py` | Footprint aus den Datenblattmaßen |
| `generate_pcb.py` | Umriss, Platzierung, Netze, Flächen |
| `autoroute.py` | Freerouting-Durchlauf und Flächenanbindung |
| `route_pcb.py` | eigener Rasterrouter — Wegsuche und Via-Setzung, von `autoroute.py` mitbenutzt |
| `verify_netlist.py` | vergleicht KiCads Netzlisten-Export mit der Vorgabe |
| `netlist.md` | menschenlesbare Netzliste zur Gegenprobe |
| `erc.rpt`, `drc.rpt`, `bom.csv`, `*.pdf` | Prüf- und Review-Artefakte |

## Funkmodul

`U3` ist ein **Ebyte E07-900M10S** — CC1101, 855–925 MHz, 14 × 20 mm,
22 Halblöcher im 1,27-mm-Raster, IPEX-Antennenbuchse.

Symbol und Footprint sind gegen
[`../datasheets/Ebyte_E07-M_series_specification.pdf`](../datasheets/)
Abschnitt 3.2 verifiziert. Die Maßkette schließt exakt:
`2,00 + 7 × 1,27 + 5,57 + 2 × 1,27 + 1,00 = 20,00 mm`. Das Datenblatt gibt Ober-
und Unterkantenabstand unabhängig an; der Generator bricht ab, wenn die Kette
nicht aufgeht.

⚠️ Beim Einkauf: `E07-900M10S`, **nicht** `E07-900MM10S` — Letzterer ist
10 × 10 mm groß und hat kein IPEX, nur Stanzlöcher.

## Voraussetzungen

```bash
sudo apt install kicad
sudo apt install openjdk-25-jre-headless      # Freerouting 2.x braucht Java 25
mkdir -p ~/.local/share/freerouting
curl -L -o ~/.local/share/freerouting/freerouting-2.2.4.jar \
  https://github.com/freerouting/freerouting/releases/download/v2.2.4/freerouting-2.2.4.jar
```

`autoroute.py` sucht sich das neueste JAR, das mit der installierten
Java-Version wirklich startet, und meldet klar, was fehlt.

## Was noch fehlt

- Bestückungsdruck aufräumen: die Bezeichner stehen an Vorgabepositionen und
  überlappen teils. Für die Fertigung unkritisch, für die Bestückungskontrolle
  unschön.
- 3D-Modelle sind nicht installiert; die Darstellung zeigt nur Pads.
- Lagenaufbau und Impedanz mit dem Fertiger abstimmen.

## Lizenz

Abgeleitet von **AskSin-Analyzer-XS-RPi V1.1** (der-pw), CC BY-NC-SA 4.0.
Diese Ableitung steht unter derselben Lizenz. Namensnennung ist Pflicht.

## Fertigungsprüfung

`python3 pruefe_fertigung.py` beantwortet die Frage „kann das so in
Produktion?" und prüft, was DRC und Netzlistenvergleich nicht abdecken:
Lagenaufbau, geschlossener Umriss, kleinster Bohrer und Via-Ring gegen die
Herstellermindestmaße, das Bohrbild gegen das Pi-Raster 58 × 49 mm, die Lage
der 2×20-Buchse gegen die HAT-Vorlage, Polung der Status-LED, Verdrahtung und
Beschriftung des Umschalters, Vollständigkeit des Fertigungsarchivs sowie
Deckungsgleichheit von BOM, CPL und Platine.

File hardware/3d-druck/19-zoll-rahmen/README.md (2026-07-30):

# 3D-Druck: 19″-Einbaurahmen

Druckvorlagen für den 19-Zoll-Rahmen, mit dem der Analyzer in den
Datenschrank einzieht.

> **Der Front-Einsatz gibt es in zwei Varianten** — `_RPI4` und `_RPI5`.
> Sie unterscheiden sich in der Frontplatte, weil Pi 4 und Pi 5 ihre
> Anschlüsse unterschiedlich anordnen. Rahmen und SSD-Einsatz sind für
> beide gleich. Silvios eigener Aufbau nutzt den **Pi 5** mit dem dazu
> passenden PoE-HAT.

## Herkunft und Lizenz

Die Vorlagen sind **abgeleitete Versionen** (Remixe) aus zwei Projekten:

- **Rahmen (Links/Mitte/Rechts) und Tray-Einsätze:** „19″ 1U Rack with
  Moduler trays for Raspberry Pis" von **Robert** (auf Thingiverse:
  Rob_Z71) —
  <https://www.printables.com/model/69176-19-1u-rack-with-moduler-trays-for-raspberry-pis>
  (auch auf Thingiverse: <https://www.thingiverse.com/thing:4886186>)
- **SSD-Einsatz:** „2.5 SSD/HDD Hot swap holder for Modular trays"
  von **balazsgrill** —
  <https://www.printables.com/model/1433279-25-ssdhdd-hot-swap-holder-for-modular-trays>

Beide Originale stehen unter **CC BY-NC-SA 4.0** (Namensnennung — nicht
kommerziell — Weitergabe unter gleichen Bedingungen). Wegen der
Share-Alike-Bedingung gilt für alle abgeleiteten Dateien in diesem
Verzeichnis dieselbe Lizenz: **CC BY-NC-SA 4.0** —
<https://creativecommons.org/licenses/by-nc-sa/4.0/>

Das fügt sich nahtlos in die Lizenzstrategie des Projekts: die
Analyzer-Hardware steht ohnehin unter CC BY-NC-SA 4.0.

## Die Teile

| Datei | Teil | Maße (BBox) |
| --- | --- | --- |
| `Asksin-Analyzer Rahmen 19Zoll-Links.stl` | Rahmen, linkes Segment | 169 × 50 × 76 mm |
| `Asksin-Analyzer Rahmen 19Zoll-Mitte.stl` | Rahmen, mittleres Segment | 149 × 50 × 76 mm |
| `Asksin-Analyzer Rahmen 19Zoll-Rechts.stl` | Rahmen, rechtes Segment | 169 × 50 × 76 mm |
| `Asksin-Analyzer Rahmen 19Zoll-SSD.stl` | Einsatz für den 2,5″-SSD-Wechselrahmen | 140 × 144 × 69 mm |
| `Asksin-Analyzer Rahmen 19Zoll-OLED-LED-SWITCH_RPI4.stl` | Front-Einsatz für OLED, Status-LED und Taster — **Raspberry Pi 4** | 140 × 40 × 69 mm |
| `Asksin-Analyzer Rahmen 19Zoll-OLED-LED-SWITCH_RPI5.stl` | dasselbe für den **Raspberry Pi 5** | 140 × 40 × 69 mm |

**Der reine Rahmen besteht aus drei Dateien:** Links + Mitte + Rechts —
zusammengesetzt ergeben sie die 19″-Front (169 + 149 + 169 mm ergeben mit
den Überlappungen die 482,6 mm eines 19-Zoll-Einschubs). SSD- und
OLED-LED-SWITCH-Einsatz kommen je nach Ausstattung dazu — vom
Front-Einsatz **genau eine** der beiden Varianten, passend zum verbauten Pi.

Die beiden Varianten sind außen maßgleich und unterscheiden sich fast
ausschließlich in der **Frontplatte**: 87 % der Geometrieunterschiede liegen
in den vordersten 6 mm, also bei den Ausschnitten. Innen sind sie bis auf
Kleinigkeiten identisch (Materialvolumen 36,2 gegen 36,3 cm³).

## Montage

### Einsatz OLED-LED-SWITCH — rechts im Rahmen

1. **Vor dem Einsetzen** OLED, WS2812B und Taster einbauen. OLED und
   WS2812B am besten mit etwas Heißkleber arretieren.
2. Der **Raspberry Pi 5 mit seinem PoE-HAT und der Analyzer-Platine**
   wird mit **M2-Schrauben von unten** an die Halterung geschraubt.
3. Im **oberen Teil** des Drucks sitzen **zwei Keystone-Module**:
   - 1 × **USB3/USB3**
   - 1 × **Antenne** — SMA oder RP-SMA, je nachdem, welchem Standard
     IPEX-Kabel und Antenne folgen
4. Verkabelung über die Keystones:
   - hinterer USB3-Anschluss ← SATA-USB-Kabel von der SSD;
     vorderer USB3-Anschluss → **15-cm-USB-Brückenkabel** zum Pi
   - Antenne genauso: hinten das IPEX-auf-SMA(RP-SMA)-Kabel,
     vorn die externe Antenne

### Einsatz SSD — mittig im Rahmen

1. Am **hinteren Ende** den **SATA-SATA-Adapter** befestigen.
2. Das **SATA-USB-Kabel** verbindet die SSD über den hinteren
   Keystone-Anschluss mit dem Pi.
3. Passende **2,5″-SSD-Wechselrahmen** kommen als Beispiel in den
   [Einkaufsführer](../../../docs/einkaufsfuehrer.md) — am schnellsten
   findet man sie bei AliExpress.

## Noch offen

- `druckhinweise.md` — Material, Schichthöhe, Ausrichtung, Stützen,
  Toleranzen (folgt aus den Erfahrungen der Testdrucke)
- Austausch-/Quellformate (`*.step`, bearbeitbares Original), falls
  vorhanden

## Prüfstand der Dateien

Geprüft am 30.07.2026 (binäres STL, Dreieckszahl gegen Dateigröße,
Kantenpaarung, Materialvolumen):

| Datei | Dreiecke | Volumen | Netz |
| --- | ---: | ---: | --- |
| Links | 1 200 | 95,9 cm³ | geschlossen |
| Mitte | 1 392 | 87,6 cm³ | geschlossen |
| Rechts | 1 480 | 96,0 cm³ | geschlossen¹ |
| SSD | 3 880 | 59,4 cm³ | geschlossen |
| OLED-LED-SWITCH RPI4 | 6 658 | 36,2 cm³ | geschlossen¹ |
| OLED-LED-SWITCH RPI5 | 7 226 | 36,3 cm³ | geschlossen¹ |

¹ Diese Dateien enthalten drei bis vier **entartete Dreiecke** (drei Punkte
auf einer Linie, Fläche null). Jeder Slicer verwirft sie stillschweigend;
sie sind kein Loch im Netz und kein Grund, etwas zu ändern. Nur der Vollständigkeit
halber vermerkt, damit eine entsprechende Meldung im Slicer niemanden beunruhigt.

Gesamtmaterial für einen kompletten Analyzer (Rahmen + SSD- +
Front-Einsatz): rund 375 cm³ Vollkörper, also je nach Füllgrad grob
150–250 g Filament.

## Rahmenbedingungen

- Befestigung der Platine über die vier Bohrungen MH1–MH4 (M2,5,
  Lochabstände in [`../../README.md`](../../README.md), Abschnitt Platine)
- Antennenbuchse (SMA-Einbau), Zugentlastung und SSD brauchen Platz im
  Rahmen — Maße siehe Hardware-Spezifikation
- Zubehör wie SSD-Wechselrahmen und Keystone-Module sind im
  Einkaufsführer beschrieben: [`../../../docs/einkaufsfuehrer.md`](../../../docs/einkaufsfuehrer.md)

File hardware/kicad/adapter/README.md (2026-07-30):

# J1-Rettungsadapter (für Platinen der Hardware v0.0.1)

> ⚠️ **Warum es dieses Bauteil gibt:** Auf allen 2026 gefertigten Platinen
> (Bestückungsdruck „HW v0.0.1") ist die 2×20-Buchse J1 gespiegelt. Direkt auf
> den Pi gesteckt landet jedes Pad auf dem falschen Pi-Pin — 5 V auf 3,3 V,
> Masse auf GPIOs. **Diese Platinen niemals ohne Adapter aufstecken und
> einschalten.** Mit dem Adapter sind sie voll funktionsfähig.

## Das Fehlerbild, ausgemessen

Alle Maße ab der vorderen Platinenkante (der Kante, die beim Pi zur
Platinenkante zeigt):

| | gerade Pins (2, 4, 6 …) | ungerade Pins (1, 3, 5 …) |
| --- | --- | --- |
| Raspberry Pi / PoE-HAT | **2,23 mm** | 4,77 mm |
| Analyzer-Platine v0.0.1 | **7,31 mm** | 4,77 mm |

Die ungerade Reihe sitzt richtig; die gerade liegt nicht *zwischen* ungerader
Reihe und Kante, sondern dahinter. Kein einziger Pin trifft.

## Wie der Adapter das löst

Nicht durch Umsortieren einzelner Reihen, sondern indem das **ganze Steckbild
um 2,54 mm nach hinten versetzt** wird — dann stimmt die Reihenfolge wieder:

```text
    ┌───────────────────────────┐  Analyzer-Platine (v0.0.1)
    │  Buchse 2x20 (unten dran) │
    └──┬───────────────────────┬┘
       │ Stiftleiste 2x20      │     ← Adapter oben, Reihen 7,31 / 9,85 mm
    ┌──┴───────────────────────┴──┐
    │        A D A P T E R        │  65 × 14 mm, 2 Lagen
    └──┬───────────────────────┬──┘
       │ Buchsenleiste 2x20    │     ← Adapter unten, Reihen 2,23 / 4,77 mm
    ┌──┴───────────────────────┴──┐
    │  Stiftleiste des PoE-HAT    │
    └─────────────────────────────┘
```

Jeder Pin geht schnurstracks von unten nach oben: Pin n der Buchse auf Pin n
der Stiftleiste. Die ungeraden Bahnen laufen 2,54 mm auf der Oberseite, die
geraden 7,62 mm auf der Unterseite an den Pads vorbei. Keine Durchkontaktierung
nötig — bedrahtete Pads liegen ohnehin auf beiden Lagen.

## Stückliste — zwei Standardteile

| Ref | Bauteil | Lage | JLCPCB |
| --- | --- | --- | --- |
| **J1** | Buchsenleiste **2×20**, RM 2,54, gerade, Höhe 8,5 mm | **unten** (Körper zeigt zum PoE-HAT) | **C2977589** (ZHOURI), Extended |
| **J2** | Stiftleiste **2×20**, RM 2,54, gerade, Steckstift 6 mm | **oben** (Körper zeigt zur Analyzer-Platine) | **C50980** (BOOMELE), Extended |

Beides gewöhnliche Massenware. Ausdrücklich **keine Stapelbuchsen**, keine
besonderen Pinlängen — es gibt nichts, was in der Höhe zueinander passen
müsste.

> **Zur Teileauswahl (Stand 30.07.2026):** Die naheliegende Buchsenleiste
> C50982 führt LCSC derzeit als „not available"; deshalb C2977589 mit rund
> 47 000 Stück auf Lager. Beide Positionen sind bei JLCPCB als *Extended*
> geführt (einmalige Einrichtungsgebühr je Teil) und laut Teileseite per
> **Wellenlöten** in Economic *und* Standard PCBA bestückbar.

## Komplettbestückung bei JLCPCB

Möglich — aber es gibt eine Bedingung, die man kennen muss: Die beiden
Leisten sind bedrahtet und sitzen auf **verschiedenen Seiten** der Platine.
Das geht nur mit **Standard PCBA**, das laut Fähigkeitsübersicht „single &
double sided placement (SMT/Thru-hole)" beherrscht; die günstigere
Economic-Variante bestückt nur eine Seite.

Hochladen:

| Schritt | Datei |
| --- | --- |
| Platine | Inhalt von [`fab/gerber/`](fab/gerber/) bzw. das komplette [Fertigungspaket](fab/AskSin-Adapter-J1-fertigung.zip) |
| BOM | [`fab/jlcpcb_bom.csv`](fab/jlcpcb_bom.csv) |
| CPL | [`fab/jlcpcb_cpl.csv`](fab/jlcpcb_cpl.csv) |

Die CPL nennt für J1 ausdrücklich `bottom` und für J2 `top` — beides muss in
der Bestückungsvorschau so ankommen. Weil beide Leisten symmetrische Blöcke
sind, wäre ein Drehfehler um 180° folgenlos; entscheidend ist nur, dass jede
Leiste längs auf ihrer Padreihe liegt und auf der richtigen Seite sitzt.
Pin 1 ist auf beiden Seiten im Bestückungsdruck markiert.

**Die Alternative:** nur die nackte Platine bestellen (ein paar Euro für
fünf Stück) und die zwei Leisten selbst löten. 80 Lötstellen je Platine, aber
ohne Einrichtungsgebühren und ohne Rückfragen zur beidseitigen Bestückung.

## Was der Adapter kostet

- **Bauhöhe:** rund 10 mm zusätzlich im Stapel. Bei der Tray-Höhe im
  19-Zoll-Rahmen berücksichtigen.
- **Versatz:** Die Analyzer-Platine sitzt **2,54 mm weiter hinten** als
  vorgesehen; ihre Bohrungen MH1/MH2 fluchten dann nicht mehr mit den
  Abstandsbolzen des Pi. Im 19-Zoll-Rahmen wird sie ohnehin an der
  Druckhalterung verschraubt; ansonsten helfen Nylon-Distanzstücke.

## Fertigung

2 Lagen, 65 × 14 mm — die einfachste Platine, die ein Hersteller anbietet.
Upload-Paket: [`fab/AskSin-Adapter-J1-fertigung.zip`](fab/AskSin-Adapter-J1-fertigung.zip),
Einzeldateien in [`fab/gerber/`](fab/gerber/), Lagenbild zur Kontrolle in
[`fab/adapter-layout.pdf`](fab/adapter-layout.pdf).

Die Bestückungsseite ist im Druck beschriftet: oben „Analyzer-Platine hier
oben aufstecken", unten „Diese Seite auf den PoE-HAT".

## Prüfung

Erzeugt von [`generate_adapter.py`](generate_adapter.py). Die Netze werden dort
**nach gemessener Pad-Position** vergeben, nicht nach Pad-Nummer — genau die
Verwechslung, an der die Platine v0.0.1 gescheitert ist, kann so nicht mehr
passieren.

Unabhängig davon prüft [`verify_adapter.py`](verify_adapter.py) das fertige
Layout gegen die beiden Gegenstücke und verlangt, dass sich beide Steckbilder
mit **einem einzigen** Versatz decken (jeder abweichende Pin wäre ein falsches
Signal):

```console
$ python3 verify_adapter.py
  A) Unterseite gegen Pi/PoE-HAT: PASST — einheitlicher Versatz +0.00 / +0.00 mm über alle 40 Pins
  B) Oberseite gegen die gefertigte Platine v0.0.1: PASST — einheitlicher Versatz +0.00 / +2.54 mm über alle 40 Pins

Der Adapter passt auf beiden Seiten.
```

Verglichen wird gegen die **offizielle KiCad-Vorlage `RaspberryPi-HAT`** und
gegen den Platinenstand aus dem Git-Tag `hardware-v0.0.1` — also gegen das,
was tatsächlich beim Fertiger lag, nicht gegen den heutigen Entwurf.
DRC: 0 Fehler, 0 Warnungen, 0 unverbundene Elemente.

Vor dem ersten Einschalten trotzdem mit dem Multimeter gegenprüfen (Adapter
gesteckt, Analyzer-Platine gesteckt, Pi **aus**): Durchgang von Pi-Pin 2 (5 V)
zum Eingang von U1 auf der Analyzer-Platine, und **kein** Durchgang zwischen
Pi-Pin 1 (3,3 V) und Masse.

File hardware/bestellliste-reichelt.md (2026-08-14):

# Bestellliste AskSin-Analyzer V4

Bauteile für **eine** Platine. Grundlage ist die aus dem Schaltplan erzeugte
Stückliste [`kicad/fab/stueckliste.csv`](kicad/fab/stueckliste.csv).

Alle Angaben zu reichelt.de am 28.07.2026 geprüft. Wo eine
Artikelbezeichnung steht, wurde sie dort gefunden; wo nur ein Suchbegriff
steht, gibt es die Position zwar, aber ich habe die konkrete Variante nicht
verifiziert.

> **Hinweis bei JLCPCB-Bestückung (Stand 30.07.2026):** Wer die Platine mit
> der JLCPCB-Bestückung aus `kicad/fab/jlcpcb_bom.csv` fertigen lässt,
> braucht von dieser Liste nur noch die **Handbestückungs-Teile**: U3
> (Funkmodul), J1, J2, J5–J7 sowie das Zubehör aus Abschnitt 4. Alles
> andere — einschließlich Y1 (Resonator, JLCPCB **C83707**), S1 (Taster,
> JLCPCB **C231329**), R4 (330 Ω, JLCPCB **C17630**) und den Umschalter SW1
> (JLCPCB **C221660**) — lötet JLCPCB.

---

## 1. Bei Reichelt erhältlich — Bezeichnung geprüft

| Pos | Menge | Bauteil | Reichelt-Bezeichnung |
| --- | --- | --- | --- |
| U1 | 1 | LDO 3,3 V / 150 mA, SOT-23-3 | **MCP 1754-3302CB** |
| U2 | 1 | ATmega328P, TQFP-32 | **ATMEGA 328P-AU** |
| Y1 | 1 | Keramikresonator 8,00 MHz, 3-polig, bedrahtet | **CST 8,00** |
| J1 | 1 | Buchsenleiste 2×20, RM 2,54 mm, gerade | **MPE 094-2-040** |
| J2 | 1 | Stiftleiste 2×3, RM 2,54 mm, gerade | **ECON SL6G2** |
| C3, C4, C5, C8, C9 | 5 | Kondensator 100 nF, 0805, X7R, 50 V | **KEM X7R0805 100N** |
| R2, R3 | 2 | Widerstand 10 kΩ, 0805, 1 % | **WAL WR08X1002FTL** |

---

## 2. Bei Reichelt erhältlich — Variante selbst wählen

Diese Positionen führt Reichelt, aber in vielen Varianten. Exakte Werte hier,
Auswahl im Shop.

| Pos | Menge | Bauteil | Suchbegriff | Zu beachten |
| --- | --- | --- | --- | --- |
| C1, C2 | 2 | Kondensator **10 µF**, 0805, X5R/X7R, ≥ 10 V | `Kondensator 0805 10µ` | ≥ 10 V, besser 16 V |
| R1 | 1 | Widerstand **330 Ω**, 0805 | `WR08X3300FTL` bzw. `SMD 0805 330` | Reihe wie bei R2/R3: `WR08X…FTL` |
| R4 | 1 | Widerstand **330 Ω**, 0805 | `WR08X3300FTL` bzw. `SMD 0805 330` | Serienwiderstand der WS2812-Datenleitung — gleicher Wert wie R1 |
| L1 | 1 | Ferritperle **30 Ω @ 100 MHz**, 0805 | `BLM21P` | Reihe BLM21P, 30 Ω / 4 A |
| D1 | 1 | LED 0805, **Flussspannung ≈ 2 V** | `EVL 17-21USRC` | ⚠️ siehe Hinweis unten — die Farbe ist **nicht** frei wählbar |

---

## 3. **Nicht bei Reichelt** — anderweitig beschaffen

| Pos | Menge | Bauteil | Genaue Bezeichnung | Bemerkung |
| --- | --- | --- | --- | --- |
| U3 | 1 | CC1101-Funkmodul | **Ebyte E07-900M10S** | 855–925 MHz, 14 × 20 mm, 22 Halblöcher RM 1,27 mm, **IPEX-Buchse**. Bezugsquellen: cdebyte.com, Antratek, AliExpress — **oder bei JLCPCB mitbestücken lassen: C9900007000** (dann entfällt der Einkauf und das heikelste Handlöten). ⚠️ **Nicht** `E07-900MM10S` — der ist 10 × 10 mm und hat kein IPEX |
| J5 | 1 | Stiftleiste JST-PH, 4-polig, gerade, bedrahtet | **B4B-PH-K-S** | RM 2,00 mm |
| J6 | 1 | Stiftleiste JST-PH, 2-polig, gerade, bedrahtet | **B2B-PH-K-S** | RM 2,00 mm |
| J7 | 1 | Stiftleiste JST-PH, 3-polig, gerade, bedrahtet | **B3B-PH-K-S** | RM 2,00 mm |
| S1 | 1 | Kurzhubtaster SMD, 4 Eckpads | **Omron B3U-1000P** | 3,0 × 1,6 mm |

**Zu den JST-PH-Steckern:** Reichelt führt von der PH-Reihe nur zwei- und
vierpolige Ausführungen, und die nur als SMD-Variante. Gebraucht werden
bedrahtete Stiftleisten in zwei-, drei- und vierpolig. Bezugsquellen: Mouser,
Digi-Key, TME, Reichelt-Alternative Conrad. Wer ohnehin dort bestellt, nimmt
die Gegenstücke gleich mit — siehe Abschnitt 4.

---

## 4. Zubehör, nicht auf der Platine

| Menge | Teil | Bemerkung |
| --- | --- | --- |
| 1 | Buchsengehäuse **PHR-4** + 4 Kontakte **SPH-002T-P0.5S** | Gegenstück zu J5 (OLED) |
| 1 | Buchsengehäuse **PHR-2** + 2 Kontakte SPH-002T-P0.5S | Gegenstück zu J6 (Taster) |
| 1 | Buchsengehäuse **PHR-3** + 3 Kontakte SPH-002T-P0.5S | Gegenstück zu J7 (WS2812) |
| 1 | IPEX-Verlängerung, **U.FL/IPEX-1**, auf SMA-Einbaubuchse | ⚠️ MHF2/3/4 passen mechanisch nicht |
| 1 | Antenne 868 MHz, SMA | ⚠️ **SMA und RP-SMA sind nicht kompatibel** — Antenne, Kabel und Einbaubuchse müssen demselben Standard folgen |
| 1 | Kabelbinder, ≤ 2 mm Breite | Zugentlastung durch KB1/KB2 |
| 4 | Abstandsbolzen M2,5 | Befestigung über MH1–MH4 |
| 1 | ISP-Programmer **USBasp** | Einmalig für Fuses, Bootloader, Firmware über J2 |

---

## Hinweise

**Umschalten statt umlöten** (seit Hardware v0.2.0). Die WS2812-Datenleitung
läuft über den Schiebeschalter **SW1** an der Außenkante: Stellung **SPI**
(GPIO10, Vorgabe auf dem Pi 5) oder **PWM** (GPIO18, Vorgabe auf Pi 3/4).
Dahinter liegt **ein** gemeinsamer Serienwiderstand R4 = 330 Ω. Die frühere
Bestückungsvariante „R4 oder R5" und damit auch R5 selbst entfallen.

Nicht bei Reichelt: der Schalter **C&K JS102011SAQN** (JLCPCB C221660).

**TP1–TP8 sind keine Bauteile**, sondern Prüfpads auf der Platine.

**Die LED-Farbe ist festgelegt.** D1 muss eine Flussspannung von rund 2 V
haben, also **rot, orange, gelb oder gelbgrün (565–570 nm)**. Blau, Weiß und
echtes Grün (unter etwa 530 nm) sind InGaN-Typen mit rund 3 V Flussspannung —
an 3,3 V Versorgung bleibt dann nichts mehr für den Vorwiderstand übrig, die
LED bliebe dunkel oder glimmte nur, und R1 wäre wirkungslos.

Geprüfte Kandidaten bei Reichelt:

| Artikel | Wellenlänge | U_F | Helligkeit | Strom an R1 |
| --- | --- | --- | --- | --- |
| **EVL 17-21USRC** | 639 nm rot | 2,0 V | 58 mcd | 3,3 mA |
| EVL 17-21/R6C-A | 632 nm rot | 2,3 V | 112 mcd | 2,4 mA |
| EVL 17-21SURC | 632 nm rot | 2,0 V | 15 mcd | 3,3 mA |

**Belastbarkeit der Widerstände:** unkritisch, jede handelsübliche
0805-Bauform mit 125 mW reicht mit großem Abstand.

| Pos | Funktion | Verlustleistung |
| --- | --- | --- |
| R1 | Vorwiderstand Status-LED | ≈ 5 mW (bei roter LED knapp 7 mW) |
| R2, R3 | Pull-up RESET und CS | je ≈ 1 mW |
| R4 | Serienwiderstand Datenleitung WS2812 | < 1 mW — der Eingang der LED ist hochohmig, Strom fließt nur beim Umladen von rund 15 pF |

Auch die Spannungsfestigkeit ist ohne Belang: 0805 sind typisch für 150 V
ausgelegt, auf der Platine liegen maximal 5 V an.

**Mehrere Platinen:** Die passiven Bauteile lohnt es sich gleich in größerer
Stückzahl zu nehmen — 0805-Widerstände und -Kondensatoren kosten bei Reichelt
im Zehnerpack kaum mehr als einzeln, und beim Handlöten geht erfahrungsgemäß
das eine oder andere verloren.

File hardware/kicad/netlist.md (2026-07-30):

# Netzliste AskSin-Analyzer-V3

Generiert aus `generate_schematic.py`. Gegenprobe: `../README.md` Abschnitt 3.

| Netz | Anschlüsse |
| --- | --- |
| `+5V` | J1.2, J1.4, U1.3, TP3.1 |
| `PI_3V3` | J1.1, J5.2, J7.1 |
| `I2C_SDA` | J1.3, J5.4 |
| `I2C_SCL` | J1.5, J5.3 |
| `BTN` | J1.11, J6.1 |
| `LED_PWM` | J1.12, SW1.1 |
| `LED_SPI` | J1.19, SW1.3 |
| `WS_WAHL` | SW1.2, R4.1 |
| `WS_DATA` | R4.2, J7.2 |
| `VREG_OUT` | U1.2, C1.1, L1.1 |
| `+3V3` | L1.2, C2.1, U2.4, U2.6, U2.18, C3.1, C4.1, U3.9, C5.1, R2.1, R3.1, J2.2, TP2.1 |
| `GND` | J1.6, J1.9, J1.14, J1.20, J1.25, J1.30, J1.34, J1.39, J5.1, J6.2, J7.3, U1.1, C1.2, C2.2, C3.2, C4.2, C5.2, C9.2, U2.3, U2.5, U2.21, U3.1, U3.2, U3.3, U3.4, U3.5, U3.11, U3.12, U3.20, U3.22, Y1.2, D1.1, S1.2, J2.6, TP4.1 |
| `UART_PI_TX` | J1.8, U2.30, TP6.1 |
| `UART_328_TX` | U2.31, J1.10, TP5.1 |
| `PI_RESET_DRV` | J1.7, C8.1 |
| `RESET` | C8.2, U2.29, R2.2, TP1.1, S1.1, J2.5 |
| `MOSI` | U2.15, U3.17, J2.4 |
| `MISO` | U2.16, U3.16, J2.1 |
| `SCK` | U2.17, U3.18, J2.3 |
| `CS` | U2.14, U3.19, R3.2, TP8.1 |
| `GDO0` | U2.32, U3.15, TP7.1 |
| `XTAL1` | U2.7, Y1.1 |
| `XTAL2` | U2.8, Y1.3 |
| `AREF` | U2.20, C9.1 |
| `LED_TREIBER` | U2.2, R1.1 |
| `LED_ANODE` | R1.2, D1.2 |

Netze: 26 · Bauteile: 32 · No-Connect-Marker: 42

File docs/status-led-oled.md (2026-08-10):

# Status-LED und OLED am Analyzer (Phase M11)

Die Funktionen des Projekts **Status-LED-OLED** (`ssbingo/Status-LED-OLED`)
sind in den Analyzer integriert — mit Ausnahme der restic-Backup-Funktion, die
Sache des eigenständigen Projekts bleibt.

Die Analyzer-Platine ist dafür vorbereitet:

| Stecker | Zweck | Pins |
| --- | --- | --- |
| **J5** | OLED (I²C, SSD1306) | GPIO2/3 — deshalb liegt der 328P-Reset auf GPIO4 |
| **J6** | Taster | GPIO17, schaltet gegen Masse |
| **J7** | WS2812-Status-LED | SPI/GPIO10 **oder** PWM/GPIO18 — Schiebeschalter SW1 |

---

## 1. Warum das OLED übernommen und nicht nachgebaut ist

Der erste Anlauf hat das Display **in TypeScript nachgebaut**: eigener
SSD1306-Treiber, eigene 5×7-Pixelschrift, eigenes Seitenraster, alles ohne
Fremdbibliothek. Auf dem Gerät war das Ergebnis deutlich schlechter lesbar als
das Vorbild — aus einem Grund, der sich nicht wegoptimieren lässt:

> Das Original zeichnet mit **DejaVuSans-Bold** und sucht die Schriftgröße je
> Wert automatisch: `_fit_font()` probiert von **28 px** abwärts, bis der Text
> in die Breite passt. Eine 5×7-Pixelschrift, ganzzahlig hochskaliert, bleibt
> auch bei 21 px sichtbar grob.

Seit **v0.9.0** kommt deshalb derselbe Stapel zum Einsatz wie im Vorbild:

| Baustein | Wofür |
| --- | --- |
| `board` / `busio` (Blinka) | Zugriff auf den I²C-Bus |
| `adafruit_ssd1306` | Treiber für das Display |
| `PIL` (Pillow) | Zeichnen und Schriften |
| `DejaVuSans-Bold.ttf` | die große Schrift (Paket `fonts-dejavu-core`) |

Übernommen sind Seitenaufbau, Schriftwahl, `_fit_font`, die Feldliste, die
Übersichtsseite und die Zeiten der Tasterauswertung. Ergänzt sind nur die
Werte, die es beim Analyzer zusätzlich gibt.

### Arbeitsteilung zwischen Core und Anzeigedienst

```text
asksin-analyzer (Node, unprivilegiert)
    │  schreibt bei jeder Änderung
    ▼
/var/lib/asksin-analyzer/oled-state.json
    │  wird alle 0,1 s gelesen
    ▼
asksin-analyzer-oled (Python, venv)   ──zeichnet──►  SSD1306 über I²C
    │  legt den fertigen Framebuffer daneben
    ▼
/var/lib/asksin-analyzer/oled-bild.b64
    │
    ▼
Weboberfläche: Live-Vorschau zeigt EXAKT das Bild vom Gerät
```

Der Core liefert nur seine eigenen Werte. Die Systemwerte — IP, MAC, Hostname,
CPU, RAM, Laufzeit, Lüfter, Plattenplatz — liest der Anzeigedienst selbst,
genau wie im Original.

Die Bilddatei ist zugleich das **Lebenszeichen**: Nur wenn sie existiert, gilt
der Anzeigedienst als zeichnend — und nur dann wird der Taster überwacht
(Begründung in Abschnitt 4).

---

## 2. Die Seiten

Reihenfolge: **Standort zuerst**, dann alles zum Analyzer, dann die
Systemwerte des Originals, zuletzt dessen vierzeilige Übersicht.

| # | Label | Wert | Herkunft |
| --- | --- | --- | --- |
| 1 | `Standort` | Anzeigename dieses Analyzers | Analyzer |
| 2 | `Sniffer` | `BEREIT` / `GETRENNT` / `DEMO` | Analyzer |
| 3 | `Telegramme` | z. B. `137/min` | Analyzer |
| 4 | `Rauschen` | z. B. `-91dBm` | Analyzer |
| 5 | `Geräte` | aktive Funkgeräte | Analyzer |
| 6 | `Duty-Cycle` | Spitzenwert in Prozent | Analyzer |
| 7 … | `! <Gerätename>` | Prozent — **je Dauersender eine Seite** | Analyzer |
| … | `Version` | Softwarestand | Analyzer |
| … | `IP`, `MAC`, `Host` | Netzwerk | System |
| … | `CPU` | z. B. `51C L0.42` | System |
| … | `RAM` | z. B. `512/2048MB` | System |
| … | `Up` | Laufzeit, z. B. `21d22h` | System |
| … | `Disk` | freier Platz | System, nur wenn ermittelbar |
| … | `Fan` | Drehzahl in U/min | System, nur wenn ein Lüfter meldet |
| letzte | — | Übersicht: IP, CPU, RAM, Sniffer | wie im Original |

### Dauersender bekommen eigene Seiten

Ein einzelnes defektes Gerät kann das Funknetz zustopfen. Die
Duty-Cycle-Seite zeigt nur den höchsten Wert — **welches** Gerät es ist, sah
man dort nicht. Deshalb bekommt jedes Gerät ab **80 % Duty-Cycle** eine eigene
Seite: Name als Beschriftung oben (mit vorangestelltem `!`), Prozentwert groß
darunter.

Die Schwelle ist `DUTY_ALARM_PROZENT = 80` — dieselbe, die auch die Status-LED
rot blinken lässt. Höchstens **fünf** solcher Seiten, sonst wird das
Durchblättern am Gerät zur Zumutung. Beruhigt sich ein Gerät, verschwindet
seine Seite von selbst.

### Aufbau einer Seite

Kurze Beschriftung oben links, darunter **ein** Wert, waagerecht zentriert und
in der größten Schrift, die in die Breite passt. Kopf- und Fußzeilen gibt es
bewusst nicht — sie müssten in der kleinen Schrift stehen und wären auf einem
0,96-Zoll-Panel nicht mehr zu entziffern.

Die Grenze zwischen Beschriftung und Wert wird **gemessen**, nicht gesetzt:
Wie hoch die Glyphen sind, hängt von der Pillow-Fassung ab. Mit festen
Positionen ragte das eine ins andere. Lange Gerätenamen werden ebenfalls
gemessen gekürzt (mit `…`), nicht nach Zeichenzahl — ein `i` braucht weniger
Platz als ein `W`.

---

## 3. Die Bauhöhe muss stimmen

**128 × 32** (Adafruit PiOLED) ist die Vorgabe und die Einstellung des
Vorbilds. 0,96-Zoll-Module sind meist **128 × 64**.

Der Unterschied ist nicht kosmetisch:

| | 128 × 32 | 128 × 64 |
| --- | --- | --- |
| Multiplex (`0xa8`) | `0x1f` | `0x3f` |
| COM-Pin-Lage (`0xda`) | `0x02` | `0x12` |
| Speicherseiten | 4 | 8 |

Mit den falschen Werten zeigt das Panel ein **verdoppeltes, unleserliches
Bild**. Die Bedingung für die COM-Pins (`Breite > 2 × Höhe`) ist wörtlich aus
`Adafruit_CircuitPython_SSD1306` übernommen, ebenso die Reihenfolge der
Init-Sequenz und `0xad, 0x30` (interne Referenzstromquelle — ohne sie bleiben
viele SSD1315-Nachbauten auffällig dunkel).

Eingestellt wird die Höhe beim Installieren; ändern lässt sie sich später über
`statusanzeige.oledHoehe` in der Konfiguration.

---

## 4. Der Taster an J6

Zeiten wörtlich aus der Konfiguration des Vorbilds:

| Haltedauer | Wirkung | Vorbild-Schlüssel |
| --- | --- | --- |
| ab **50 ms** | eine Seite weiter | `button_debounce_s` |
| ab **5 s** | `Neustart…` auf dem Display | `button_long_press_s` |
| + weitere **3 s** | `systemctl reboot` | `button_reboot_message_s` |

Die drei Sekunden Anzeige sind Absicht: Wer versehentlich zu lange drückt,
sieht noch, was gleich passiert.

**Gemessen wird der Pegel, nicht die Flanke.** Die Ausgabe von `gpiomon`
unterscheidet sich zwischen libgpiod 1 und 2, der über `gpioget` abgefragte
Pegel nicht.

**Neustarten darf der Dienst nicht selbst** — er läuft unprivilegiert. Er
schreibt `/var/lib/asksin-analyzer/neustart-anstoss`; darauf wartet
`asksin-analyzer-neustart.path` und startet einen eng begrenzten Root-Helfer.
Dasselbe Muster wie bei Update und Netzwerkeinstellungen. Die Auslöserdatei
wird **vor** dem Neustart gelöscht — sonst käme der Pi in eine
Neustartschleife.

### Drei Vorkehrungen gegen den offenen Eingang

Der Taster schaltet GPIO17 gegen Masse; einen Pull-up gibt es auf der Platine
nicht. Ohne definierten Ruhepegel **schwebt** der Eingang und erzeugt aus
Einstreuung fortlaufend Flanken — jede davon eine Unterbrechung im Kernel.

1. `gpiomon` läuft mit `--bias=pull-up`. Das betrifft auch den Normalbetrieb
   **mit** Taster: Ohne Ruhepegel blätterte die Anzeige von selbst weiter.
2. Der Taster wird **nur überwacht, wenn der Anzeigedienst zeichnet**. Wer
   kein Zubehör angeschlossen hat, bekommt davon nichts ab. Sonst steht im
   Protokoll: „Anzeigedienst meldet kein Bild — Taster bleibt inaktiv".
3. Kommen dennoch mehr als **50 Flanken je Sekunde**, wird das Lauschen
   eingestellt und gemeldet. Ein Mensch drückt nicht 50-mal je Sekunde.

---

## 5. Die Status-LED (WS2812)

| Farbe | Muster | Bedeutung |
| --- | --- | --- |
| Rot | schnell blinkend | Duty-Cycle-Alarm (≥ 80 %) |
| Rot | dauerhaft | Sniffer getrennt |
| Gelb | langsam blinkend | Persistenz-Fehler |
| Orange | dauerhaft | Demo-Modus |
| Blau | pulsierend | Update verfügbar |
| Grün | dauerhaft | alles in Ordnung |

Prioritätsleiter: Alarm > getrennt > Persistenzfehler > Demo > Update > ok.

### Welche Ansteuerung auf welchem Pi

| | **SPI** (GPIO10) | **PWM** (GPIO18) |
| --- | --- | --- |
| Schalter SW1 | Stellung **SPI** | Stellung **PWM** |
| Vorgabe auf | **Pi 5** | **Pi 3 und Pi 4** |
| Rechte | im Analyzer-Dienst, ohne Root | Root — Dienst `asksin-analyzer-led` |
| Onboard-Audio | egal | muss aus (`dtparam=audio=off`) |
| Bibliothek | keine, eigener Bitstrom (2,4 MHz, 1→110 / 0→100) | `rpi_ws281x` im venv `led-venv` |
| Taktquelle | `deploy/ws2812-spi.py`, dauerhaft offen | Hilfsdienst setzt es selbst |

**Der SPI-Takt gehört dem Dateideskriptor, nicht dem Gerät.** `spidev_release()`
setzt `speed_hz` beim Schließen des letzten Benutzers auf `spi->max_speed_hz`
zurück. Ein Werkzeug, das den Takt setzt und sich beendet — etwa `spi-config` —
hinterlässt deshalb **nichts**. Bis 0.15.7 wurde genau so vorgegangen; auf
Analyzer 01 (Pi 5) schrieb der Dienst danach mit 125 MHz statt 2,4 MHz, und die
LED blieb dunkel, obwohl auf der Datenleitung ein Signal lag und die gesamte
Verdrahtung fehlerfrei war. Seit 0.15.8 setzt `deploy/ws2812-spi.py` den Takt
und **bleibt offen**, solange die Anzeige läuft; er liest den Wert zurück und
bricht bei mehr als 10 % Abweichung mit einer Meldung ab.

Gemessen wurde das Fenster, in dem die WS2812 unsere Kodierung annimmt: **2,0
bis 3,2 MHz** SPI-Takt, also 667–1067 kHz Bitrate. Bei 1,0/1,2/1,6 und 4,0 MHz
bleibt sie dunkel. Die 2,4 MHz liegen mittig darin.

Auf **Pi 3 und Pi 4** leitet sich der SPI-Takt vom Kerntakt ab und wandert mit
dessen Skalierung — das zerreißt das WS2812-Timing (Flackern, Farbsprünge).
Auf dem **Pi 5** hängen die GPIOs am RP1; die PWM/DMA-Bibliotheken sprechen
die alte BCM-Hardware an und funktionieren dort nicht. Der PWM-Weg ist auf dem
Pi 5 deshalb **dreifach gesperrt** (Installer, Update, Skript selbst): Im
ungünstigen Fall schreibt ein DMA-Kanal in fremden Speicher und hängt den
Rechner auf, ohne eine Zeile im Journal zu hinterlassen.

Im PWM-Betrieb bleibt der Analyzer-Dienst unprivilegiert und schreibt die
fertige Farbe als `r,g,b` nach `/var/lib/asksin-analyzer/led-farbe`; der kleine
Root-Dienst [`deploy/led-pwm.py`](../deploy/led-pwm.py) setzt sie.

**Umschalten ohne Lötkolben:** Seit Hardware v0.2.0 wählt der
SMD-Schiebeschalter **SW1** zwischen GPIO18 (PWM) und GPIO10 (SPI); dahinter
liegt ein gemeinsamer 330-Ω-Serienwiderstand R4. Die frühere
Bestückungsvariante „R4 **oder** R5" entfällt.

**Die LED ist immer eine WS2812B**, versorgt mit **3,3 V** vom Pi (J7 Pin 1).
Das ist Absicht: Bei 5 V Versorgung erwartet die LED rund 3,5 V für „High", die
der Pi mit 3,3 V nicht liefert. Mit 3,3-V-Versorgung passt der Pegel.

⚠️ Der Schiebeschalter **SW1** muss zur gewählten Betriebsart passen.

---

## 6. Einrichtung

Der Installer fragt „Status-LED und OLED-Anzeige einrichten?" und danach die
Bauhöhe. Die eigentliche Einrichtung steht in einem eigenen Skript, damit sie
sich nach einem Fehlschlag einzeln wiederholen lässt:

```bash
sudo /opt/asksin-analyzer/deploy/oled-einrichten.sh 32     # oder 64
```

Es installiert die Systempakete, legt das venv an, installiert die
Bibliotheken, richtet den Dienst ein und prüft zum Schluss, ob sich auf dem
I²C-Bus überhaupt ein Display meldet.

### Warum die apt-Pakete vorher kommen

`pip install adafruit-blinka` zieht **lgpio** nach und baut es aus dem
Quellcode. Fehlt `swig`, bricht es ab:

```text
error: command 'swig' failed: No such file or directory
```

Fehlt die C-Bibliothek, scheitert der Linker:

```text
/usr/bin/ld: cannot find -llgpio
```

Raspberry Pi OS liefert lgpio längst als fertiges Paket **`python3-lgpio`** —
gebaut werden muss also gar nichts. Deshalb: erst die apt-Pakete, dann ein
venv **mit** `--system-site-packages`, damit pip die fertigen Pakete sieht.
`swig`, die Header und `liblgpio-dev` kommen trotzdem mit, falls das Paket auf
einer Ausgabe fehlt.

> **Achtung nach einem Fehlschlag:** Ein venv **ohne**
> `--system-site-packages` bleibt sonst liegen und ist von außen nicht von
> einem guten zu unterscheiden. Das Skript prüft deshalb
> `include-system-site-packages` in `pyvenv.cfg` und legt die Umgebung neu an,
> wenn der Schalter fehlt.

### Warum die Unit ein Arbeitsverzeichnis braucht

lgpio legt Benachrichtigungs-Pipes im Arbeitsverzeichnis an — erst `$LG_WD`,
ersatzweise `$HOME`, ersatzweise `"."`. Ohne diese Angaben landet es bei
`//.lgd-nfy0` und bricht ab:

```text
xCreatePipe: Can't set permissions (436) for //.lgd-nfy0
[Errno 2] No such file or directory: '.lgd-nfy-3'
```

`WorkingDirectory`, `HOME` und `LG_WD` zeigen deshalb auf
`/var/lib/asksin-analyzer`.

> In der Unit steht **kein `DeviceAllow`**. Sobald eine solche Zeile existiert,
> schaltet systemd auf `DevicePolicy=closed` und sperrt jedes nicht genannte
> Gerät — damit auch die `gpiochip`-Knoten, über die Blinka arbeitet. Gemeint
> war eine Erlaubnis, gewirkt hat ein Verbot. Der Zugriff auf `/dev/i2c-1`
> kommt über die Gruppe `i2c`.

---

## 7. Beteiligte Dienste, Dateien und Werkzeuge

| Einheit | Zweck |
| --- | --- |
| `asksin-analyzer-oled.service` | zeichnet das Display (Python, venv) |
| `asksin-analyzer-led.service` | WS2812 über PWM — **nur Pi 3/4** |
| `asksin-analyzer-neustart.path` / `.service` | Neustart bei langem Tastendruck |

| Datei unter `/var/lib/asksin-analyzer/` | Inhalt |
| --- | --- |
| `oled-state.json` | Werte des Analyzers + aktuelle Seite |
| `oled-bild.b64` | letzter Framebuffer, Seitenzahl, Bauhöhe |
| `led-farbe` | `r,g,b` für den PWM-Hilfsdienst |
| `neustart-anstoss` | Auslöser für den Root-Helfer |

| Werkzeug | Zweck |
| --- | --- |
| `deploy/oled-einrichten.sh` | Einrichtung, einzeln wiederholbar |
| `deploy/oled-vorschau.py` | rendert die Seiten als PNG — **aus dem Code des Geräts** |

`oled-vorschau.py` schiebt der Zeichenklasse ein Ersatz-Display unter, statt
einen zweiten Renderer zu pflegen. Damit kann das Bild im Handbuch nicht mehr
von dem abweichen, was auf dem Panel steht.

---

## 8. In der Weboberfläche

Die Übersicht zeigt bei aktiver Anzeige den Bereich **Status-LED & OLED**: den
LED-Punkt in Echtfarbe mit Klartext-Grund, Störungsmeldungen je Teil und eine
**Live-Vorschau des Displays** samt Blättern-Knopf — seit v0.9.0 das echte
Bild vom Gerät, nicht mehr ein Nachbau davon.

Aktivierung, Ansteuerungsart und Helligkeit stehen unter **Einstellungen →
Status-LED & OLED**, sofort wirksam und ohne Neustart.

---

## 9. Was nicht übernommen wurde

Die **restic-Backup-Funktion** des Vorlagenprojekts. Sie bleibt Sache des
eigenständigen Status-LED-OLED-Projekts.

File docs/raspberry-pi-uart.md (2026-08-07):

# UART-Konfiguration für Raspberry Pi 3, 4 und 5

> **Stand V4:** Die Platine ist ein reiner Pi-Aufsatz, dieses Dokument ist
> damit Pflichtlektüre für jede Inbetriebnahme. (Der USB-Zweig aus dem
> V3-Entwurf ist entfallen.)

Ziel: Auf **allen drei Modellen** liegt am Ende dieselbe Gerätedatei an
GPIO14/15 — `/dev/ttyAMA0`, eine echte PL011-/RP1-UART, keine miniUART, keine
serielle Konsole. Der Core-Dienst muss dann nicht nach Modell verzweigen.

---

## 1. Warum das je Modell anders aussieht

| Modell | SoC | UART an GPIO14/15 *ab Werk* | Problem |
| --- | --- | --- | --- |
| Pi 3 | BCM2837 | miniUART (`/dev/ttyS0`) | Bluetooth belegt die PL011. Die miniUART leitet ihre Baudrate vom Core-Takt ab — taktet der herunter, driftet die Baudrate |
| Pi 4 | BCM2711 | miniUART (`/dev/ttyS0`) | wie Pi 3 |
| Pi 5 | BCM2712 + RP1 | **keine** | Die primäre Debug-UART liegt am dedizierten 3-poligen Connector neben den HDMI-Buchsen (`/dev/ttyAMA10`). GPIO14/15 sind unbelegt, bis man sie einschaltet |

Die miniUART bei 57600 Baud ohne festgenagelten Core-Takt ist genau die Quelle
der sporadischen Empfangsfehler, die dieser Platine im Forum nachhängen. Wir
umgehen sie vollständig.

## 2. Die Konfiguration

`config.txt` liegt ab Bookworm unter `/boot/firmware/config.txt`, davor unter
`/boot/config.txt`. Gleiches gilt für `cmdline.txt`.

### Pi 3 und Pi 4

```ini
# /boot/firmware/config.txt
enable_uart=1
dtoverlay=disable-bt
```

`disable-bt` schaltet das Bluetooth-Modem ab und gibt die PL011 an GPIO14/15
frei — sie erscheint als `/dev/ttyAMA0`, `/dev/serial0` zeigt darauf. Zusätzlich:

```bash
sudo systemctl disable --now hciuart
```

Ohne das versucht `hciuart` weiterhin, ein Bluetooth-Modem an der UART zu
attachen.

### Pi 5

```ini
# /boot/firmware/config.txt
dtparam=uart0=on
```

Alternativ `dtoverlay=uart0-pi5`, gleiche Wirkung. Ergebnis ist ebenfalls
`/dev/ttyAMA0`. `disable-bt` ist hier **nicht** nötig und auch nicht wirksam —
das Bluetooth-Modem des Pi 5 hängt nicht an dieser UART.

Nicht verwenden: `dtparam=uart0_console`. Das würde die Konsole auf GPIO14/15
legen — genau das, was wir nicht wollen.

### Auf allen Modellen: Konsole abschalten

In `cmdline.txt` muss `console=serial0,115200` (bzw. `console=ttyAMA0,115200`)
entfernt werden. Sonst schreibt getty in dieselbe Schnittstelle, aus der wir
lesen. Zusätzlich:

```bash
sudo systemctl disable --now serial-getty@ttyAMA0.service
sudo systemctl mask serial-getty@ttyAMA0.service
```

Auf dem Pi 5 bleibt die Konsole über den Debug-Connector (`/dev/ttyAMA10`)
erreichbar — komfortabler als bei Pi 3/4, wo sie damit ganz entfällt.

## 3. GPIO4 als Reset-Leitung

Die Platine nutzt **GPIO4 (Header-Pin 7)** als DTR-Ersatz für den Reset des
328P (`../hardware/README.md`, Abschnitt 4.2). Daraus folgt:

- **I²C-1 bleibt frei** und wird vom OLED des Status-LED-Projekts genutzt —
  `dtparam=i2c_arm=on` ist dafür ausdrücklich erwünscht. (In den Entwürfen
  V1–V3 lag der Reset auf GPIO2 und blockierte den Bus; das ist Geschichte.)
- **1-Wire kollidiert:** `dtoverlay=w1-gpio` legt sich standardmäßig auf
  GPIO4. Wer 1-Wire braucht, verschiebt es mit `gpiopin=` auf einen anderen
  Pin.
- **Ansteuerung über libgpiod** (`gpioset`), nicht über `RPi.GPIO` oder
  `pigpio` — beide funktionieren auf dem Pi 5 nicht mehr. Die Syntax
  unterscheidet sich zwischen libgpiod v1 und v2.
- GPIO4 bootet mit aktivem internen Pull-up (BCM-Standard für GPIO 0–8), die
  Ruhelage ist also definiert high.

## 4. Automatisches Setup

`../hardware/setup-uart.sh` erkennt das Modell über
`/proc/device-tree/model`, schreibt die passenden Zeilen, sichert die
Originaldateien und meldet, was zu tun bleibt:

```bash
sudo ./hardware/setup-uart.sh          # Prüfen und anwenden
sudo ./hardware/setup-uart.sh --check  # nur prüfen, nichts ändern
```

Nach dem Neustart verifizieren:

```bash
ls -l /dev/serial* /dev/ttyAMA*
# erwartet: /dev/ttyAMA0 vorhanden

# Rohdaten sehen — 58824, nicht 57600. Begründung siehe unten.
# stty beherrscht nur genormte Raten und lehnt 58824 ab.
# Deshalb zwei Schritte: erst der Rahmen, dann die exakte Rate.
stty -F /dev/ttyAMA0 57600 raw -echo
sudo python3 /opt/asksin-analyzer/deploy/baudrate.py /dev/ttyAMA0 58824
cat -v /dev/ttyAMA0
```

Erwartete Ausgabe sind Zeilen wie `:5A0A0100103F4B2A1234AB…;` und alle 750 ms
eine kurze Zeile `:5B;` (Grundrauschen). Kommt gar nichts, ist entweder die
Baudrate falsch, die Konsole noch aktiv oder der 328P hat keine Firmware.

## 5. Zugriffsrechte

Der Core-Dienst läuft nicht als root:

```bash
sudo usermod -aG dialout,gpio <dienstbenutzer>
```

`gpio` existiert nicht auf jeder Installation; alternativ eine udev-Regel für
`/dev/gpiochip*`. Das Setup-Skript weist darauf hin.

---

Quellen zur Pi-5-Konfiguration:
[Does Raspberry Pi 5 Support Serial Port on GPIO 14/15](https://forums.raspberrypi.com/viewtopic.php?t=362821) ·
[UART over GPIO 14/15 on the Raspberry Pi 5](https://forums.raspberrypi.com/viewtopic.php?t=378931) ·
[Configuring Pi 5 UARTs](https://forums.raspberrypi.com/viewtopic.php?t=359132) ·
[Need to update UART documentation for Pi5](https://github.com/raspberrypi/documentation/issues/3239)

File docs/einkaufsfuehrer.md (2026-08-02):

# Einkaufsführer Zubehör (Phase M12)

Anforderung (29.07.2026): Die Dokumentation bekommt **Beispiellinks und
Bilder** für die zu bestellende Zubehör-Hardware — als eigenes Kapitel im
Root-README **und** im Handbuch.

## Umfang

| Position | Zweck im Projekt |
| --- | --- |
| **SSD-Wechselrahmen** | Boot-SSD der Pis **ab Pi 4** (SD nur Notbehelf), wartungsfreundlich im Datenschrank; am schnellsten bei AliExpress zu finden (30.07.2026) — Einsatz im 19″-Rahmen: [`hardware/3d-druck/19-zoll-rahmen/`](../hardware/3d-druck/19-zoll-rahmen/README.md). **Nicht für den Pi 3** — der läuft von SD-Karte, siehe unten |
| **OLED-Display** | Statusanzeige an J5 (I²C, Phase M11) |
| **WS2812B** | Status-LED an J7 (Phase M11) |
| **Keystone-Module** | saubere Durchführungen im Datenschrank (RJ45/USB) |
| **SATA-Adapter** | SSD-an-USB-Anbindung des Pi 4 |
| **USB-Verbindungskabel** | Verkabelung Pi ↔ SSD/Peripherie |

Je Position: kurze Anforderungsbeschreibung (worauf es technisch ankommt),
1–2 **Beispiellinks** (Amazon/Reichelt — als Beispiele gekennzeichnet, keine
Affiliate-Links), Bild, ggf. „Finger weg von"-Hinweise (wie bei der
LED-Farben-Erkenntnis in der Reichelt-Liste).

## Bootmedium: SSD ab Pi 4, SD-Karte beim Pi 3

Der Analyzer schreibt rund um die Uhr in seine Datenbank. SD-Karten nutzen
sich dabei ab — deshalb ist der Betrieb von SSD in diesem Projekt der
Standard. **Für den Raspberry Pi 3 gilt das ausdrücklich nicht.**

| | Pi 3 | ab Pi 4 |
| --- | --- | --- |
| Bootmedium | **SD-Karte**, ab 32 GB, Markenware | SSD über USB-SATA |
| Warum | Netzwerk hängt selbst am USB-Bus; nur USB 2.0; Starten von USB ist wacklig | eigener USB-3-Controller, Netzwerk getrennt |
| Rolle im Verbund | nur Client | Client oder Master |

Die drei Gründe im Einzelnen:

1. **Netzwerk und USB teilen sich einen Anschluss.** Beim Pi 3 hängt die
   Netzwerkbuchse selbst am USB-Bus. Eine SSD, die dauernd schreibt, nimmt dem
   Netzwerk Bandbreite weg — und der Analyzer braucht beides gleichzeitig.
2. **Nur USB 2.0.** Statt der 400 MB/s einer SATA-SSD bleiben höchstens 40.
   Der Vorteil gegenüber einer guten SD-Karte schrumpft damit auf fast nichts.
3. **Das Starten von USB ist wacklig.** Beim Pi 3 B muss es erst einmalig
   freigeschaltet werden, und nicht jeder USB-SATA-Adapter wird beim Start
   erkannt.

Weil ein Pi 3 ohnehin nur als **Client** laufen kann (die Langzeitdaten liegen
beim Master), schreibt er deutlich weniger — mit einer ordentlichen Karte und
kürzerer Aufbewahrung ist der Verschleiß gut beherrschbar.

## Stromversorgung beim Pi 5: prüfen, nicht annehmen

Der Pi 5 verhandelt beim Start mit seiner Stromversorgung und begrenzt
daraufhin den Strom **aller** USB-Geräte zusammen. Meldet die Versorgung nur
3 A, bleiben für USB **600 mA** — zu wenig, um eine 2,5-Zoll-SATA-SSD
überhaupt anlaufen zu lassen. Üblicherweise hebt man die Grenze dann mit
`usb_max_current_enable=1` auf.

Das klingt nach einer offenen Flanke, und wir haben sie zunächst auch für die
Ursache unserer Ausfälle gehalten. **Die Messung hat das widerlegt**
(01.08.2026, Analyzer 01 an PoE, 3000 mA gemeldet, Grenze aufgehoben):

| Messgröße | Wert |
| --- | --- |
| 5 V im Leerlauf | 5,147 V |
| 5 V Minimum unter 30 s Volllast | 5,099 V |
| Einbruch | **58 mV** |
| Drosselung | `throttled=0x0` |

Eine Speisung, die unter voller Leselast um 0,06 V nachgibt, hat reichlich
Reserve. Der gemeldete 3-A-Wert ist ein formaler Deckel, keine reale Grenze —
jedenfalls in diesem Aufbau. **Der Ausfall kam nicht von der Stromversorgung**
(die tatsächliche Ursache steht im Handbuch, Abschnitt 23.2).

Die Lehre ist trotzdem eine Position im Einkaufsführer, nur eine andere als
gedacht: Diese Größen sind **messbar**, und geraten wird hier nicht. Vor jeder
Kaufentscheidung liefert
[`tools/strombudget-messen.sh`](../tools/strombudget-messen.sh) die Zahlen.
Bleibt das Minimum über 4,95 V, ist die Versorgung als Ursache erledigt; unter
4,75 V liegt sie außerhalb der USB-Spezifikation und ist es sicher nicht.

Besonders tückisch an dieser Klasse von Fehlern: Der Rechenkern hat seine
eigene Regelung und bekommt von Einbrüchen am USB-Anschluss nichts mit.
`vcgencmd get_throttled` meldet unbeirrt `0x0`, und im Journal steht nichts,
weil es auf der ausgefallenen Platte liegt. Zu fassen ist so etwas nur über
einen Kernel-Mitschnitt übers Netz (Handbuch 23.1).

Den Zustand zeigen zwei Zeilen:

```bash
python3 -c "print(int.from_bytes(open('/proc/device-tree/chosen/power/max_current','rb').read(),'big'),'mA')"
vcgencmd get_config usb_max_current_enable
```

`5000 mA` heißt: alles offen. `3000 mA` heißt: Der Deckel greift, und wer ihn
aufhebt, sollte einmal nachmessen — nicht mehr und nicht weniger. Bei uns
ergab die Messung reichlich Reserve.

**Der Pi 4 kennt diese Verhandlung gar nicht** und gibt seinen USB-Anschlüssen
ohne Rückfrage Strom. Wer von einem laufenden Pi-4-Aufbau auf einen Pi 5
schließt, überträgt diese Annahme stillschweigend mit — deshalb steht der
Hinweis hier, auch wenn sich in unserem Fall die Versorgung als unschuldig
erwiesen hat.

### Wenn nur PoE zur Verfügung steht

Dann ist das Budget von außen vorgegeben, und zwar durch die Norm:

| Speisung | Leistung am Gerät | Reicht für Pi 5 + USB-SSD? |
| --- | --- | --- |
| 802.3af (PoE) | 12,95 W | knapp — für den Pi 5 allein schon wenig |
| 802.3at (PoE+) | 25,5 W | ja, **wenn** das HAT die 5 A auch meldet |
| 802.3bt (PoE++) | 51 W | reichlich |

Zwei Dinge müssen dabei zusammenkommen: Der **Switch oder Injektor** muss
PoE+ liefern, und das **HAT** muss die 5 A gegenüber der Pi-Firmware
ausweisen. Ein HAT, das nur 3 A meldet, führt trotz ausreichender Einspeisung
wieder zu den 600 mA für USB. Nachprüfen mit den beiden Zeilen oben — dort
muss `5000 mA` stehen.

**Der robustere Weg bei PoE ist, die Platte gar nicht erst an USB zu hängen.**
Eine **NVMe-Platine** am PCIe-Anschluss des Pi 5 umgeht die USB-Begrenzung
vollständig — sie gilt nur für USB-Geräte, nicht für PCIe. Eine M.2-SSD
verbraucht dabei auch weniger als eine 2,5-Zoll-SATA-Platte samt
USB-Brücke, und die gesamte Steckerkette aus Adapter, Keystone und Kabel
entfällt mit. Für Geräte, die jahrelang unbeaufsichtigt im Schrank laufen
sollen, ist das die Bauform ohne Folgefragen.

Vor einer Kaufentscheidung gehört gemessen, wie viel Luft tatsächlich bleibt:
[`tools/strombudget-messen.sh`](../tools/strombudget-messen.sh) belastet die
Platte und protokolliert dabei die 5-Volt-Schiene.

## Wichtig bei den Bildern

Das Repo ist **öffentlich**: Produktfotos aus Shops sind urheberrechtlich
geschützt und dürfen nicht übernommen werden. Deshalb **eigene Fotos** der
tatsächlich gekauften Teile (liefert der User, sobald die Hardware da ist)
— das ist ohnehin glaubwürdiger („so sieht das Richtige aus").

Bis dahin wird überall der **Platzhalter** verwendet:

Produktbild folgt

- Vektor (skaliert, bevorzugt): [`img/produktbild-platzhalter.svg`](img/produktbild-platzhalter.svg)
- Raster (800 × 600, falls SVG nicht geht): [`img/produktbild-platzhalter.png`](img/produktbild-platzhalter.png)

## Umsetzung

1. Kapitel **„Zubehör bestellen"** im Root-README (kompakte Tabelle mit Links)
2. Eigenes **Handbuch-Kapitel** (ausführlich, bebildert, mit
   Anforderungsbeschreibungen und Einbauhinweisen — Stil der bestehenden
   Kapitel), PDF neu bauen
3. Beispiellinks vom User verifizieren lassen (Verfügbarkeit/Varianten),
   analog zur Reichelt-Bestellliste

## Einordnung

Phase **M12** (reine Doku-Phase, jederzeit einschiebbar; Bilder abhängig von
der gelieferten Hardware). Akzeptanz: Kapitel in README und Handbuch-PDF,
alle sechs Positionen mit Anforderung + Beispiellink, Bilder der realen
Teile, keine fremden Produktfotos.

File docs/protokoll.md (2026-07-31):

# Protokoll und Absturzsuche (Phase M13)

Anlass (31.07.2026): Ein Analyzer wurde nach einigen Stunden unerreichbar und
musste hart neu gestartet werden. Ohne Aufzeichnung ist so etwas nicht zu
finden — das Journal von systemd hilft nur, solange der Dienst selbst noch
schreibt, und überlebt ein hartes Einfrieren nur teilweise.

## Was mitgeschrieben wird

Neben den Dienstmeldungen erhebt der Analyzer **jede Minute** die Größen, an
denen sich ein Absturz im Nachhinein festmachen lässt:

| Größe | Warum sie zählt |
| --- | --- |
| **Unterspannung und Drosselung** (`vcgencmd get_throttled`) | Mit PoE-HAT und SSD am USB die häufigste Ursache für Einfrieren und harte Neustarts. Das Bitfeld unterscheidet „tritt gerade auf" von „ist seit dem Start schon einmal aufgetreten" — beides wird ausgewertet. |
| **Temperatur** | Ab etwa 80 °C drosselt der Pi, ab 85 °C hart. |
| **Arbeitsspeicher**, inkl. verfügbarem Speicher und Auslagerung | Wird der Speicher knapp, greift der OOM-Killer und der Dienst verschwindet ohne eigene Fehlermeldung. |
| **Freier Plattenplatz** | Eine volle Systempartition legt Dienste still. |
| **Systemlast und Laufzeit** | Ein Sprung der Laufzeit auf Sekunden beweist einen Neustart. |

Geschrieben wird sparsam: **alle 15 Minuten** eine Zeile, solange nichts
auffällt. Wird etwas auffällig, landet es **sofort und als Fehler** in der
Datei — also selbst bei der sparsamsten Stufe.

Zusätzlich hält der Dienst fest, was ihn selbst beendet: unbehandelte
Ausnahmen und Zusagen, sowie die Signale SIGHUP, SIGQUIT und SIGABRT.

## Das Systemjournal wird mitgelesen

Das eigene Protokoll zeigt nur, was der Analyzer selbst bemerkt. Ob eine
Störung **aus dem System** kam, steht dagegen im Journal von systemd — in
Zeilen, die unser Prozess nie zu sehen bekommt. Deshalb übernimmt der Dienst
sie in sein Protokoll, mit dem Bereich `[systemlog]`:

| Kernelmeldung | Bedeutung im Protokoll |
| --- | --- |
| `Under-voltage detected!` | Unterspannung (Kernel) |
| `Out of memory: Killed process …` | Speichermangel — Prozess abgeräumt |
| `usb 2-1: reset SuperSpeed USB device` | USB-Gerät neu angemeldet (Boot-SSD!) |
| `EXT4-fs error`, `I/O error` | Dateisystem- oder Datenträgerfehler |
| `critical temperature reached` | Temperaturnotabschaltung |
| `watchdog`, `kernel panic`, `BUG:` | Kernel meldet schweren Fehler |

Treffer landen als **Fehler**, alles Übrige als `debug`. Gelesen wird über den
Journal-Cursor, deshalb ohne Doppelungen und über Dienst-Neustarts hinweg
lückenlos.

**Nach jedem Start** bewertet der Dienst zusätzlich den *vorherigen*
Systemlauf. Fand sich dort keine Abmeldung, steht im Protokoll:

```text
FEHLER  [systemlog]  Der vorherige Systemlauf wurde NICHT sauber beendet —
                     Hinweis auf Stromausfall, Spannungseinbruch oder
                     Kernel-Absturz, nicht auf einen Fehler dieser Anwendung
```

Das ist die Antwort auf die Frage „lag es an uns oder am System?".

### Zwei Voraussetzungen, die der Installer einrichtet

1. **Leserecht**: Der Dienstbenutzer muss in der Gruppe `systemd-journal`
   sein — sonst sieht er nur die eigenen Meldungen.
2. **Dauerhaftes Journal**: Raspberry Pi OS speichert das Journal ab Werk
   **flüchtig** (`/run/log/journal`). Nach einem harten Absturz wäre damit
   genau der interessante Teil verloren. Der Installer legt deshalb
   `/etc/systemd/journald.conf.d/asksin.conf` an mit `Storage=persistent`,
   gedeckelt auf 200 MB und einen Monat.

Auf Bestandsanlagen zieht `sudo asksin-analyzer update` beides nach.

## Einstellungen (Weboberfläche → **Wartung**)

| Einstellung | Bedeutung |
| --- | --- |
| **Fehler** | Nur Störungen. Kleinste Datei. |
| **Info** | Störungen und wichtige Ereignisse. Vorgabe. |
| **Debug** | Zusätzlich Abläufe im Inneren — für die Fehlersuche. |
| **Alles** | Auch Einzeltelegramme. Wächst schnell. |
| **Aufbewahrung** | 1–365 Tage; ältere Dateien werden beim Tageswechsel gelöscht. |

Beides wirkt sofort und wird dienst-schreibbar in
`/var/lib/asksin-analyzer/protokoll.json` abgelegt; `config.json` bleibt der
Experten-Weg (Abschnitt `"protokoll": { "stufe": …, "tage": … }`).

## Dateien

Eine Datei je Tag, `asksin-JJJJ-MM-TT.log`, in
`/var/lib/asksin-analyzer/protokoll/`. Umgeschaltet wird beim ersten Eintrag
nach Mitternacht — ohne eigenen Zeitgeber. Format mit festen Spalten, damit
`grep` und Auge gleichermaßen zurechtkommen:

```text
2026-07-31 08:12:33.123  FEHLER  [ingest]     Port weg (EIO)
2026-07-31 08:12:34.001  INFO    [system]     Temperatur 62,3 °C · Speicher frei 940 MB …
```

Heruntergeladen wird über **Wartung → Dateien**; der Endpunkt ist
`GET /api/protokoll/datei/<name>`. Der Name wird streng geprüft (nur
`asksin-JJJJ-MM-TT.log`) — sonst wäre der Download ein Pfad-Ausbruch.

## Wenn der Pi wieder aussteigt

1. **Wartung** öffnen, Stufe auf **Debug** stellen.
2. Nach dem nächsten Ausfall die Datei des Tages herunterladen.
3. Nach `FEHLER` und `[system]` suchen. Steht dort *Unterspannung*, ist die
   Stromversorgung die Ursache — dann hilft kein Software-Update, sondern ein
   kräftigeres Netzteil bzw. ein PoE-Injektor mit mehr Reserve.
4. Bricht das Protokoll **mitten im Betrieb** ab, ohne Fehlerzeile davor, war
   es kein Programmfehler: Dann hat das System selbst ausgesetzt (Kernel-Panik,
   Spannungseinbruch, Hardwaredefekt). Die letzten Systemzeilen davor zeigen,
   wie die Lage kurz vorher war.
5. Nach dem Neustart steht ganz oben in der neuen Datei, ob der vorherige
   Systemlauf sauber endete — die letzten Fehlermeldungen von damals stehen
   als `[systemlog-vorher]` gleich darunter.

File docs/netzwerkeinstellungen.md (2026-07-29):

# Netzwerkeinstellungen über die Web-UI (M7.6)

Anforderung (29.07.2026): Die Netzwerkeinstellungen des Raspberry Pi sollen
über die Weboberfläche anpassbar sein — **DHCP/Statisch**, die statischen
Werte (IP/Präfix, Gateway, DNS), **NTP** und der **Hostname**. Bestehende
Installationen bleiben unberührt, bis der Anwender aktiv ändert. Bei DHCP
werden die zugewiesenen Werte angezeigt.

## Grundsätze

1. **Anzeigen ≠ Ändern.** Die Seite öffnet als Live-Anzeige des Ist-Zustands
   (bei DHCP inklusive der zugewiesenen Adresse, Gateway, DNS, Lease).
   Nichts wird angewendet, bevor „Übernehmen" gedrückt und bestätigt wurde.
2. **Aussperr-Schutz mit Probezeit.** Wer die IP ändert, sägt am Ast, auf dem
   die Verbindung sitzt. Deshalb gelten neue Netzwerkeinstellungen zunächst
   **auf Probe (90 s)**: Die UI leitet auf die neue Adresse um; kommt dort
   innerhalb der Frist keine Bestätigung an, stellt der Pi den vorherigen
   Zustand automatisch wieder her — dasselbe Muster wie der Update-Rollback.
3. **Hostname nur hier, nur ausdrücklich.** Der Standortname (M9.1) bleibt
   ein reines Anzeige-Etikett; die Hostname-Änderung ist eine bewusste
   Administrations-Aktion auf dieser Seite (`hostnamectl`). Nichts ändert
   den Hostnamen implizit.
4. **Auth-Pflicht** wie bei `/api/update/*`; standardmäßig zusätzlich nur mit
   gesetztem Token nutzbar.
5. **Privilegien wie beim Update.** Der unprivilegierte Dienst schreibt eine
   Auftragsdatei (JSON) ins Datenverzeichnis; eine systemd-Path-Unit startet
   `netz-anwenden.sh` als root. `NoNewPrivileges` bleibt intakt.

## Technik (Raspberry Pi OS Bookworm/Trixie)

- **NetworkManager** (`nmcli`) für DHCP/Statisch/Gateway/DNS:
  `nmcli con mod <verbindung> ipv4.method auto|manual ipv4.addresses …
  ipv4.gateway … ipv4.dns …` + `nmcli con up`
- **Lesen** ohne Root: `ip -j addr` / `ip -j route`, `nmcli -t device show`,
  `resolvectl status`, `timedatectl show`, `hostnamectl status`
- **NTP**: `timedatectl set-ntp` bzw. `NTP=` in
  `/etc/systemd/timesyncd.conf` + Neustart von systemd-timesyncd;
  Anzeige inkl. Sync-Zustand (wichtig für die Verbund-Zeitbasis, M9.2)
- **Hostname**: `hostnamectl set-hostname` (+ `/etc/hosts`-Eintrag pflegen)
- **Fallback**: Systeme ohne NetworkManager (dhcpcd) → Anzeige funktioniert,
  Ändern ist mit klarem Hinweis deaktiviert statt halb zu funktionieren

## API

| Endpunkt | Zweck |
| --- | --- |
| `GET /api/netzwerk` | Ist-Zustand: Methode (dhcp/statisch), Adresse(n), Gateway, DNS, Hostname, NTP-Server + Sync-Status, DHCP-Lease-Infos |
| `POST /api/netzwerk` *(Auth)* | Auftrag `{method, address, prefix, gateway, dns[], hostname?, ntp?}` → 202, Probezeit läuft |
| `POST /api/netzwerk/bestaetigen` *(Auth)* | macht die Probe-Einstellungen dauerhaft |
| `GET /api/netzwerk/status` | Fortschritt/Ergebnis über die Statusdatei — übersteht Verbindungswechsel |

## UI

*Einstellungen → Netzwerk*: Live-Anzeige mit „per DHCP zugewiesen"-Kennzeichnung,
Umschalter DHCP/Statisch, Eingabefelder (nur bei Statisch aktiv), Hostname- und
NTP-Feld, deutliche Warnbox vor der Übernahme und Countdown der Probezeit mit
automatischer Weiterleitung auf die neue Adresse.

## Einordnung

Meilenstein **M7.6**, umgesetzt **zusammen mit M9.2** (Verbund-Dashboard) —
entschieden am 29.07.2026: Beide Bausteine teilen sich die Mechanik
(Auftragsdatei + Path-Unit, Statusdatei, auth-pflichtige API) und die
Einstellungen-Seite wird nur einmal umgebaut. Akzeptanz: (a) DHCP-Werte werden korrekt angezeigt,
(b) Wechsel DHCP→Statisch→DHCP übersteht die Probezeit-Mechanik inklusive
absichtlich provoziertem Rollback, (c) ohne Bestätigung ist nach 90 s der
alte Zustand wiederhergestellt, (d) bestehende Installationen verhalten sich
ohne Nutzung der Seite exakt wie bisher.

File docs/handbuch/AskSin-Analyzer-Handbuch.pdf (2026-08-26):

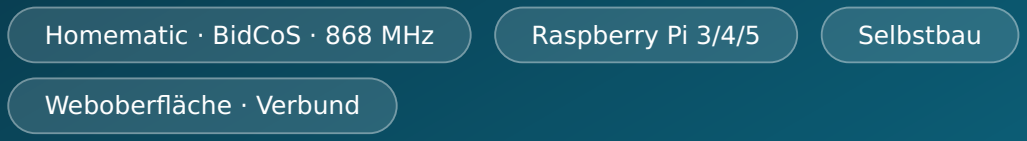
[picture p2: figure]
Weboberfläche · Verbund

Homematic · BidCoS · 868 MHz | Raspberry Pi 3/4/5 | Selbstbau

# AskSin-Analyzer

## Das Handbuch — vom leeren Platinen-Layout bis zum Verbund aus fünf Funkanalyzern


Ausgabe 2 · Juli 2026 · deutsch | Hardware 0.2.0 · Software 1.8.0 · CC BY-NC-SA 4.0

# Über dieses Handbuch

Dieses Handbuch richtet sich an Einsteigerinnen und Einsteiger. Du brauchst keine Elektronik-Ausbildung — aber einen Lötkolben, etwas Geduld und die Bereitschaft, Befehle in ein Terminal zu tippen. Jeder Schritt ist vollständig beschrieben: Was du tust, warum du es tust, und woran du erkennst, dass es geklappt hat.

So liest du dieses Handbuch

ℹ Hinweis
Blaue Kästen liefern Hintergrundwissen. Man kann sie überspringen — sie machen aber vieles verständlicher.

✓ Tipp
Grüne Kästen sparen Zeit oder Nerven.

⚠ Achtung
Gelbe Kästen markieren Stellen, an denen häufig etwas schiefgeht.

Stopp
Rote Kästen markieren Handgriffe, die Hardware zerstören können. Bitte immer lesen.
Befehle für das Terminal sehen so aus — sie werden Zeile für Zeile eingegeben und mit | Enter
abgeschickt. Zeilen, die mit | # | beginnen, sind Kommentare und werden nicht eingetippt:

# Das ist ein Kommentar — nur zur Erklärung

sudo apt update
© 2026 S. Sternitzke · CC BY-NC-SA 4.0 | ↑ Inhaltsverzeichnis | Handbuch Ausgabe 2 · Software 1.8.0

# Inhalt

### 1 Was ist der AskSin-Analyzer?

### 2 Wie das System funktioniert

### 3 Einkaufsliste: Material und Werkzeug

### 4 Die Platine verstehen

### 5 Die Platine fertigen lassen

### 6 Handbestückung: die restlichen Bauteile auflöten

### 7 Fuses setzen und Bootloader brennen

### 8 Die Firmware aufspielen

### 9 Den Raspberry Pi einrichten — Installation mit einem Befehl

### 10 Zusammenbau und Montage im Schrank

### 11 Firmware-Updates im laufenden Betrieb

### 12 Die Software: Überblick und Architektur

### 13 Die Weboberfläche im Detail

### 14 Der Demo-Modus — testen ohne Hardware

### 15 Software-Updates: Glocke, Ein-Klick-Update, Rollback

### 16 Netzwerkeinstellungen mit Aussperr-Schutz

### 17 Der Verbund: mehrere Analyzer als Gesamtsystem

### 18 Status-LED und OLED-Anzeige

### 19 Langzeitdaten: InfluxDB und Grafana

### 20 Der ioBroker-Adapter

### 21 Sicherheit: Token, Netzwerk, Grenzen

### 22 Protokoll: wenn etwas nicht stimmt

### 23 Fehlersuche

### 24 Anhang: Belegungen, Glossar, Quellen
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

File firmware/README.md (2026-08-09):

# Firmware für den Sniffer-Mikrocontroller

Hier liegen die **Prüfwerkzeuge** für die HEX-Dateien des ATmega328P — nicht
mehr die Dateien selbst. Warum, steht gleich unten.

Der Quelltext der Firmware liegt in einem eigenen Projekt:
**[ssbingo/asksin-sniffer-firmware](https://github.com/ssbingo/asksin-sniffer-firmware)**.
Dort wird sie gebaut, dort liegen die Host-Tests, dort steht die Anleitung zum
Aufspielen. Das Handbuch führt in Kapitel 7 Schritt für Schritt durch den Weg
über Windows und die Arduino IDE.
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

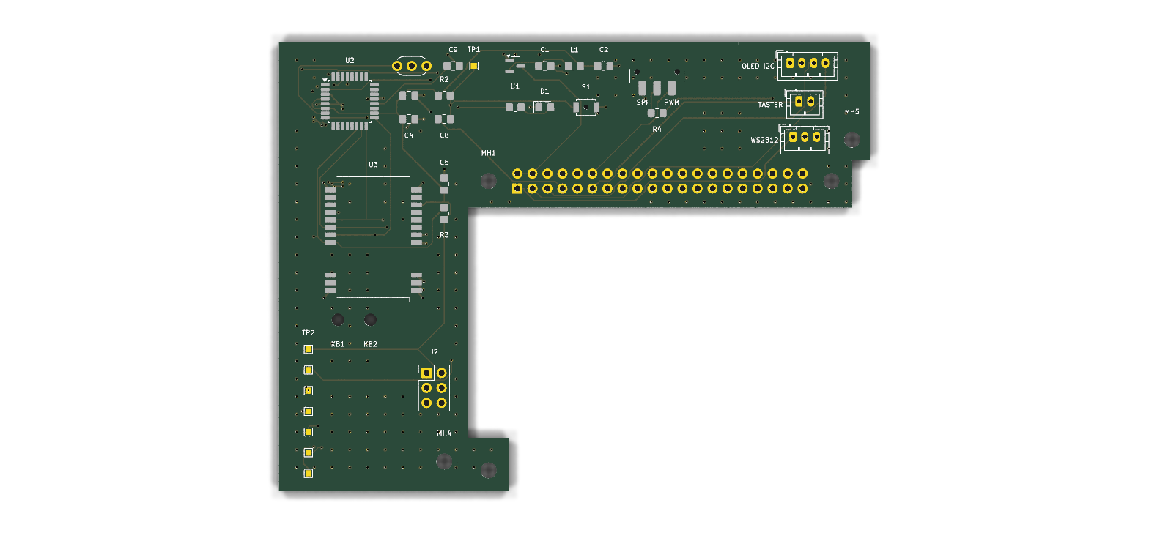
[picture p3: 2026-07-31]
docs/handbuch/img/platine-oben.png

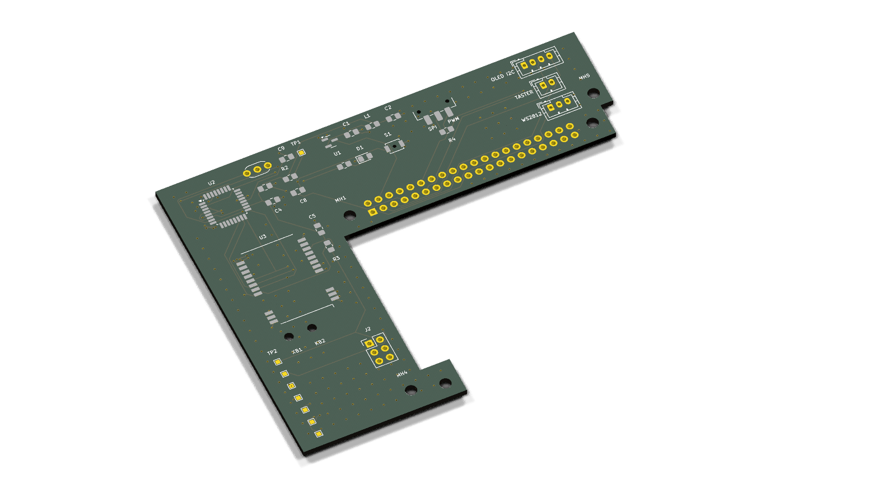
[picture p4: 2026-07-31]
docs/handbuch/img/platine-schraeg.png

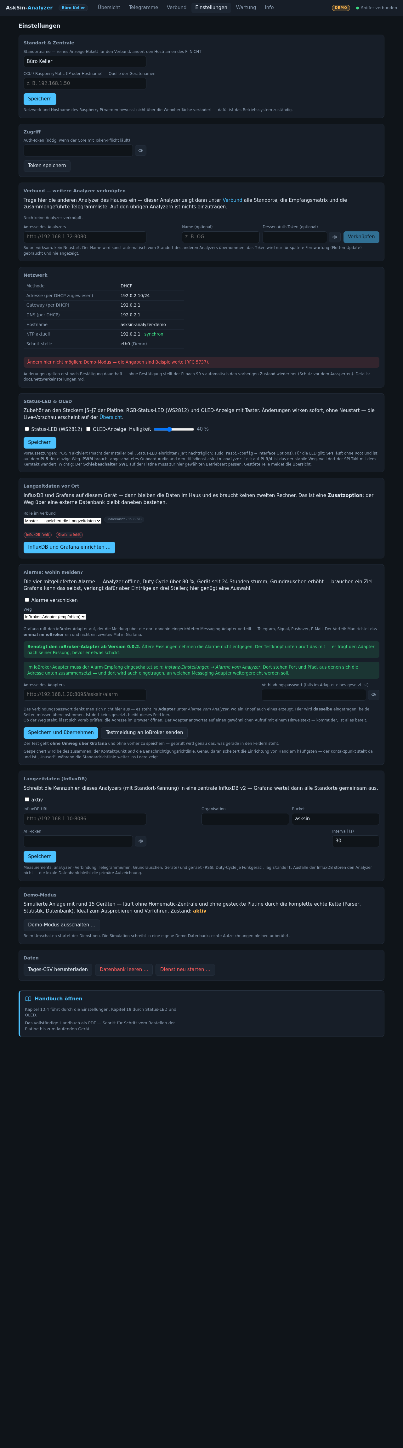
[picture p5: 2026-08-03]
docs/handbuch/img/ui-einstellungen.png

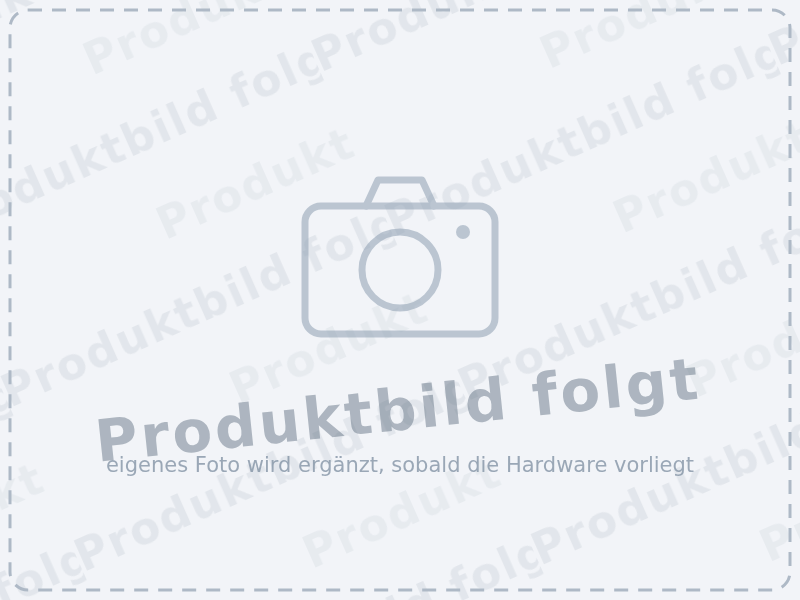
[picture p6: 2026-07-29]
docs/img/produktbild-platzhalter.png

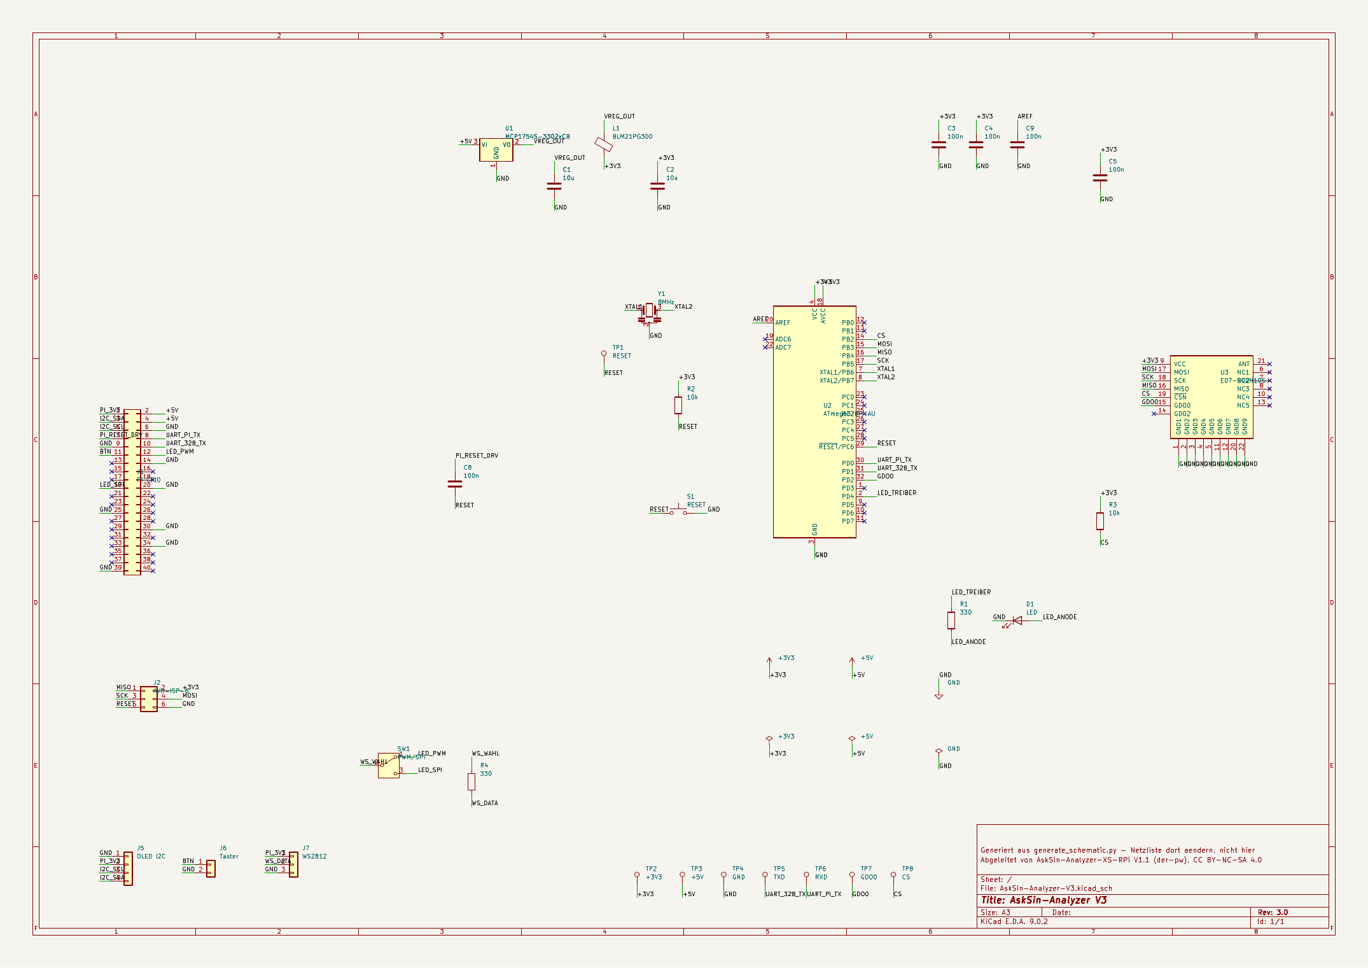
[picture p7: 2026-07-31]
docs/handbuch/img/schaltplan-1.png

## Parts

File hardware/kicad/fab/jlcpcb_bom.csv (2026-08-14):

Comment | Designator | Footprint | JLCPCB Part #
CL21A106KAYNNNE 10uF 25V X5R | C1,C2 | C_0805_2012Metric_Pad1.18x1.45mm_HandSolder | C15850
CC0805KRX7R9BB104 100nF 50V X7R | C3,C4,C5,C8,C9 | C_0805_2012Metric_Pad1.18x1.45mm_HandSolder | C49678
FC-2012HRK-620D rot | D1 | LED_0805_2012Metric_Pad1.15x1.40mm_HandSolder | C84256
BLM21PG300SN1D | L1 | L_0805_2012Metric_Pad1.15x1.40mm_HandSolder | C16903
330R 1% 0805 | R1,R4 | R_0805_2012Metric_Pad1.20x1.40mm_HandSolder | C17630
10K 1% 0805 | R2,R3 | R_0805_2012Metric_Pad1.20x1.40mm_HandSolder | C17414
B3U-1000P | S1 | SW_SPST_B3U-1000P-B | C231329
JS102011SAQN SPDT-Schiebeschalter | SW1 | SW_SPDT_CK_JS102011SAQN | C221660
XC6206P332MR-G | U1 | SOT-23 | C5446
ATMEGA328P-AU | U2 | TQFP-32_7x7mm_P0.8mm | C14877
E07-900M10S | U3 | E07-900M10S | C9900007000
CSTLS8M00G53-B0 8MHz | Y1 | Resonator_Murata_CSTLSxxxX-3Pin_W5.5mm_H3.0mm | C83707

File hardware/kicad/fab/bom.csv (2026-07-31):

Comment | Designator | Footprint | Quantity | Mounting | Source
10u | C1,C2 | C_0805_2012Metric_Pad1.18x1.45mm_HandSolder | 2 | SMD | Reichelt CL21A106KOQNNNG
100n | C3,C4,C5,C8,C9 | C_0805_2012Metric_Pad1.18x1.45mm_HandSolder | 5 | SMD | Reichelt KEM X7R0805 100N
LED | D1 | LED_0805_2012Metric_Pad1.15x1.40mm_HandSolder | 1 | SMD | Reichelt EVL 17-21USRC
Pi GPIO | J1 | PinSocket_2x20_P2.54mm_Vertical | 1 | THT | Reichelt MPE 094-2-040
AVR-ISP-6 | J2 | PinHeader_2x03_P2.54mm_Vertical | 1 | THT | Reichelt ECON SL6G2
OLED I2C | J5 | JST_PH_B4B-PH-K_1x04_P2.00mm_Vertical | 1 | THT | Reichelt JST PH4P ST
Taster | J6 | JST_PH_B2B-PH-K_1x02_P2.00mm_Vertical | 1 | THT | Reichelt JST PH2P ST
WS2812 | J7 | JST_PH_B3B-PH-K_1x03_P2.00mm_Vertical | 1 | THT | Reichelt JST PH3P ST
BLM21PG300 | L1 | L_0805_2012Metric_Pad1.15x1.40mm_HandSolder | 1 | SMD | Reichelt BLM21PG300SN1D
330 | R1,R4 | R_0805_2012Metric_Pad1.20x1.40mm_HandSolder | 2 | SMD | Reichelt WAL WR08X3300FTL
10k | R2,R3 | R_0805_2012Metric_Pad1.20x1.40mm_HandSolder | 2 | SMD | Reichelt WAL WR08X1002FTL
RESET | S1 | SW_SPST_B3U-1000P-B | 1 | SMD | JLCPCB C231329 (B3U-1000P)
PWM/SPI | SW1 | SW_SPDT_CK_JS102011SAQN | 1 | SMD | JLCPCB C221660 (C&K JS102011SAQN)
MCP1754S-3302xCB | U1 | SOT-23 | 1 | SMD | Reichelt MCP 1754-3302CB
ATmega328P-AU | U2 | TQFP-32_7x7mm_P0.8mm | 1 | SMD | Reichelt ATMEGA 328P-AU
E07-900M10S | U3 | E07-900M10S | 1 | SMD | Ebyte E07-900M10S — nicht bei Reichelt
8MHz | Y1 | Resonator_Murata_CSTLSxxxX-3Pin_W5.5mm_H3.0mm | 1 | THT | JLCPCB C83707 (CSTLS8M00G53-B0)

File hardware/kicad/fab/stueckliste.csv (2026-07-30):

Reference | Value | Footprint | QUANTITY
C1,C2 | 10u | Capacitor_SMD:C_0805_2012Metric_Pad1.18x1.45mm_HandSolder | 2
C3-C5,C8,C9 | 100n | Capacitor_SMD:C_0805_2012Metric_Pad1.18x1.45mm_HandSolder | 5
D1 | LED | LED_SMD:LED_0805_2012Metric_Pad1.15x1.40mm_HandSolder | 1
J1 | Pi GPIO | Connector_PinSocket_2.54mm:PinSocket_2x20_P2.54mm_Vertical | 1
J2 | AVR-ISP-6 | Connector_PinHeader_2.54mm:PinHeader_2x03_P2.54mm_Vertical | 1
J5 | OLED I2C | Connector_JST:JST_PH_B4B-PH-K_1x04_P2.00mm_Vertical | 1
J6 | Taster | Connector_JST:JST_PH_B2B-PH-K_1x02_P2.00mm_Vertical | 1
J7 | WS2812 | Connector_JST:JST_PH_B3B-PH-K_1x03_P2.00mm_Vertical | 1
L1 | BLM21PG300 | Inductor_SMD:L_0805_2012Metric_Pad1.15x1.40mm_HandSolder | 1
R1,R4 | 330 | Resistor_SMD:R_0805_2012Metric_Pad1.20x1.40mm_HandSolder | 2
R2,R3 | 10k | Resistor_SMD:R_0805_2012Metric_Pad1.20x1.40mm_HandSolder | 2
S1 | RESET | Button_Switch_SMD:SW_SPST_B3U-1000P-B | 1
SW1 | PWM/SPI | Button_Switch_SMD:SW_SPDT_CK_JS102011SAQN | 1
TP1 | RESET | TestPoint:TestPoint_Pad_1.0x1.0mm | 1
TP2 | +3V3 | TestPoint:TestPoint_Pad_1.0x1.0mm | 1
TP3 | +5V | TestPoint:TestPoint_Pad_1.0x1.0mm | 1
TP4 | GND | TestPoint:TestPoint_Pad_1.0x1.0mm | 1
TP5 | TXD | TestPoint:TestPoint_Pad_1.0x1.0mm | 1
TP6 | RXD | TestPoint:TestPoint_Pad_1.0x1.0mm | 1
TP7 | GDO0 | TestPoint:TestPoint_Pad_1.0x1.0mm | 1
TP8 | CS | TestPoint:TestPoint_Pad_1.0x1.0mm | 1
U1 | MCP1754S-3302xCB | Package_TO_SOT_SMD:SOT-23 | 1
U2 | ATmega328P-AU | Package_QFP:TQFP-32_7x7mm_P0.8mm | 1
U3 | E07-900M10S | AskSin-Analyzer-HAT:E07-900M10S | 1
Y1 | 8MHz | Crystal:Resonator_Murata_CSTLSxxxX-3Pin_W5.5mm_H3.0mm | 1

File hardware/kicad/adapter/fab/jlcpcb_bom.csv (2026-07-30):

Comment | Designator | Footprint | JLCPCB Part #
Buchsenleiste 2x20 RM 2,54 gerade, Hoehe 8,5 mm (ZHOURI 2.54-2*20) | J1 | PinSocket_2x20_P2.54mm_Vertical | C2977589
Stiftleiste 2x20 RM 2,54 gerade, Steckstift 6 mm (BOOMELE 2.54mm 2*20P) | J2 | PinHeader_2x20_P2.54mm_Vertical | C50980

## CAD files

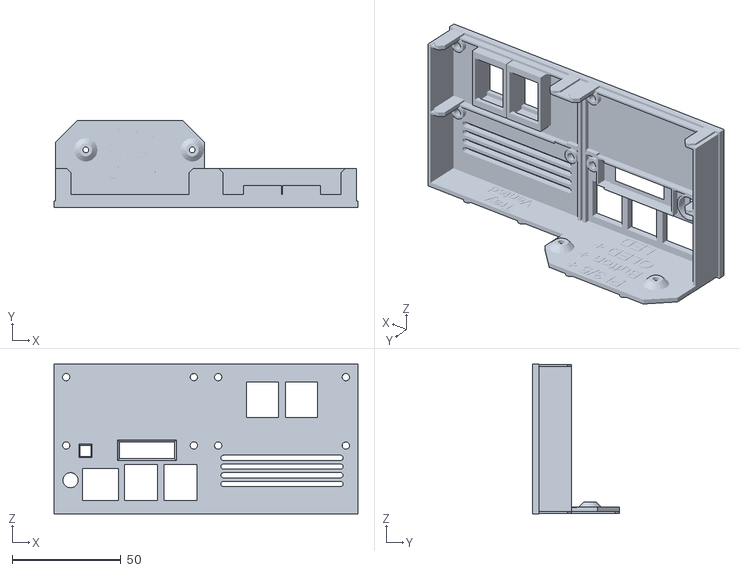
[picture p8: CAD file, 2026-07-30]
hardware/3d-druck/19-zoll-rahmen/Asksin-Analyzer Rahmen 19Zoll-OLED-LED-SWITCH_RPI5.stl
140.0 x 40.0 x 69.0

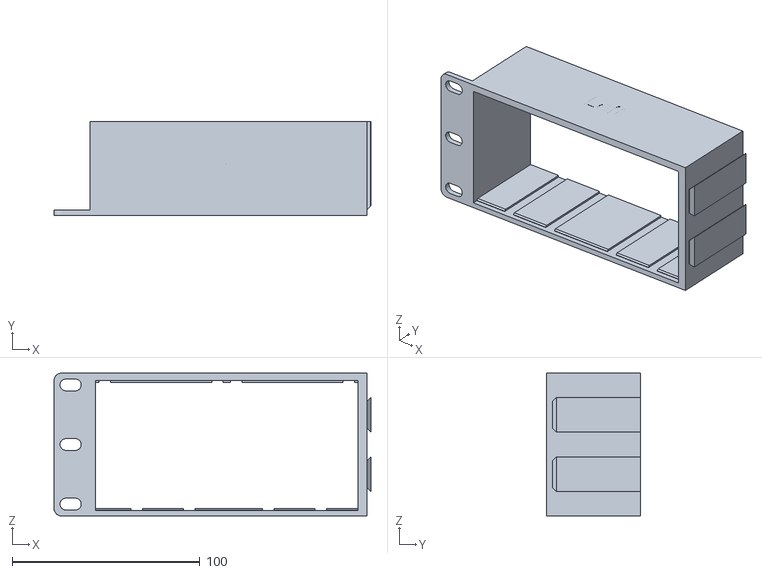
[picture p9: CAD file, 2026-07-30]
hardware/3d-druck/19-zoll-rahmen/Asksin-Analyzer Rahmen 19Zoll-Links.stl
168.9 x 50.0 x 76.2

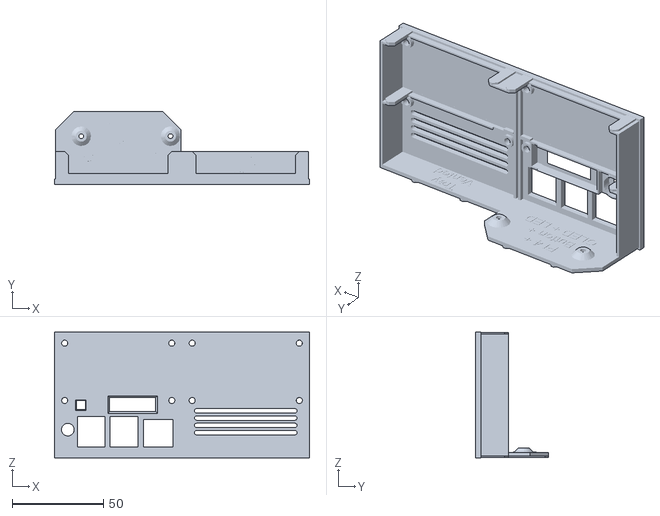
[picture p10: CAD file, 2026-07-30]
hardware/3d-druck/19-zoll-rahmen/Asksin-Analyzer Rahmen 19Zoll-OLED-LED-SWITCH_RPI4.stl
140.0 x 40.0 x 69.0

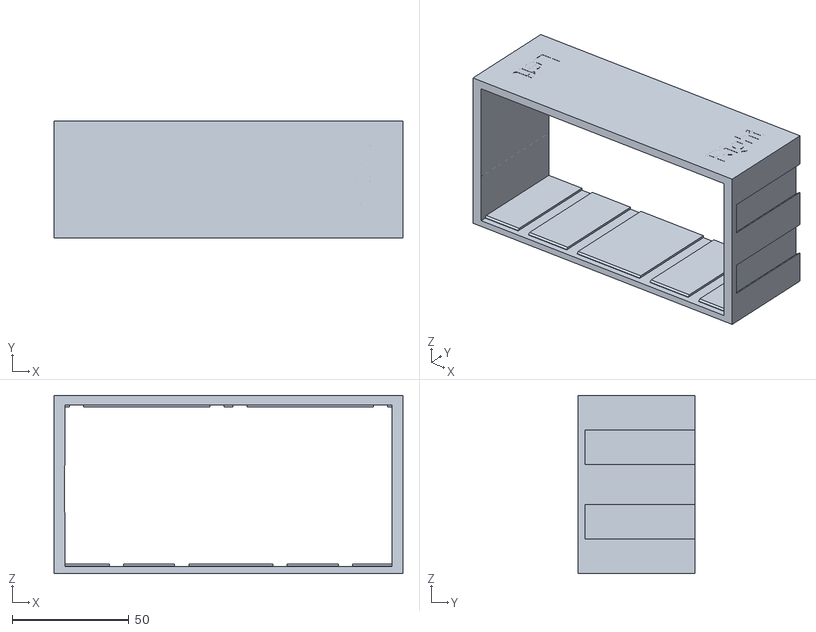
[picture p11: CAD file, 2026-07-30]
hardware/3d-druck/19-zoll-rahmen/Asksin-Analyzer Rahmen 19Zoll-Mitte.stl
149.3 x 50.0 x 76.2

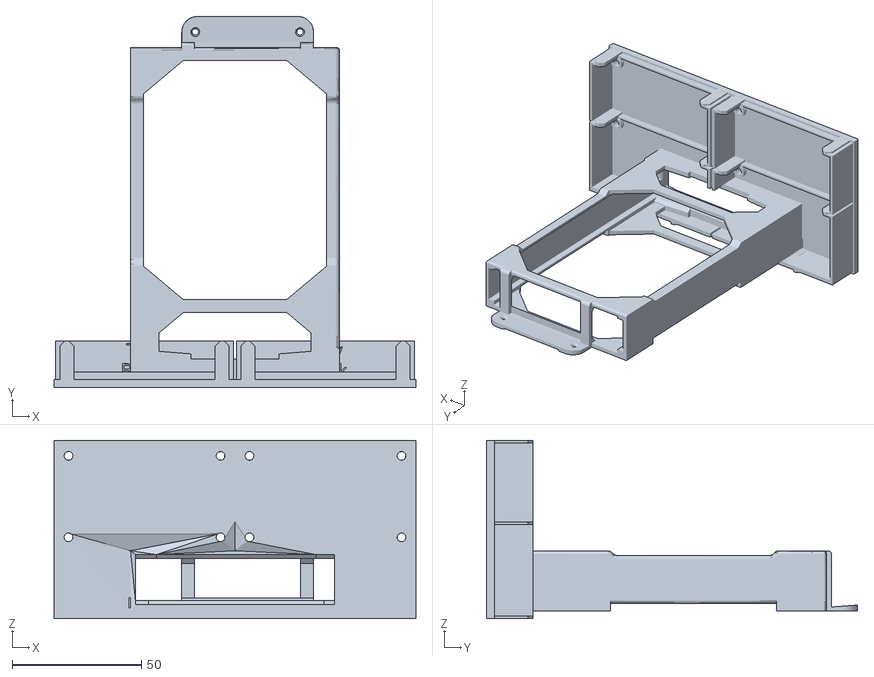
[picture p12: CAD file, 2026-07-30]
hardware/3d-druck/19-zoll-rahmen/Asksin-Analyzer Rahmen 19Zoll-SSD.stl
140.0 x 143.5 x 68.9

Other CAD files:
hardware/3d-druck/19-zoll-rahmen/Asksin-Analyzer Rahmen 19Zoll-Rechts.stl

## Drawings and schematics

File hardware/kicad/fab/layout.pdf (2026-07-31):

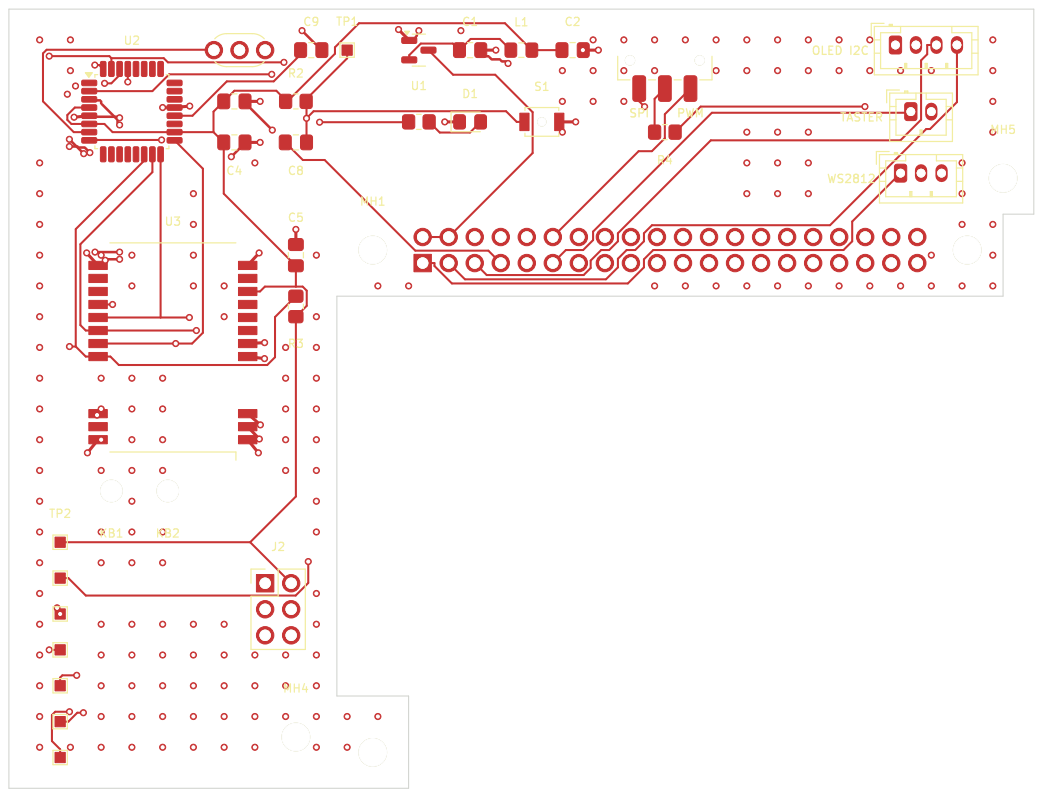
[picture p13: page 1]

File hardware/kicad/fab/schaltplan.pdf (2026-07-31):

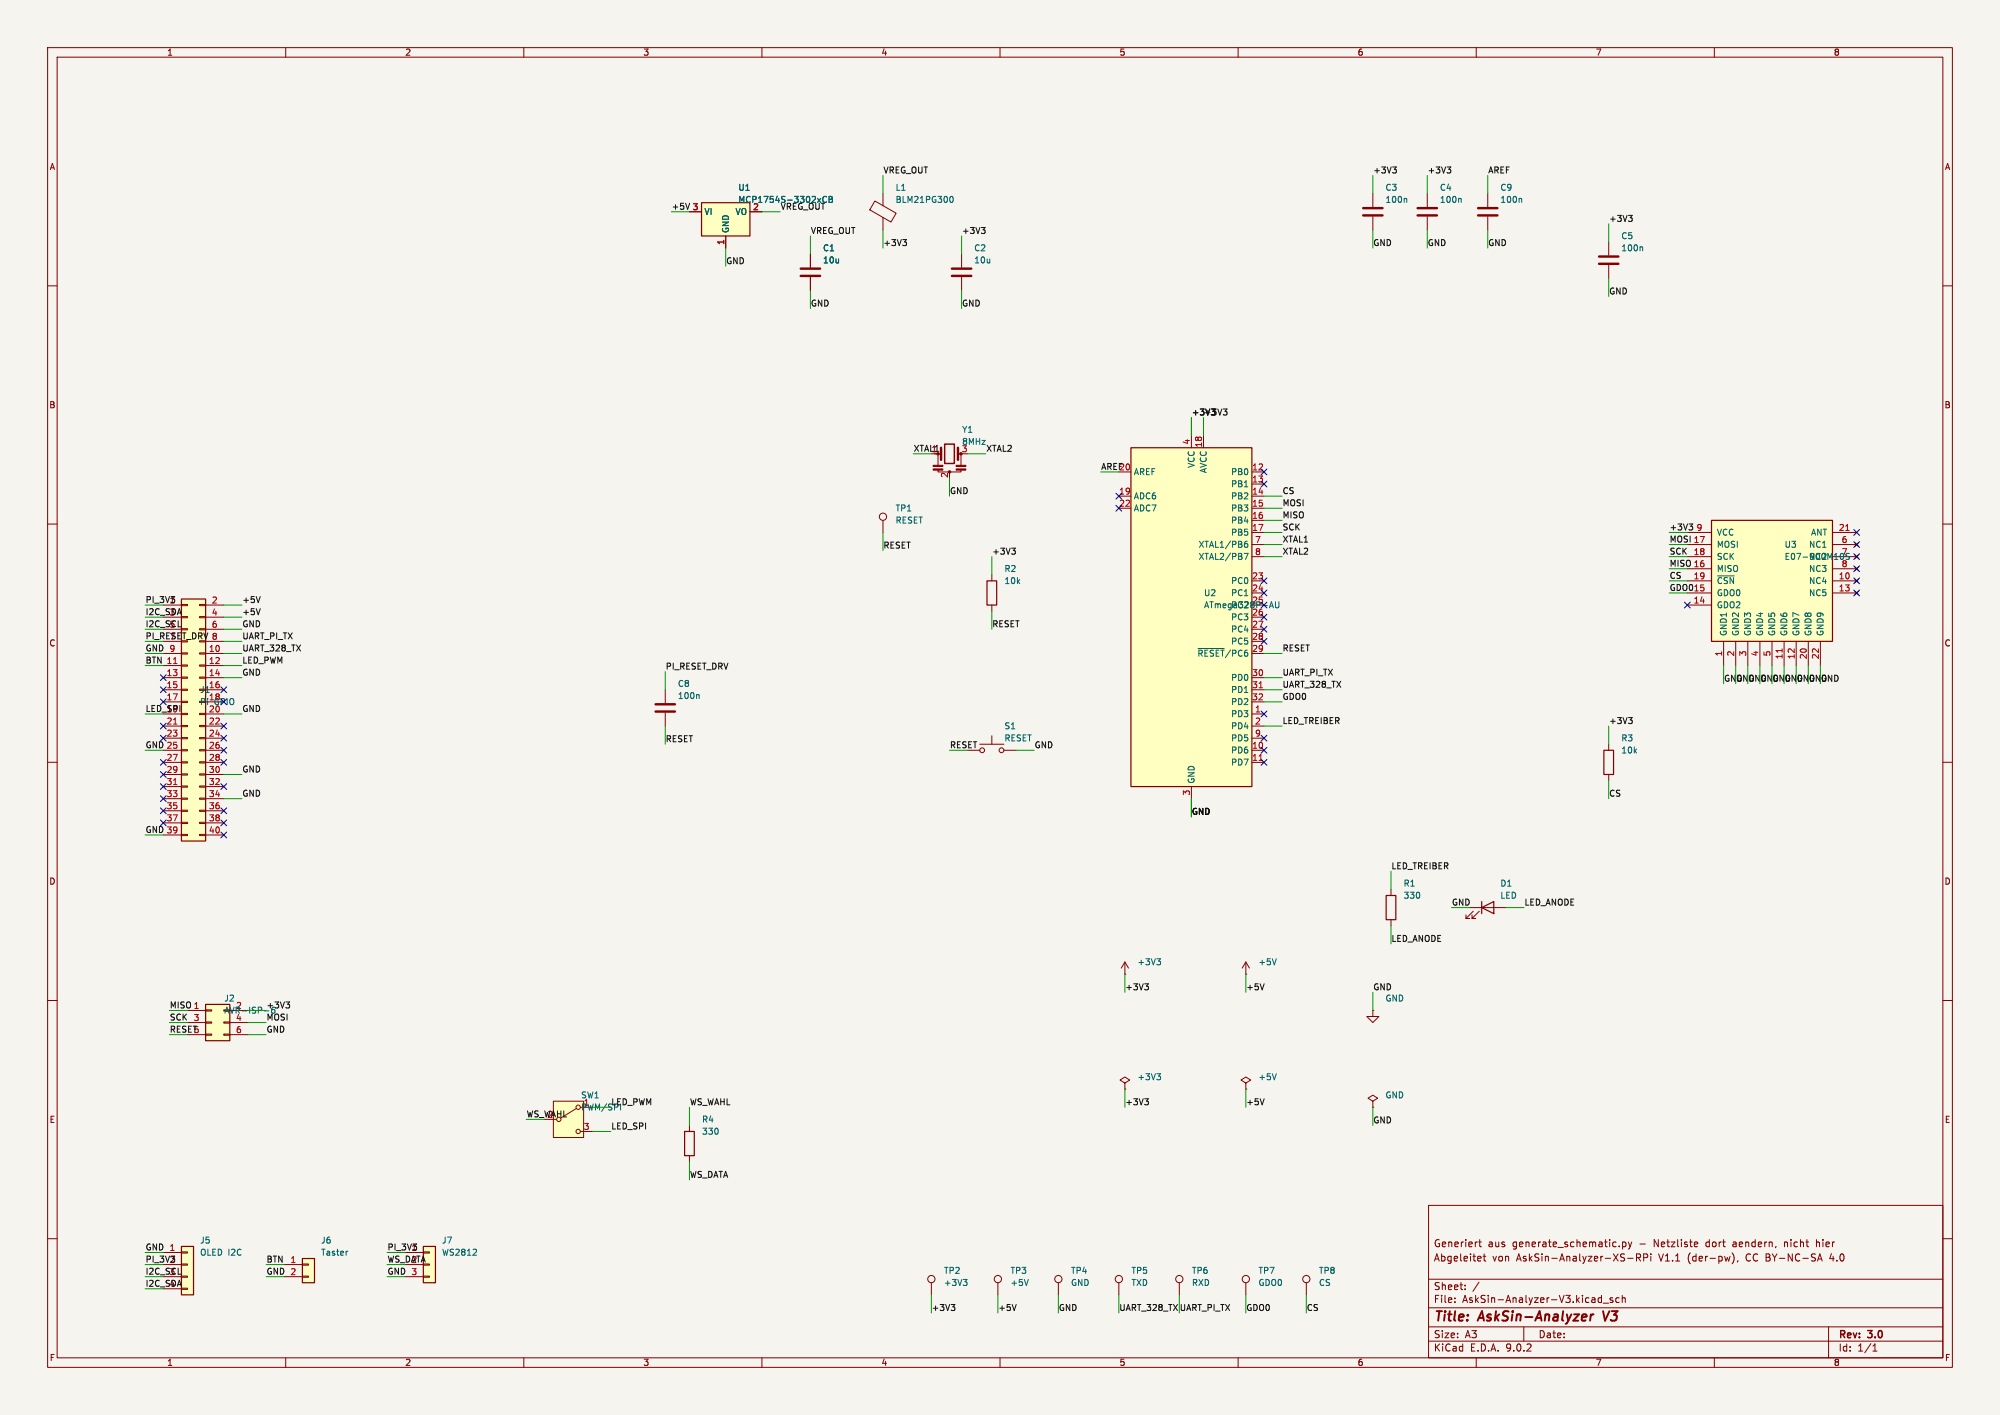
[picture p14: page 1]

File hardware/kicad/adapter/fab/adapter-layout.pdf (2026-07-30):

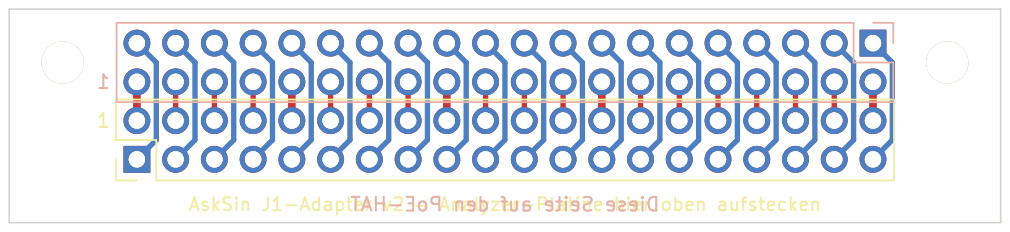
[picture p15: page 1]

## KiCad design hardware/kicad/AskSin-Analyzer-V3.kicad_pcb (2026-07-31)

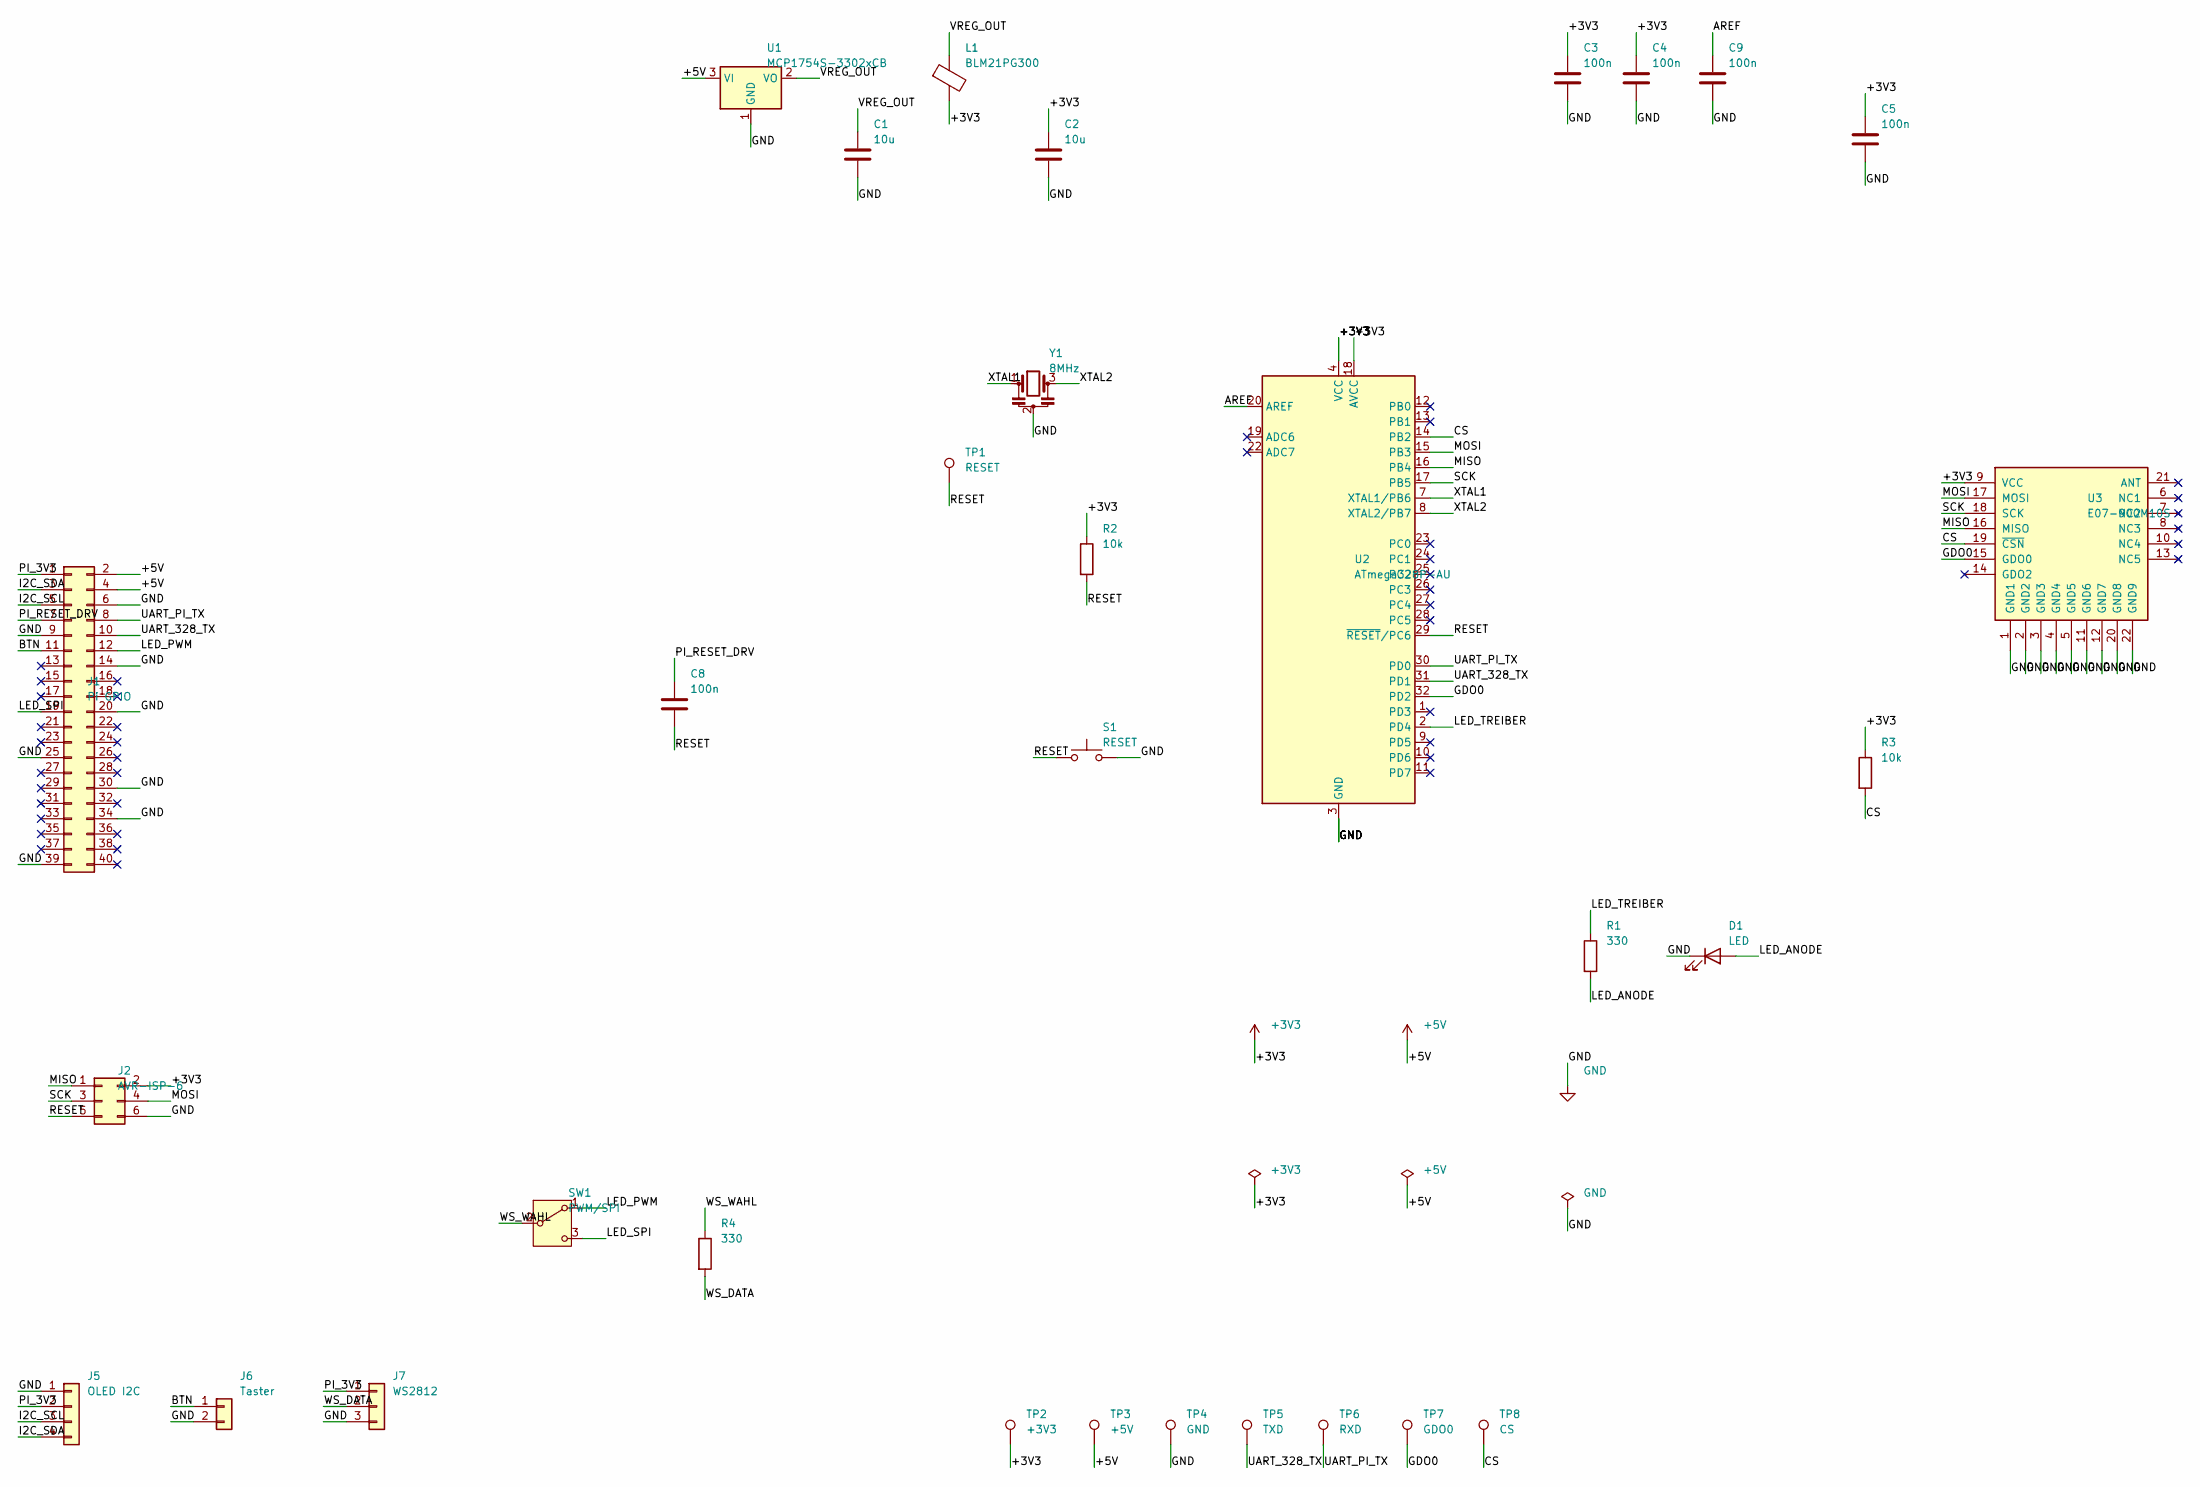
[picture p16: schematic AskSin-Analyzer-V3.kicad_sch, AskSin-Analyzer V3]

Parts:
C1, C2: 10u; C_0805_2012Metric_Pad1.18x1.45mm_HandSolder
C3, C4, C5, C8, C9: 100n; C_0805_2012Metric_Pad1.18x1.45mm_HandSolder
D1: LED; LED_0805_2012Metric_Pad1.15x1.40mm_HandSolder
J1: Pi GPIO; PinSocket_2x20_P2.54mm_Vertical
J2: AVR-ISP-6; PinHeader_2x03_P2.54mm_Vertical
J5: OLED I2C; JST_PH_B4B-PH-K_1x04_P2.00mm_Vertical
J6: Taster; JST_PH_B2B-PH-K_1x02_P2.00mm_Vertical
J7: WS2812; JST_PH_B3B-PH-K_1x03_P2.00mm_Vertical
L1: BLM21PG300; L_0805_2012Metric_Pad1.15x1.40mm_HandSolder
R1, R4: 330; R_0805_2012Metric_Pad1.20x1.40mm_HandSolder
R2, R3: 10k; R_0805_2012Metric_Pad1.20x1.40mm_HandSolder
S1: RESET; SW_SPST_B3U-1000P-B
SW1: PWM/SPI; SW_SPDT_CK_JS102011SAQN
TP1: RESET; TestPoint_Pad_1.0x1.0mm
TP2: +3V3; TestPoint_Pad_1.0x1.0mm
TP3: +5V; TestPoint_Pad_1.0x1.0mm
TP4: GND; TestPoint_Pad_1.0x1.0mm
TP5: TXD; TestPoint_Pad_1.0x1.0mm
TP6: RXD; TestPoint_Pad_1.0x1.0mm
TP7: GDO0; TestPoint_Pad_1.0x1.0mm
TP8: CS; TestPoint_Pad_1.0x1.0mm
U1: MCP1754S-3302xCB; SOT-23
U2: ATmega328P-AU; TQFP-32_7x7mm_P0.8mm
U3: E07-900M10S
Y1: 8MHz; Resonator_Murata_CSTLSxxxX-3Pin_W5.5mm_H3.0mm

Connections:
+3V3: C2.1, C3.1, C4.1, C5.1, J2.2, L1.2, R2.1, R3.1, TP2.1, U2.4 (VCC), U2.6 (VCC), U2.18 (AVCC), U3.9 (VCC)
+5V: J1.2, J1.4, TP3.1, U1.3 (VI)
AREF: C9.1, U2.20 (AREF)
BTN: J1.11, J6.1
CS: R3.2, TP8.1, U2.14 (PB2), U3.19 (~CSN)
GDO0: TP7.1, U2.32 (PD2), U3.15 (GDO0)
GND: C1.2, C2.2, C3.2, C4.2, C5.2, C9.2, D1.1 (K), J1.6, J1.9, J1.14, J1.20, J1.25, J1.30, J1.34, J1.39, J2.6, J5.1, J6.2, J7.3, S1.2, TP4.1, U1.1 (GND), U2.3 (GND), U2.5 (GND), U2.21 (GND), U3.1 (GND1), U3.2 (GND2), U3.3 (GND3), U3.4 (GND4), U3.5 (GND5), U3.11 (GND6), U3.12 (GND7), U3.20 (GND8), U3.22 (GND9), Y1.2
I2C_SCL: J1.5, J5.3
I2C_SDA: J1.3, J5.4
LED_ANODE: D1.2 (A), R1.2
LED_PWM: J1.12, SW1.1 (A)
LED_SPI: J1.19, SW1.3 (C)
LED_TREIBER: R1.1, U2.2 (PD4)
MISO: J2.1, U2.16 (PB4), U3.16 (MISO)
MOSI: J2.4, U2.15 (PB3), U3.17 (MOSI)
PI_3V3: J1.1, J5.2, J7.1
PI_RESET_DRV: C8.1, J1.7
RESET: C8.2, J2.5, R2.2, S1.1, TP1.1, U2.29 (~RESET/PC6)
SCK: J2.3, U2.17 (PB5), U3.18 (SCK)
UART_328_TX: J1.10, TP5.1, U2.31 (PD1)
UART_PI_TX: J1.8, TP6.1, U2.30 (PD0)
VREG_OUT: C1.1, L1.1, U1.2 (VO)
WS_DATA: J7.2, R4.2
WS_WAHL: R4.1, SW1.2 (B)
XTAL1: U2.7 (XTAL1/PB6), Y1.1
XTAL2: U2.8 (XTAL2/PB7), Y1.3

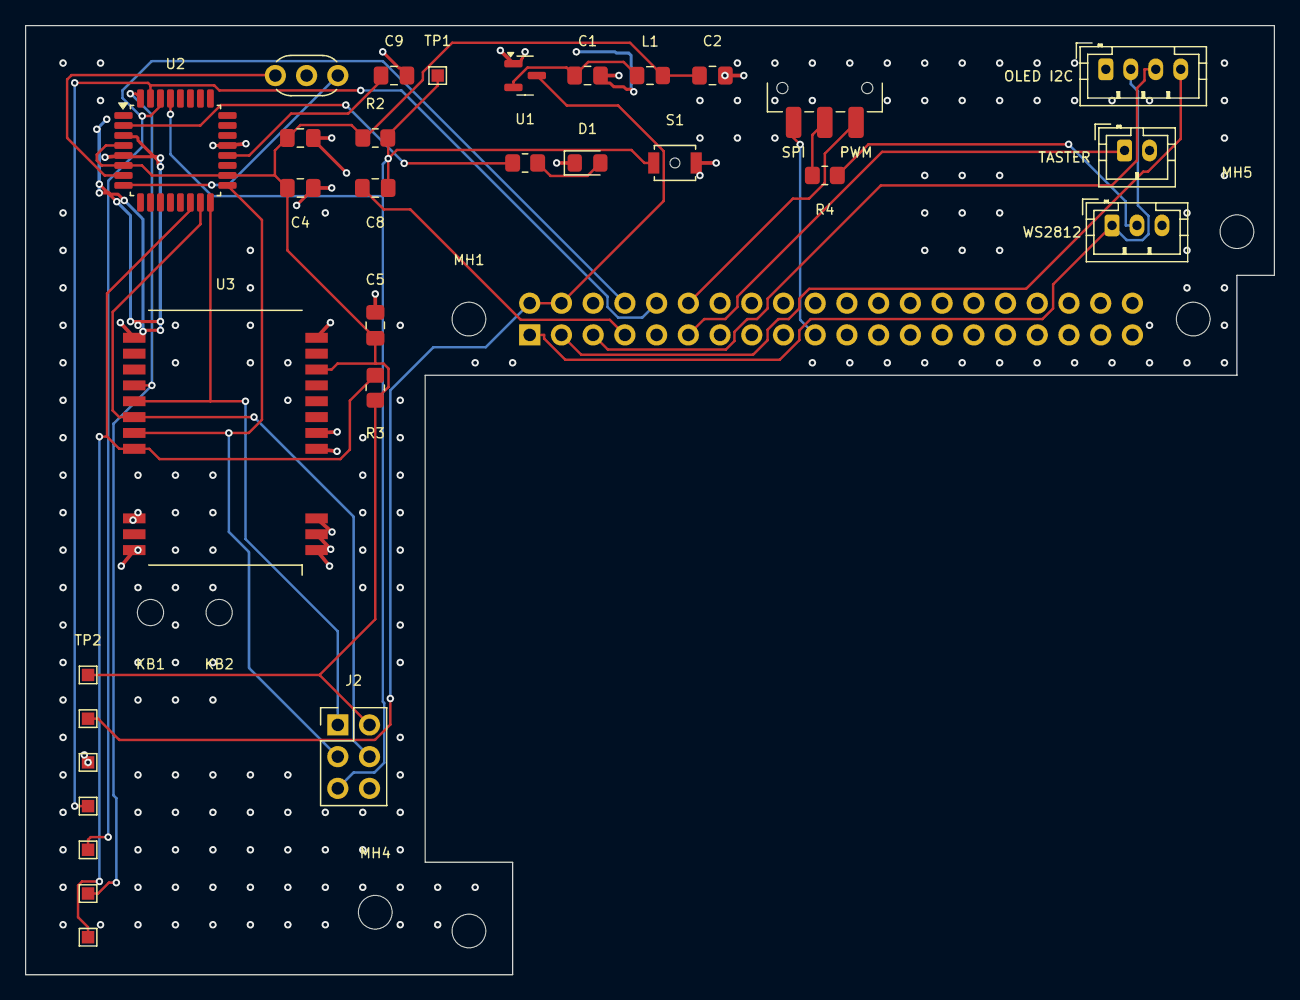
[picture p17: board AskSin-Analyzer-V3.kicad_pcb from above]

Board: 4 copper layers, 100.0 x 76.0 mm, 39 parts (1 on the bottom side), 26 nets.

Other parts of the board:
KB1, KB2: MountingHole_2.1mm
MH1, MH2, MH3, MH4, MH5: MountingHole_2.7mm_M2.5

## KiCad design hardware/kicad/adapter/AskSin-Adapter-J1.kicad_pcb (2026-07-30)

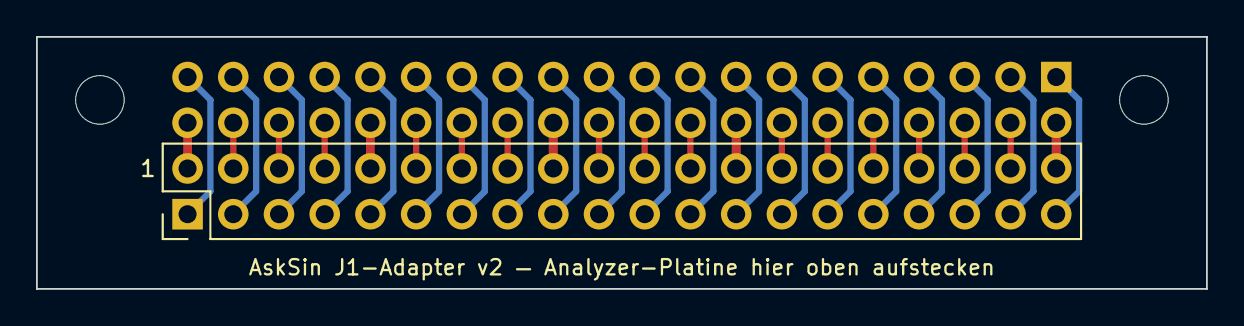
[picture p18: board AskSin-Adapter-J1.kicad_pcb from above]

Board: 2 copper layers, 65.0 x 14.0 mm, 4 parts (1 on the bottom side), 40 nets.

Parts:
J1: Buchsenleiste 2x20 (unten, zum PoE-HAT); PinSocket_2x20_P2.54mm_Vertical
J2: Stiftleiste 2x20 (oben, zur Platine); PinHeader_2x20_P2.54mm_Vertical
MH1, MH2: MountingHole_2.7mm_M2.5

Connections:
P1: J1.40, J2.2
P2: J1.39, J2.1
P3: J1.38, J2.4
P4: J1.37, J2.3
P5: J1.36, J2.6
P6: J1.35, J2.5
P7: J1.34, J2.8
P8: J1.33, J2.7
P9: J1.32, J2.10
P10: J1.31, J2.9
P11: J1.30, J2.12
P12: J1.29, J2.11
P13: J1.28, J2.14
P14: J1.27, J2.13
P15: J1.26, J2.16
P16: J1.25, J2.15
P17: J1.24, J2.18
P18: J1.23, J2.17
P19: J1.22, J2.20
P20: J1.21, J2.19
P21: J1.20, J2.22
P22: J1.19, J2.21
P23: J1.18, J2.24
P24: J1.17, J2.23
P25: J1.16, J2.26
P26: J1.15, J2.25
P27: J1.14, J2.28
P28: J1.13, J2.27
P29: J1.12, J2.30
P30: J1.11, J2.29
P31: J1.10, J2.32
P32: J1.9, J2.31
P33: J1.8, J2.34
P34: J1.7, J2.33
P35: J1.6, J2.36
P36: J1.5, J2.35
P37: J1.4, J2.38
P38: J1.3, J2.37
P39: J1.2, J2.40
P40: J1.1, J2.39

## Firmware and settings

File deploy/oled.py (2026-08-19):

#!/usr/bin/env python3
"""
OLED-Anzeige des AskSin-Analyzers — Portierung aus dem Projekt
**Status-LED-OLED** (ssbingo), mit dessen Bibliotheken, Schriften und Maßen.

Warum als eigener Python-Dienst statt im Core
---------------------------------------------
Der erste Anlauf hat das Display in TypeScript nachgebaut: eigener
SSD1306-Treiber, eigene 5×7-Pixelschrift, eigenes Seitenraster. Das Ergebnis
war auf dem Gerät deutlich schlechter lesbar als das Vorbild — die 5×7-Schrift
ist rund 1,7 mm hoch, während das Original eine **echte TrueType-Schrift in
Fettschnitt** bis 28 px verwendet und ihre Größe je Wert automatisch sucht.

Deshalb kommt hier derselbe Stapel zum Einsatz wie dort:

    board / busio          Blinka — I²C-Bus des Pi
    adafruit_ssd1306       Treiber für das Display
    PIL (Pillow)           Zeichnen, Schriften
    DejaVuSans-Bold.ttf    die große Schrift (Paket fonts-dejavu-core)

Übernommen sind Seitenaufbau, Schriftwahl, `_fit_font`, die Feldliste und die
Übersichtsseite. Ergänzt sind nur die Felder, die es beim Analyzer zusätzlich
gibt (Telegramme, Rauschen, Geräte, Duty-Cycle) — in derselben Form.

Arbeitsteilung
--------------
Der Analyzer-Dienst schreibt seine Werte nach
`/var/lib/asksin-analyzer/oled-state.json` (Zustand, Telegrammrate, Standort,
aktuelle Seite). Die Systemwerte — IP, MAC, Hostname, CPU, RAM, Laufzeit,
Lüfter — liest dieser Dienst selbst, genau wie das Original.

Nach jedem Bild wird der Framebuffer zusätzlich als Base64 nach
`oled-bild.b64` geschrieben. Die Weboberfläche zeigt damit **exakt** das Bild
vom Gerät und nicht einen Nachbau davon.

Aufruf (normalerweise durch asksin-analyzer-oled.service):
    ./oled.py [--zustand PFAD] [--bild PFAD] [--breite 128] [--hoehe 32]
"""

from __future__ import annotations

import argparse
import base64
import json
import os
import signal
import socket
import sys
import time
from pathlib import Path

# Abtastung der Zustandsdatei. Bewusst kurz: Gezeichnet wird nur, wenn sich
# etwas geaendert hat, also kostet ein schneller Takt fast nichts — aber der
# Tastendruck und der Knopf im WebUI wirken damit ohne spuerbare Verzoegerung.
TAKT_S = 0.1
# Kurzlebige Austauschdateien gehoeren nach /run (tmpfs, Arbeitsspeicher) und
# nicht auf die Platte: Der Zustand wird bei jeder Wertaenderung neu
# geschrieben. Auf einem Pi, der ueber USB von einer SSD bootet, ist das
# unnoetige Dauerlast auf genau der Verbindung, die als Wackelkandidat gilt.
# Fehlt /run/asksin-analyzer, bleibt es beim Datenverzeichnis.
ORTE = (Path("/run/asksin-analyzer"), Path("/var/lib/asksin-analyzer"))


def finde_zustand(vorgabe: str | None = None) -> Path:
    """Wo liegt die Zustandsdatei — jetzt, nicht beim Programmstart?

    Beim ersten Anlauf wurde der Ort einmalig beim Import bestimmt. Startete
    der Dienst, bevor /run/asksin-analyzer existierte, fiel er auf
    /var/lib zurueck und blieb dort — waehrend der Core nach /run schrieb.
    Ergebnis: Der Anzeigedienst las eine Datei, die niemand mehr fuellte, und
    der Core fand keine Seitenzahl. Deshalb wird bei jedem Takt geschaut.
    """
    if vorgabe:
        return Path(vorgabe)
    for ort in ORTE:
        datei = ort / "oled-state.json"
        if datei.exists():
            return datei
    return ORTE[0] / "oled-state.json"


def waehle_bildort(neben: Path) -> Path:
    """Wohin das gezeichnete Bild geschrieben wird.

    Normalerweise neben die Zustandsdatei. Ist das Verzeichnis fuer diesen
    Dienst gesperrt — auf dem Geraet lieferte /run trotz RuntimeDirectory ein
    "Read-only file system" —, weicht die Datei nach /var/lib aus. Der Core
    sucht ohnehin an beiden Orten, die Anzeige laeuft also weiter, statt im
    Sekundentakt dieselbe Fehlermeldung zu wiederholen.
    """
    ziel = neben.with_name("oled-bild.b64")
    if os.access(ziel.parent, os.W_OK):
        return ziel
    ausweich = ORTE[1] / "oled-bild.b64"
    if ausweich.parent != ziel.parent and os.access(ausweich.parent, os.W_OK):
        global _AUSWEICH_GEMELDET
        if not _AUSWEICH_GEMELDET:
            _AUSWEICH_GEMELDET = True
            print(f"oled: {ziel.parent} ist gesperrt — Bild geht nach "
                  f"{ausweich.parent}", flush=True)
        return ausweich
    return ziel


_AUSWEICH_GEMELDET = False

# Aus dem Original übernommen.
TTF_KANDIDATEN = (
    "/usr/share/fonts/truetype/dejavu/DejaVuSans-Bold.ttf",
    "/usr/share/fonts/truetype/dejavu/DejaVuSans.ttf",
)


# --------------------------------------------------------------- Systemwerte
# Alle Funktionen dieses Abschnitts stammen aus Status-LED-OLED und sind
# unverändert übernommen, damit Format und Verhalten identisch bleiben.

def get_ip() -> str:
    s = socket.socket(socket.AF_INET, socket.SOCK_DGRAM)
    try:
        s.connect(("8.8.8.8", 80))   # sendet nichts, wählt nur die Route
        return s.getsockname()[0]
    except OSError:
        return "n/a"
    finally:
        s.close()


def get_hostname() -> str:
    try:
        return socket.gethostname()
    except OSError:
        return "n/a"


def get_active_iface() -> str:
    try:
        with open("/proc/net/route", encoding="ascii") as f:
            next(f)
            for zeile in f:
                teile = zeile.split()
                if len(teile) > 2 and teile[1] == "00000000":
                    return teile[0]
    except (OSError, StopIteration):
        pass
    return ""


def get_mac() -> str:
    iface = get_active_iface()
    if not iface:
        return "n/a"
    try:
        mac = Path(f"/sys/class/net/{iface}/address").read_text().strip()
        return mac.upper() if mac else "n/a"
    except OSError:
        return "n/a"


def get_mem_mb() -> tuple[int, int]:
    try:
        info = {}
        with open("/proc/meminfo", encoding="ascii") as f:
            for zeile in f:
                key, _, val = zeile.partition(":")
                info[key] = int(val.strip().split()[0])          # kB
        total = info["MemTotal"] // 1024
        avail = info.get("MemAvailable", info.get("MemFree", 0)) // 1024
        return max(total - avail, 0), total
    except (OSError, KeyError, ValueError, IndexError):
        return 0, 0


def get_uptime_s() -> float:
    try:
        with open("/proc/uptime", encoding="ascii") as f:
            return float(f.read().split()[0])
    except (OSError, ValueError, IndexError):
        return 0.0


def get_temp_c() -> float:
    try:
        with open("/sys/class/thermal/thermal_zone0/temp", encoding="ascii") as f:
            return int(f.read().strip()) / 1000.0
    except (OSError, ValueError):
        return 0.0


def get_load() -> float:
    try:
        return os.getloadavg()[0]
    except OSError:
        return 0.0


def get_fan_rpm() -> int | None:
    """Lüfterdrehzahl aus hwmon — Pi 5 und geregelte PoE-HATs melden sie dort."""
    try:
        for eintrag in os.listdir("/sys/class/hwmon"):
            pfad = Path(f"/sys/class/hwmon/{eintrag}/fan1_input")
            if pfad.exists():
                return int(pfad.read_text().strip())
    except (OSError, ValueError):
        pass
    return None


def get_disk_frei_prozent(pfad: str = "/") -> float | None:
    try:
        s = os.statvfs(pfad)
        return s.f_bavail / s.f_blocks * 100 if s.f_blocks else None
    except OSError:
        return None


def fmt_uptime(seconds: float) -> str:
    s = int(seconds)
    d, h, m = s // 86400, (s % 86400) // 3600, (s % 3600) // 60
    if d:
        return f"{d}d{h}h"
    if h:
        return f"{h}h{m}m"
    return f"{m}m"


# ------------------------------------------------------------------- Felder

def lies_zustand(pfad: str) -> dict:
    """Werte des Analyzers; fehlt die Datei, bleibt alles leer."""
    try:
        with open(pfad, encoding="utf8") as f:
            wert = json.load(f)
        return wert if isinstance(wert, dict) else {}
    except (OSError, ValueError):
        return {}


# Kennung der Funkstatus-Seite. Sie ist die einzige Seite, die nicht aus
# Beschriftung und Wert besteht, sondern aus zwei Sinnbildern — deshalb wird
# sie an ihrem Label erkannt und getrennt gezeichnet. Ein Label, das kein
# Anwender je zu sehen bekommt, darf dafuer ruhig technisch aussehen.
STATUS_SEITE = "\x00funkstatus"


def zeichne_zigbee(d, x: int, y: int, groesse: int) -> None:
    """
    Das Zigbee-Zeichen: eine gefuellte Scheibe mit ausgespartem Z.

    Nachempfunden dem Logo aus der Vorlage — dort eine rote Kugel mit weissem
    Z. Auf einem einfarbigen Panel bleibt davon Flaeche und Aussparung: Die
    Scheibe traegt, das Z steht als Loch darin. Umgekehrt (Z als Strich auf
    leerem Grund) waere es bei dieser Groesse ein Gekritzel.
    """
    r = groesse // 2
    cx, cy = x + r, y + r
    d.ellipse((cx - r, cy - r, cx + r, cy + r), fill=255)

    # Das Z als Aussparung. Die Balken sind bewusst dick: Ein Ein-Pixel-Loch
    # in einer gefuellten Flaeche verschwindet auf dem Panel vollstaendig.
    dick = max(2, groesse // 7)
    rand = max(3, groesse // 4)
    o = y + rand                      # Oberkante des Z
    u = y + groesse - rand - dick     # Unterkante
    li = x + rand
    re = x + groesse - rand
    d.rectangle((li, o, re, o + dick - 1), fill=0)
    d.rectangle((li, u, re, u + dick - 1), fill=0)
    # Die Schraege von rechts oben nach links unten.
    d.line((re - dick // 2, o + dick, li + dick // 2, u - 1), fill=0,
           width=dick)


def zeichne_bidcos(d, x: int, y: int, groesse: int) -> None:
    """
    Das BidCoS-Zeichen: ein Sender, der nach beiden Seiten funkt.

    Eigener Entwurf — fuer BidCoS gibt es kein Zeichen, das man verwenden
    duerfte oder das jemand wiedererkennen wuerde. Gewaehlt ist das, was das
    Netz ausmacht und es zugleich vom Zigbee-Zeichen abhebt: **beidseitige**
    Bogen, denn BidCoS ist bidirektional — das steckt im Namen. Flaeche gegen
    Linie, Scheibe gegen Bogen: Die beiden Zeichen sind auch aus zwei Metern
    nicht zu verwechseln.

    Der erste Entwurf hatte ausgestellte Mastbeine und sah dadurch aus wie ein
    Strichmaennchen. Jetzt steht der Mast auf einem geraden Fuss, und die
    Bogen sind so gross, dass sie die Bildbreite tragen.
    """
    cx = x + groesse // 2
    fuss = y + groesse - 1
    # Der Sendepunkt sitzt knapp oberhalb der Mitte. Im ersten Entwurf lag er
    # im oberen Drittel — dann ragten die aeusseren Bogen ueber die Oberkante
    # hinaus und wurden abgeschnitten. Ueber dem Punkt muss so viel Platz
    # bleiben, wie der aeussere Bogen weit ist.
    punkt = y + (groesse * 45) // 100
    dick = max(1, groesse // 12)

    # Mast und Fuss.
    d.line((cx, punkt, cx, fuss), fill=255, width=max(2, dick + 1))
    d.line((cx - groesse // 4, fuss, cx + groesse // 4, fuss),
           fill=255, width=max(2, dick + 1))

    # Zwei Bogenpaare nach links und rechts. Die Weiten sind Anteile der
    # Zeichengroesse, damit das Zeichen auf 32er- und 64er-Panels gleich
    # aussieht statt einmal verloren und einmal abgeschnitten.
    for weite in (groesse // 4, (groesse * 2) // 5):
        if weite < 3:
            continue
        kasten = (cx - weite, punkt - weite, cx + weite, punkt + weite)
        d.arc(kasten, 195, 255, fill=255, width=max(2, dick + 1))   # links
        d.arc(kasten, 285, 345, fill=255, width=max(2, dick + 1))   # rechts

    # Der Sendepunkt selbst — voll, damit klar ist, wo die Bogen herkommen.
    r = max(1, groesse // 12)
    d.ellipse((cx - r, punkt - r, cx + r, punkt + r), fill=255)


def zeichne_haken(d, x: int, y: int, groesse: int) -> None:
    """Haken — „laeuft". Zwei Striche, dick genug fuer ein 128er-Panel."""
    dick = max(2, groesse // 6)
    d.line((x, y + groesse * 3 // 5, x + groesse * 2 // 5, y + groesse - 1),
           fill=255, width=dick)
    d.line((x + groesse * 2 // 5, y + groesse - 1, x + groesse - 1, y),
           fill=255, width=dick)


def zeichne_kreuz(d, x: int, y: int, groesse: int) -> None:
    """Kreuz — „aus". Bewusst gleich gross wie der Haken, damit die beiden
    Seiten der Anzeige optisch gleich schwer wiegen."""
    dick = max(2, groesse // 6)
    d.line((x, y, x + groesse - 1, y + groesse - 1), fill=255, width=dick)
    d.line((x + groesse - 1, y, x, y + groesse - 1), fill=255, width=dick)


def oled_fields(z: dict) -> list[tuple[str, str]]:
    """
    Geordnete (Label, Wert)-Paare — die großen Einzelseiten.

    Reihenfolge nach Vorgabe: **Standort zuerst** (die Startseite), danach
    alles zum Analyzer, erst dann die Systemwerte aus dem Original. Format der
    Systemfelder unverändert übernommen.
    """
    benutzt, gesamt = get_mem_mb()
    duty = z.get("maxDutyCycle")
    rauschen = z.get("noiseFloor")

    felder: list[tuple[str, str]] = [
        # --- Startseite ------------------------------------------------------
        ("Standort", str(z.get("standort", "n/a"))),
        # --- Analyzer --------------------------------------------------------
        ("Sniffer", str(z.get("status", "n/a"))),
        # Dritte Seite: Was hoert dieses Geraet ueberhaupt mit? Zwei Haelften,
        # links BidCoS, rechts Zigbee — die Reihenfolge des Analyzers selbst.
        (STATUS_SEITE, ""),
        ("Telegramme", f"{z.get('telegramsPerMinute', 0)}/min"),
        ("Rauschen", "n/a" if rauschen is None else f"{rauschen}dBm"),
        ("Geräte", str(z.get("deviceCount", 0))),
    ]
    if isinstance(duty, dict):
        felder.append(("Duty-Cycle", f"{float(duty.get('percent', 0)):.1f}%"))

    # Dauersender bekommen je eine eigene Seite: Ein defektes Geraet kann das
    # ganze Funknetz zustopfen, und dann will man am Geraet WELCHES sehen,
    # nicht nur dass irgendetwas hoch ist. Der Name steht als Beschriftung
    # oben, der Prozentwert gross darunter.
    alarme = z.get("dutyAlarme")
    if isinstance(alarme, list):
        for eintrag in alarme:
            if not isinstance(eintrag, dict):
                continue
            name = str(eintrag.get("name", "?"))
            prozent = float(eintrag.get("percent", 0))
            felder.append((f"! {name}", f"{prozent:.0f}%"))

    felder.append(("Version", str(z.get("version", "?"))))

    # --- System (Reihenfolge und Format aus dem Original) --------------------
    felder += [
        ("IP", get_ip()),
        ("MAC", get_mac()),
        ("Host", get_hostname()),
        ("CPU", f"{get_temp_c():.0f}C L{get_load():.2f}"),
        ("RAM", f"{benutzt}/{gesamt}MB"),
        ("Up", fmt_uptime(get_uptime_s())),
    ]
    frei = get_disk_frei_prozent()
    if frei is not None:
        felder.append(("Disk", f"{frei:.0f}% frei"))
    upm = get_fan_rpm()
    if upm is not None:
        felder.append(("Fan", f"{upm}rpm"))
    return felder


def oled_lines(z: dict) -> list[str]:
    """Die vier Textzeilen der Übersicht — Aufbau wie im Original.

    Die Werte kommen bewusst aus `oled_fields`, damit Übersicht und
    Einzelseiten nie auseinanderlaufen. Der Schlüssel der letzten Zeile heisst
    hier **Sniffer** statt „Status" — nach der Umbenennung des Labels blieb die
    Zeile sonst leer, weil der alte Schlüssel ins Leere griff.
    """
    f = dict(oled_fields(z))
    return [
        f"IP {f.get('IP', '')}",
        f"CPU {f.get('CPU', '')}",
        f"RAM {f.get('RAM', '')}",
        f"Sniffer {f.get('Sniffer', '')}",
    ]


def seiten_anzahl(z: dict) -> int:
    """Die großen Einzelseiten plus die Übersicht, die hinten anhängt."""
    return len(oled_fields(z)) + 1


# ------------------------------------------------------------------ Anzeige
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

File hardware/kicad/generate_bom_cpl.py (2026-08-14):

#!/usr/bin/env python3
"""
Erzeugt BOM- und Pick-&-Place-Datei (CPL) aus der **gerouteten Platine**.

Arbeitet ausschließlich lesend auf der Platinendatei — die ist in Produktion
und wird von diesem Skript unter keinen Umständen verändert.

Ausgabeformat nach der verbreiteten Bestücker-Konvention (JLCPCB u. a.):

  fab/bom.csv   Comment · Designator · Footprint · Quantity  (+ Bezugsquelle)
  fab/cpl.csv   Designator · Mid X · Mid Y · Layer · Rotation

Koordinaten: Ursprung in der **linken unteren Platinenecke**, X nach rechts,
Y nach oben, Millimeter — so erwarten es die gängigen Bestücker. KiCads
Positionsexport liefert dagegen Blattkoordinaten; die Umrechnung passiert hier.

Ausgelassen werden:
  * R4 — seit 30.07.2026 unbestückt: die Analyzer-Software steuert die
    WS2812 auf dem Pi 5 über SPI, bestückt wird deshalb R5 (330 Ω, GPIO10).
    R4 (390 Ω, PWM/GPIO18) bleibt als Alternative für Pi 3/4 auf der Platine —
    bestückt wird immer genau einer von beiden
  * TP1–TP8, MH1–MH4, KB1/KB2 — Pads und Bohrungen ohne Bauteil

Hinweis Drehwinkel: Die Werte folgen der KiCad-Konvention (Winkel der
Footprint-Definition). Bestücker haben teils abweichende Nulllagen je Gehäuse
(bekannt bei SOT-23 und gedrehten ICs) und korrigieren das in ihrer
Eingangsprüfung — bei Handbestückung ohnehin belanglos.

Aufruf:
    python3 generate_bom_cpl.py
"""

from __future__ import annotations

import csv
import pathlib
import sys

import pcbnew

from generate_schematic import PROJECT

HERE = pathlib.Path(__file__).resolve().parent
BOARD_FILE = HERE / f"{PROJECT}.kicad_pcb"
FAB_DIR = HERE / "fab"

# Ursprung und Höhe der Platine in Blattkoordinaten (aus generate_pcb.py).
import generate_pcb as G
from generate_schematic import COMPONENTS

ORIGIN_X, ORIGIN_Y = G.ORIGIN_X, G.ORIGIN_Y
BOARD_H = G.LEG_Y1          # Gesamthöhe inkl. Schenkel — Ursprung unten links

# Unbestückte Plätze werden **aus dem Schaltplan abgeleitet**, nicht von Hand
# gepflegt: Ein Wert, der „DNP" enthält, gilt als nicht zu bestücken.
#
# Warum das wichtig ist: Bis zum 31.07.2026 stand hier `DNP = {"R4"}` — ein
# Überbleibsel aus der Zeit, als R4 die unbestückte PWM-Alternative zu R5 war.
# Nach dem Umbau auf den Schiebeschalter wurde R4 zum einzigen
# Serienwiderstand der LED-Datenleitung, die Liste blieb aber stehen. Folge:
# R4 fehlte in BOM und CPL. Eine von Hand gepflegte Liste driftet; eine
# abgeleitete kann es nicht.
DNP = {ref for ref, (_lib, wert, *_rest) in COMPONENTS.items()
       if "DNP" in wert.upper()}

WERT_KORREKTUR: dict[str, str] = {}
VIRTUAL_PREFIXES = ("TP", "MH", "KB")

# Bezugsquellen aus der geprüften Bestellliste (../bestellliste-reichelt.md).
SOURCE = {
    "U1": "Reichelt MCP 1754-3302CB",
    "U2": "Reichelt ATMEGA 328P-AU",
    "U3": "Ebyte E07-900M10S — nicht bei Reichelt",
    "Y1": "JLCPCB C83707 (CSTLS8M00G53-B0)",
    "J1": "Reichelt MPE 094-2-040",
    "J2": "Reichelt ECON SL6G2",
    "J5": "Reichelt JST PH4P ST",
    "J6": "Reichelt JST PH2P ST",
    "J7": "Reichelt JST PH3P ST",
    "L1": "Reichelt BLM21PG300SN1D",
    "D1": "Reichelt EVL 17-21USRC",
    "S1": "JLCPCB C231329 (B3U-1000P)",
    "SW1": "JLCPCB C221660 (C&K JS102011SAQN)",
    "R1": "Reichelt WAL WR08X3300FTL",
    "R4": "Reichelt WAL WR08X3300FTL",
    "R5": "JLCPCB C17630 (330R 0805) — wie R1",
    "R2": "Reichelt WAL WR08X1002FTL",
    "R3": "Reichelt WAL WR08X1002FTL",
    "C1": "Reichelt CL21A106KOQNNNG",
    "C2": "Reichelt CL21A106KOQNNNG",
    "C3": "Reichelt KEM X7R0805 100N",
    "C4": "Reichelt KEM X7R0805 100N",
    "C5": "Reichelt KEM X7R0805 100N",
    "C8": "Reichelt KEM X7R0805 100N",
    "C9": "Reichelt KEM X7R0805 100N",
}


# ---------------------------------------------------------------- JLCPCB
#
# Zuordnung für die Bestückung bei JLCPCB, recherchiert am 28.07.2026,
# ergänzt am 30.07.2026 (R5 statt R4, S1 → C231329, Y1 → C83707).
# Grundsatz weiterhin SMD; einzige THT-Ausnahme ist der Resonator Y1
# (CSTLS8M00G53-B0, Wellenlöten laut JLCPCB-Katalog). Die übrigen
# bedrahteten Teile (J1, J2, J5–J7) werden von Hand bestückt, ebenso das
# Funkmodul U3: seit dem 14.08.2026 als C9900007000 bestueckbar.
#
# „Basic“ nach der Basic-Parts-Momentaufnahme; der verbindliche Status steht
# erst im Bestellportal (Extended kostet je Position Einrichtungsgebühr).
JLC = {
    # ref: (LCSC-Nummer, MPN/Kommentar, Basic laut Momentaufnahme)
    # Kommentare bewusst ohne Kommas — der BOM-Parser des Portals ist bei
    # Sonderzeichen wählerisch. Begründungen stehen in der LIESMICH.
    "U1": ("C5446", "XC6206P332MR-G", True),
    "U2": ("C14877", "ATMEGA328P-AU", False),
    # C231330 (B3U-1000P-B) war nicht lieferbar; C231329 ist die Variante
    # ohne Zentrierstift — gleiche Pads, die Stiftbohrung bleibt leer.
    "S1": ("C231329", "B3U-1000P", False),
    # Umschalter PWM/SPI. Amtlicher KiCad-Footprint, deshalb dieser Typ und
    # nicht der billigere MSK-12C02, fuer den ein Footprint von Hand haette
    # gezeichnet werden muessen.
    "SW1": ("C221660", "JS102011SAQN SPDT-Schiebeschalter", False),
    # THT-Ausnahme: passt exakt auf den CSTLS-Footprint (SIP-3 RM 2.5mm).
    "Y1": ("C83707", "CSTLS8M00G53-B0 8MHz", False),
    "L1": ("C16903", "BLM21PG300SN1D", False),
    "D1": ("C84256", "FC-2012HRK-620D rot", True),
    "R1": ("C17630", "330R 1% 0805", True),
    # Serienwiderstand der WS2812-Datenleitung, hinter dem Schalter SW1.
    "R4": ("C17630", "330R 1% 0805", True),
    "R2": ("C17414", "10K 1% 0805", True),
    "R3": ("C17414", "10K 1% 0805", True),
    "R5": ("C17630", "330R 1% 0805 (Datenleitung WS2812)", True),
    "C1": ("C15850", "CL21A106KAYNNNE 10uF 25V X5R", True),
    "C2": ("C15850", "CL21A106KAYNNNE 10uF 25V X5R", True),
    "C3": ("C49678", "CC0805KRX7R9BB104 100nF 50V X7R", True),
    "C4": ("C49678", "CC0805KRX7R9BB104 100nF 50V X7R", True),
    "C5": ("C49678", "CC0805KRX7R9BB104 100nF 50V X7R", True),
    "C8": ("C49678", "CC0805KRX7R9BB104 100nF 50V X7R", True),
    "C9": ("C49678", "CC0805KRX7R9BB104 100nF 50V X7R", True),
    # Funkmodul, ab 14.08.2026 bei JLCPCB bestueckbar.
    #
    # C9900007000 ist eine "JLCPCB Assembly"-Position: Sie wird in die eigene
    # Teilebibliothek gekauft und ist NUR fuer PCBA-Auftraege verwendbar, ein
    # Einzelversand gibt es nicht. Katalogangabe LCC-22, 20,0 x 14,0 mm,
    # Raster 1,27 mm — das ist unser Modul, Masse und Halbloch-Raster stimmen
    # mit hardware/README.md ueberein. Freigegeben fuer Economic und Standard.
    #
    # Warum das mehr ist als Bequemlichkeit: Am 14.08.2026 fiel eine von fuenf
    # handbestueckten Platinen aus, weil beim Loeten des Moduls eine Bruecke
    # zwischen Pad 16 (MISO) und Pad 17 (MOSI) entstand — benachbarte
    # Halbloecher im 1,27-mm-Raster. Der USBasp las dadurch seine eigenen
    # Bits zurueck und meldete "target does not answer". Genau diese
    # Fehlerklasse faellt mit Maschinenbestueckung weg.
    "U3": ("C9900007000", "E07-900M10S", False),
}
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

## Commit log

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2026-07-28 Namensauflösung: DeviceResolver + CCU-Dekodierung gegen echte Anlagendaten
    Fixture ist der unveränderte DevList-Export einer realen RaspberryMatic
    (241 Einträge). Er brachte die Fälle mit, an denen ein naiver Resolver
    scheitert: doppelte Adressen (Rauchmelder-Gruppen mit *-Serial, Zentrale
    zweimal), Umlaute (latin1-Abruf), Eigenbau-Geräte mit Adressen < 0x10000.
    - parseDevList: Strukturvalidierung mit klaren Fehlermeldungen
    - classify/DeviceResolver: Adresse → Einträge[] mit Vorrang Gerät > Zentrale
    > Pseudo > Gruppe; unbekannte Adressen liefern die Sniffer-Hex-Darstellung
    - decodeCcuResponse: latin1 + <ret>-Hülle + HTML-Escapes als reine Funktionen
    - 14 neue Tests (43 gesamt)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
2026-07-28 Serial-Ingest (M2): Zeilenstrom-Leser mit Watchdog, Backoff und Drop-Oldest
    - LineSplitter: bytebasiert (latin1, wirft nie), Überlängen-Schutz gegen
    Speicherwachstum bei falscher Baudrate
    - BoundedQueue: entkoppelt Leser und Verbraucher, Drop-Oldest mit Zähler
    - Watchdog auf die 750-ms-Rauschzeilen: Stille = tote Strecke → Neuaufbau;
    einzige brauchbare Fehlererkennung an einer fest verdrahteten UART
    - Reconnect mit exponentiellem Backoff; Reset und connected erst ab erster
    gültiger Zeile (info.connection-Semantik), nicht beim Portöffnen
    - Produktionsport ohne native Abhängigkeit: stty (BOTHER kann 58824) +
    lesender Dateistrom; Port und Uhr injizierbar
    - Zwei im Test gefundene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
2026-07-28 Persistenz + Live-Statistik (M3 komplett): node:sqlite, Recorder, LiveStats
    - openDatabase: eingebautes node:sqlite (keine native Abhängigkeit), WAL,
    synchronous=NORMAL, Migrationen über user_version
    - Schema: telegrams einzeln, noise_minutes als Minutenaggregat (statt
    115k Rauschzeilen/Tag), device_hours mit Airtime für Langzeit-Duty-Cycle
    - Recorder: gebündelte Transaktionen (SD-Karten-schonend), delta-basierte
    Aggregate mit additivem Upsert — Neustart mitten in der Stunde addiert
    weiter statt zu überschreiben; Retention je Tabelle + WAL-Checkpoint
    - LiveStats: Grundrauschen (last + EWMA), gleitende 60-s-Telegrammrate im
    Sekunden-Ring, RSSI je Gerät — rein aus Zeilen-Ze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
2026-07-28 CCU-Abruf + Dienst-Komposition (M4 komplett): DevListService und Analyzer
    - DevListService: zyklischer Abruf der Geräteliste von der CCU
    (stündlich, nach Fehlern 5 min), atomarer Datei-Cache (tmp+rename),
    letzter Resolver bleibt bei Fehlschlägen nutzbar; HTTP und Uhr
    injizierbar
    - Analyzer (src/service/): verdrahtet Ingest → Recorder + LiveStats +
    DutyCycle + DevList; Flush- und Aufräumtakt; snapshot() als eine
    Leseschnittstelle für die M5-API; Abschluss-Flush bei stop()
    - Geteilte Test-Attrappen (FakeTime, FakePort, alsCcuAntwort) nach
    test/helpers/, ingest.test.ts nutzt sie
    - 91 Tests grün, tsc --noEmit sauber; READMEs auf Stand M4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
2026-07-28 REST-API (M5): XS-Kompat-Endpunkte + /api/* auf node:http
    - Kompatibilitätssatz der Original-Web-UI (docs/webui-und-updates.md §2):
    getLogByLogNumber (CSV über rowid-lognumber, Batchgrenze 50),
    getRSSILog (Minutenmittel, Sekunden-tstamps), getConfig (alle Felder
    der Info-Ansicht, SPIFFS ≙ SQLite-Größe), getAskSinAnalyzerDevListJSON
    (charset im Content-Type), setConfig/reboot/formatspiffs/deletecsv,
    Tages-CSV-Download aus der Datenbank, SD-Attrappen, 501 fürs
    ESP-Config-Portal
    - Eigene API: /api/snapshot und /api/health
    - Sicherheit nach §5: Bind an 127.0.0.1, optionaler Bearer-Token für
    verändernde Routen, kein httpupdate-Nachbau
    - DevListService hält jetzt auch das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
2026-07-28 Ein-Befehl-Installation: analyzerd, install.sh, systemd, CLI-Wrapper
    - core/bin/analyzerd.ts: Dienst-Einstiegspunkt — JSON-Konfiguration,
    Komposition (Analyzer + DevList + ApiServer + Web-UI), journald-Logs,
    sauberes Herunterfahren; /reboot beendet mit Exit 0 (systemd startet neu)
    - install.sh nach dem Vorbild des Status-LED-Projekts: idempotent,
    Raspberry-Erkennung, Node 24 via NodeSource, Repo nach /opt, UI-Build,
    Dienstbenutzer asksin (dialout), Konfigurations-Assistent (CCU, Port,
    LAN-Bindung, zufälliges Auth-Token), udev-Regel, optionale
    UART-Einrichtung mit Neustart-Erkennung, systemd-Unit, CLI-Wrapper
    - update.sh + Verwaltungsbefehl asksin-analyzer
    (status/logs/health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
2026-07-28 Testdaten anonymisiert: synthetische Beispielanlage statt echtem CCU-Export
    Die DevList-Fixture ist jetzt eine erzeugte Anlage mit identischer
    Struktur (241 Einträge, 237 Adressen, Doppel-Zentrale, Rauchmelder-Teams,
    Umlaute, HmIP-Serials, Pseudo-Multicasts), aber erfundenen Namen und
    Seriennummern. Tests und Docstrings entsprechend umgestellt; 108 Tests
    grün. Vorbereitung der Veröffentlichung des Repos.
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2026-07-29 Verbund-Dashboard (M9.2) + Netzwerkeinstellungen über die Web-UI (M7.6)
    M9.2 — Föderation:
    - VerbundDienst: paralleler Fan-out auf /api/health + /api/snapshot der
    Peers, fehlertolerant je Standort, Zeitdrift-Messung (korrigiert um die
    halbe Laufzeit, Warnschwelle 1 s fürs Dedup-Fenster M9.3), kurzer
    Cache, geteilte Fan-outs bei gleichzeitigen Aufrufen
    - Konfiguration verbund.peers auf genau einem Pi; die eigene Instanz
    wird automatisch als erster Eintrag ergänzt
    - Neue UI-Ansicht „Verbund": Kachel je Standort (Sniffer-Status,
    Tel/min, Rauschen, max. Duty-Cycle, Version, DEMO/Update-Chips,
    Drift-Warnung), Drilldown zur Peer-UI; ohne Rolle eine Anleitung
    M7.6 — Netzwerk: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
2026-07-30 19-Zoll-Rahmen: zweite Remix-Quelle für den SSD-Rahmen dokumentiert
    Der SSD-Rahmen leitet sich von „2.5 SSD/HDD Hot swap holder for
    Modular trays" von balazsgrill ab (Printables 1433279), ebenfalls
    CC BY-NC-SA 4.0 — die Lizenzlage bleibt unverändert einheitlich.
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2026-07-30 J1-Rettungsadapter für die fehlerhaften Chargen der Hardware v0.0.1
    Auf den gefertigten Platinen ist die gerade Pin-Reihe von J1 gespiegelt
    (2,54 mm auf der falschen Seite der — korrekt sitzenden — ungeraden
    Reihe). Der Adapter korrigiert das: Stapelbuchse 2x20 kopfüber in
    korrekter HAT-Position (ungerade Stifte reichen durch), gerade Signale
    über Leiterbahnen auf eine um 2,54 mm versetzte 1x20-Stiftleiste.
    Analyzer-Platine steckt dann normal, alle Pads auf den richtigen
    Pi-Pins, MH1/MH2 fluchten wieder. Generiert, Sollgeometrie im Skript
    gegen die offizielle HAT-Vorlage geprüft, DRC 0/0, Gerber + Bohrdaten
    + Layout-PDF als Fertigungspaket.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
    [AskSin-Adapter-J1-B_Cu.gbl, AskSin-Adapter-J1-B_Mask.gbs, AskSin-Adapter-J1-B_Silkscreen.gbo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]
2026-07-30 Hardware v0.1.0: J1 korrigiert, Platine liegt jetzt neben dem Pi
    Zwei Ursachen, ein Neuentwurf:
    1. **J1 war gespiegelt.** Der Footprint wurde aus der offiziellen Vorlage
    RaspberryPi-HAT übernommen, aber ohne deren Flip auf die Unterseite.
    Die ungerade Pinreihe saß dadurch richtig, die gerade 2,54 mm auf der
    falschen Seite — aufgesteckt landet jedes Pad einen Pin daneben
    (5 V auf 3,3 V, Masse auf GPIOs). generate_pcb.py flippt J1 jetzt wie
    die Vorlage und prüft die vier Eckpads hart gegen das Pi-Raster; ein
    erneuter Fehler bricht den Lauf ab.
    2. **Neue Bauform:** T-förmig statt L-förmig. Der Körper (88 × 34 mm)
    liegt parallel neben dem Pi an der Header-Seite un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
    [AskSin-Analyzer-V3-B_Cu.gbl, AskSin-Analyzer-V3-B_Mask.gbs, AskSin-Analyzer-V3-B_Silkscreen.gbo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]
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2026-07-30 Status-LED D1 entpolt — sie konnte nie leuchten
    Im KiCad-Symbol Device:LED ist Pin 1 die Kathode. Auf der Platine lag
    Pin 1 an R1 (also am Treiber) und Pin 2, die Anode, an Masse. Die
    Firmware schaltet ihren Pin aktiv auf HIGH (AskSinPP Led::ledOn ->
    setHigh, invert() wird nie gesetzt), der Strom hätte also von Masse
    gegen die Diodenrichtung zum Mikrocontroller fließen müssen.
    Netzliste korrigiert: LED_TREIBER (U2.2 -> R1.1), LED_ANODE
    (R1.2 -> D1.2), D1.1 an GND. Nachgerechnet: 3,9 mA bei 3,3 V und
    330 Ohm mit einer roten LED — passt zu R1.
    Bei der Gelegenheit ein Loch in der eigenen Prüfkette geschlossen:
    rebuild.py verglich gegen die zuletzt abgelegte netlist.net statt gegen
    ein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
    [AskSin-Analyzer-V3-B_Cu.gbl, AskSin-Analyzer-V3-B_Mask.gbs, AskSin-Analyzer-V3-B_Silkscreen.gbo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]
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2026-07-31 Systemjournal mitlesen — „lag es an uns oder am System?"
    Silvios Rueckfrage traf einen echten blinden Fleck: Das Protokoll zeigte
    nur, was der Analyzer selbst bemerkt. Gerade die Beweise dafuer, dass
    eine Stoerung NICHT aus der Anwendung kam, stehen aber im Journal von
    systemd — und die sieht unser Prozess nie.
    Neu: src/log/systemlog.ts liest das Journal ueber den Cursor mit (keine
    Doppelungen, lueckenlos ueber Dienst-Neustarts) und erkennt die
    klassischen Systemursachen: Unterspannung und Ueberstrom aus dem Kernel,
    OOM-Killer, USB-Resets (die Boot-SSD!), EXT4-/E-A-Fehler,
    Temperaturnotabschaltung, Watchdog und Kernel-Panik, SD-Karten-Fehler,
    Segfaults. Treffer landen als FEHLER, alle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
2026-07-31 Doku und Handbuch auf Hardware v0.2.0 und das Protokoll nachgezogen
    Die Platine geht in Produktion — also muss die Doku stimmen. Durchgesehen
    und korrigiert:
    README: Bauform L-foermig 100 x 76 mm statt der alten T-Beschreibung, der
    Schiebeschalter SW1 statt der Regel „R4 oder R5", Projektstand auf „in
    Produktion", Protokoll (M13) in die Tabelle und den Verzeichnisbaum.
    Bestellliste: R5 (0 Ohm) entfaellt, dafuer R4 = 330 Ohm und der Schalter
    C&K JS102011SAQN; der Hinweis zur JLCPCB-Bestueckung nennt die neuen
    Teilenummern.
    Handbuch (jetzt 64 Seiten):
    - Kapitel 4: Bauteilgruppen mit SW1 und R4, neuer Kasten „Der Schalter
    SW1: PWM oder SPI" mit der Begruendung je Pi-Generation, Bil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
2026-07-31 Zwei echte Fehler aus Silvios Protokoll behoben
    Das neue Protokoll hat sich sofort bezahlt gemacht — es zeigt beide
    Fehler schwarz auf weiss.
    **1. netz-anwenden.sh war nicht ausfuehrbar** (Git-Modus 644). Die Unit
    scheiterte mit "Failed at step EXEC ... Permission denied"; weil die
    Auftragsdatei dadurch liegen blieb, feuerte die Path-Unit endlos nach bis
    "Start request repeated too quickly" und "unit-start-limit-hit". Behoben
    dreifach: Ausfuehrungsrecht im Repository gesetzt (auch fuer led-pwm.py),
    install.sh und update.sh setzen es zusaetzlich ausdruecklich, und die
    Unit raeumt die Auftragsdateien jetzt per ExecStopPost in JEDEM Fall weg
    — damit kann diese Schleife auch bei anderer Urs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
    [led-pwm.py]
2026-07-31 R4 fehlte in Bestueckung und CPL — DNP-Liste war von Hand gepflegt
    Silvio hat es in der Bestueckungsvorschau gesehen: R4, der einzige
    Serienwiderstand der WS2812-Datenleitung, fehlte in BOM und CPL.
    Ursache: In generate_bom_cpl.py stand `DNP = {"R4"}` — ein Ueberbleibsel
    aus der Zeit, als R4 die unbestueckte PWM-Alternative zu R5 war. Beim
    Umbau auf den Schiebeschalter wurde R4 zum bestueckten Bauteil, die von
    Hand gepflegte Liste blieb aber stehen.
    Warum meine Pruefung es nicht fand: Sie benutzte **dieselbe falsche
    Liste** wie der Erzeuger und uebersprang alles, was dort als DNP stand.
    Eine Pruefung, die der zu pruefenden Datenquelle vertraut, prueft nichts.
    Behoben an der Wurzel:
    -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
    [bom.csv, jlcpcb_bom.csv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]
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2026-07-31 OLED-Einrichtung scheiterte am Bau von lgpio (swig fehlte)
    Auf Silvios Pi brach die Installation ab:
    building '_lgpio' extension
    swigging lgpio.i to lgpio_wrap.c
    error: command 'swig' failed: No such file or directory
    ERROR: Failed building wheel for lgpio
    adafruit-blinka zieht lgpio nach, und pip baut das Rad aus dem Quellcode.
    Dafuer braucht es swig und die Python-Header. Raspberry Pi OS liefert lgpio
    aber laengst als fertiges Paket python3-lgpio — gebaut werden muss also gar
    nichts.
    Behoben:
    * apt installiert python3-lgpio und python3-pil vorab. Fehlt eines davon auf
    einer Ausgabe, ist das kein Abbruch: swig und die Header kommen mit, dann
    baut pip eben doch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
2026-07-31 Absturzbericht: Datentraeger-Anbindung und SMART aufnehmen
    Auf Silvios Pi meldete die Shell "sudo: Input/output error" — der Rechner
    konnte eine Programmdatei nicht mehr von der Wurzelpartition lesen. Die liegt
    auf einer per USB angebundenen SATA-SSD.
    Faellt diese Anbindung weg, ist die Maschine augenblicklich tot und kann
    nichts mehr protokollieren. Genau so sahen alle bisherigen Ausfaelle aus:
    sofortiger Abriss, keine Kernelmeldung, kein sauberes Herunterfahren.
    Der Bericht erfasst jetzt Wurzeldateisystem, Datentraeger, dessen Anbindung
    (USB/SATA/NVMe), den USB-Bridge-Chip, die SMART-Werte (soweit das Gehaeuse sie
    durchreicht) und die Zahl der Lesefehler im Kernelpuffer.
    Co-Authored-B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
2026-07-31 Austauschdateien nach /run statt auf die Platte
    Silvios Pi meldete "sudo: Input/output error" — die Wurzelpartition auf der
    per USB angebundenen SSD war nicht mehr lesbar. Das erklaert die Ausfaelle
    besser als alles, was wir bisher verdaechtigt hatten: sofortiger Abriss, keine
    Kernelmeldung, kein sauberes Herunterfahren. Zum Protokollieren braeuchte der
    Rechner genau die Platte, die gerade weg ist.
    Unabhaengig von der Ursache gehoert Folgendes korrigiert: Die Farbe der LED,
    der Anzeigezustand und der zuletzt gezeichnete Framebuffer lagen unter
    /var/lib und damit auf der Platte. Das sind keine Daten, sondern Zurufe
    zwischen Prozessen — und die Zustandsdatei wird bei JEDER Wertaenderung n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
    [oled.py]
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2026-07-31 Mitschnitt: Pulsschlag, damit Stille etwas bedeutet
    Der Mitschnitt hatte eine Luecke: Ein untaetiger Kernel sagt nichts. Faellt
    der Pi nachts um drei aus, waere die letzte empfangene Zeile womoeglich vom
    Vorabend — man wuesste weder, wann er starb, noch ob der Mitschnitt ueberhaupt
    noch lief. Genau die Unterscheidung ist aber der Zweck der Uebung.
    Eine Zeile pro Minute schliesst das: Der letzte Puls datiert den Ausfall auf
    die Minute genau. Mitgeschickt wird, was im Ernstfall zaehlt — Laufzeit, Last,
    Temperatur und die Drossel-Meldung des Chips. Steigt eines davon vor dem
    Abriss auffaellig, steht die Ursache im Mitschnitt statt in einer Vermutung.
    Der Timer wird von netconsole-einricht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
2026-08-01 CLI: 'asksin-analyzer token' zeigt den Auth-Token
    Der Token steht nur in der Konfiguration — die Weboberflaeche zeigt ihn
    absichtlich nicht her, wenn er im Browser nicht schon hinterlegt ist. Genau
    deshalb sucht man ihn irgendwann wieder, und bisher hiess die Antwort
    "grep in einer JSON-Datei".
    Gelesen wird mit einem JSON-Parser statt mit grep: Ein Token darf Zeichen
    enthalten, an denen ein Suchmuster zerbricht, und der Wert soll ohne
    Anfuehrungszeichen und Komma herauskommen. Fehlen die Leserechte, startet der
    Befehl sich selbst per sudo neu — aber nur dann. Fehlt die Datei, kommt die
    klare Meldung, statt erst nach dem Passwort zu fragen und anschliessend "gibt
    es nicht" zu sagen.
    Gep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
2026-08-01 Installer und Update: Langzeitdaten anbieten, Units maschinell pruefen
    install.sh fragt beim Einrichten nach — aber nur auf dem Master und nur auf
    Hardware, die es traegt. Die Frage gar nicht erst zu stellen ist ehrlicher,
    als sie zu stellen und hinterher abzulehnen; steht zu wenig zur Verfuegung,
    sagt der Installer, was fehlt und dass sich das nachruesten laesst.
    Die Rolle landet in config.json, damit Core und Einrichtungsskript dieselbe
    Quelle lesen.
    Schlaegt die Einrichtung fehl, bricht der Installer NICHT ab: Der Analyzer
    ist dann fertig und laeuft, nur die Zusatzoption fehlt — und die laesst sich
    in der Weboberflaeche nachholen.
    Dazu tools/pruefe-units.sh. Gestern wurde die OLED-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
2026-08-01 Handbuch und README: Langzeitdaten vor Ort dokumentiert
    Kapitel 19 bekommt zwei Abschnitte:
    19.3 beschreibt die lokale Variante samt der beiden Bedingungen — nur auf dem
    Master, nur ab Pi 4 mit 2 GB — und sagt dazu, WARUM sie gelten, nicht nur
    DASS. Ausserdem: Eine bereits eingestellte externe InfluxDB wird nicht
    angetastet; sie stillschweigend umzuleiten waere die falsche Art von
    Hilfsbereitschaft.
    19.4 stellt die acht Ansichten und vier Alarme vor, jeweils mit der Frage, die
    sie beantworten — eine Liste von Namen haette niemandem geholfen. Dazu der
    Hinweis, dass der Kontaktpunkt fuer die Alarme einmal einzutragen ist:
    Zugangsdaten dafuer gehoeren nicht in ein oeffentliches Projekt.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
2026-08-01 Alarmziele: Testknopf, sichtbare Geheimnisse, kein haengender Fortschritt
    Drei Punkte aus dem Betrieb.
    1) "wird uebernommen" blieb stehen. Zwei Ursachen, beide behoben:
    - Die Oberflaeche fragte nur beim Laden der Seite nach. Jetzt fragt sie
    alle zwei Sekunden nach, solange etwas laeuft, und hoert danach auf.
    - Der Anstoss wird vom Root-Helfer entfernt. Fehlt dessen Path-Unit — weil
    das Geraet die Aktualisierung noch nicht gesehen hat —, blieb die Datei
    liegen und die Anzeige haing fuer immer. Nach zehn Minuten ist das kein
    Laufen mehr, sondern ein Haenger; er wird jetzt benannt, samt dem Befehl,
    der ihn behebt.
    2) Geheimnisse sind wieder nachschlagbar. SM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
2026-08-01 v0.12.1: Der Versionsbefund wird auch im guten Fall ausgesprochen
    Silvio: "Eine direkte Bestaetigung, dass Adapter und Analyzer zueinander
    passen sehe ich nicht."
    Zu Recht — ich hatte nur den schlechten Fall behandelt. Bei passenden
    Fassungen sagte der Test gar nichts, und Schweigen ist mehrdeutig: "geprueft
    und in Ordnung" sah genauso aus wie "konnte nicht pruefen". Wer wissen will,
    ob zwei Fassungen zusammenpassen, braucht eine Antwort, nicht die Abwesenheit
    einer Warnung.
    Jetzt gibt es drei Befunde, und alle drei stehen im Ergebnis:
    ✓ Adapter 0.0.2 und Analyzer 0.12.1 passen zueinander (noetig waere
    Adapter ab 0.0.2).
    ⚠ Der ioBroker-Adapter meldet Version 0.0.1, gebraucht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
2026-08-01 Handbuch: drei Unterkapitel fielen durch jedes Raster
    "Eine Telegrammzeile lesen" begann bei 80 Prozent der Seitenhoehe und wurde
    gleich nach dem ersten Satz zerrissen. Die Umbruchregel haette das verhindern
    muessen — sie griff nur nicht.
    Der Grund: Die Ueberschrift war ein <h2> OHNE Nummer. umbrueche.py erkennt
    Unterkapitel an ihrer Nummer, pruefe_nummerierung.py ebenso. Was keine hat,
    sehen beide nicht. In Kapitel 1 und 2 waren drei Ueberschriften nie
    durchnummeriert worden, und genau die fielen aus jeder Regel heraus.
    Behoben in drei Schritten:
    - Die drei bekommen ihre Nummern (1.1, 2.1, 2.2) und Sprungmarken. Damit
    gelten sie wie alle anderen.
    - Eine unnummerierte Unterueberschrif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
2026-08-01 Handbuch: Tabellenkopf stand allein am Seitenfuss
    Auf Seite 47 endete die Seite mit der Kopfzeile "Panel | Inhalt | Details",
    die Tabelle selbst begann auf Seite 48. Eine Kopfzeile ohne Tabelle darunter
    sagt gar nichts — der Leser blaettert um und muss sich merken, wie die
    Spalten hiessen.
    Der saubere CSS-Weg waere `break-after: avoid` auf thead und
    `break-before: avoid` auf der ersten Datenzeile. WeasyPrint setzt beides in
    Tabellen nicht um; ich habe es eingebaut, gemessen und wieder verworfen.
    Was zuverlaessig wirkt, ist ein erzwungener Umbruch. umbrueche.py misst
    deshalb im fertigen Satz nach, welche Kopfzeile als Letztes auf ihrer Seite
    steht, und schiebt DIESE Tabelle auf die naechs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
2026-08-01 v0.12.2: Handbuchsatz auf WeasyPrint, drei Layoutfehler behoben
    Handbuch inakzeptabel." Drei Maengel, alle behoben und alle maschinell
    festgenagelt.
    1) Der Fusssteg verdeckte Text. Gemessen: Der Satzspiegel endete bei 768 pt,
    der Steg sass bei 747 bis 756 — also MITTEN im Textbereich, waehrend
    darunter 26 mm Rand ungenutzt blieben. Chromium setzt fest positionierte
    Elemente zwingend innerhalb des Satzspiegels ab; ein negativer Versatz
    liess die Zeile auf die naechste Seite umlaufen. Es gab dort keinen Weg.
    Gebaut wird deshalb mit WeasyPrint, das CSS-Seitenraender beherrscht. Der
    Steg sitzt je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
2026-08-02 Alarme: Meldung bleibt eindeutig, auch wenn die Abfrage scheitert
    Silvio bekam per Telegram:
    ⚠️ DatasourceError
    [no value] sendet zu viel ([no value] %)
    Zwei Fehler in einer Meldung.
    Der eine: "DatasourceError" heisst, dass die ABFRAGE gescheitert ist, nicht
    dass ein Wert ueberschritten wurde. Grafana schickt dann trotzdem die
    Annotationen der Regel — aber ohne Daten, und jeder Platzhalter faellt auf
    "[no value]" zurueck. Die Meldung sagte damit gar nichts mehr.
    Jede summary beginnt jetzt mit KLARTEXT: "Duty-Cycle ueber 80 %", "Analyzer
    offline". Einzelheiten kommen nur dazu, wenn es sie gibt. Selbst eine
    gescheiterte Abfrage nennt damit noch die betroffene Regel.
    Der andere: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
2026-08-20 Ein Grafana-Dashboard konnte den Master lahmlegen
    Der Betreiber hat den Ausloeser gefunden: Das Dashboard "Funkqualitaet"
    aufrufen genuegt. Damit war der Ausfall von heute Mittag reproduzierbar — und
    meine erste Ferndiagnose ("Wurzeldateisystem weg, Strom aus und wieder an")
    war falsch. Der Rechner liess sich sauber mit `sudo reboot` neu starten; das
    Protokoll zeigt ein ordentliches Herunterfahren.
    ## Was wirklich passiert ist
    Der Minutenpuls des Analyzers lief die ganze Zeit weiter und hat es
    aufgezeichnet:
    13:53 load 0,19 normal
    13:58 load 4,15
    14:00 load 8,80
    14:04 load 16,34 auf vier Kernen
    14:06 load 11,99 Puls nur noch alle 104 s statt 6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
    [pruefe-dashboard-last.py]
2026-08-20 contains() war die Ursache — und Funkqualitaet wird zu zwei Ansichten
    Der Takt aus 1.0.11 hat den Ausfall gebremst, nicht behoben. Beim Umbau der
    Dashboards kam die eigentliche Ursache heraus.
    ## Faktor 64 an derselben Abfrage
    |> filter(fn: (r) => contains(value: r.standort, set: [...])) 12 731 ms
    |> filter(fn: (r) => r.standort =~ /^(...)$/) 236 ms
    Beide liefern 89 111 Zeilen. InfluxDB kann Vergleiche auf Etiketten in die
    Speicherschicht hineinschieben — aber nur als == oder =~ im filter(). Ein
    contains() ist eine gewoehnliche Funktion und muss ausserhalb ausgewertet
    werden: Die Datenbank liest ZUERST alles und wirft danach weg.
    Bei einem einzelnen Ger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
    [pruefe-flux-pushdown.py]
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2026-08-21 Meine Korrektur hatte die Alarmregel unuebersetzbar gemacht
    Der Betreiber hat gefragt, warum der DatasourceError immer noch kommt. Weil
    ich ihn beim Beheben durch einen schlimmeren ersetzt hatte.
    ## Was passiert ist
    Am 20.08. habe ich die Regel "Grundrauschen dauerhaft erhoeht" repariert und
    die Begruendung DIREKT IN die Flux-Abfrage geschrieben — mit '#' am
    Zeilenanfang, so wie in YAML, Shell und Python. Flux kennt kein '#'; der
    Kommentar dort heisst '//'.
    compilation failed: error @7:3-7:4: invalid statement: #
    472-mal in zwanzig Stunden, alle fuenf Minuten, gemeldet als derselbe
    DatasourceError wie zuvor. Vorher hat die Regel still falsche Ergebnisse
    verworfen — danach lief si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
    [pruefe-flux-syntax.py]
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2026-08-21 Der DatasourceError: wide series statt long
    Der Betreiber hat den Fehlertext aus Grafana geholt — den, den Grafana
    nirgends protokolliert:
    [sse.readDataError] [A] got error: input data must be a wide series
    but got type long
    Damit ist es aufgeklaert, und es war nie ein Analyzer.
    ## Die Ursache
    Grafanas Ausdrucksauswertung (reduce, threshold) verlangt eine WIDE SERIES:
    Zeitspalte, eine Zahlenspalte, Etiketten als Gruppenschluessel. Kommen mehrere
    Textspalten mit, haelt Grafana das Ergebnis fuer eine LONG SERIES und bricht
    ab — ohne eine Zeile ins Protokoll zu schreiben.
    Es ist DIESELBE Unterscheidung wie beim `duplicate` einen Tag zuvor, nur mit
    umgekehrtem Vorzeichen:
    l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
    [pruefe-alarm-form.py]
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

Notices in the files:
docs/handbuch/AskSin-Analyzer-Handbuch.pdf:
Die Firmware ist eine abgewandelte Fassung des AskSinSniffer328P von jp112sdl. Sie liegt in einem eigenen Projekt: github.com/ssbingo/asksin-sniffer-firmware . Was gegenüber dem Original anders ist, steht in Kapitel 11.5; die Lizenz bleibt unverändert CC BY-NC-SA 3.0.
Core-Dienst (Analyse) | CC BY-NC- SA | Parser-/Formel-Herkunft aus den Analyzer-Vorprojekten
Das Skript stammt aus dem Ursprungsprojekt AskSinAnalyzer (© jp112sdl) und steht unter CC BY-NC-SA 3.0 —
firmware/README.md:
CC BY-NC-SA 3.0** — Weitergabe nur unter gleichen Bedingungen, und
